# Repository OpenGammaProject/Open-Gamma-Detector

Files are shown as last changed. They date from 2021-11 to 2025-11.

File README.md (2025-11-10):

<a href="https://certification.oshwa.org/at000008.html" title="Open Source Hardware Association Certificate">Open Source Hardware Association Certificate</a>

# Open Gamma Detector

---

**This is the latest hardware revision 4.2 using the Pico 2! For older revisions, please have a look at the [other branches](https://github.com/OpenGammaProject/Open-Gamma-Detector/branches). A comparison between the 4.0 and 3.x hardware can be found [here](https://hackaday.io/project/185211-all-in-one-gamma-ray-spectrometer/log/225597-revision-40-status-report).**

**This project is also on [Hackaday.io](https://hackaday.io/project/185211-all-in-one-gamma-ray-spectrometer), where I post important project updates and other announcements!**

Open hardware for a hackable gamma spectrometer all-in-one device using a popular NaI(Tl) scintillation crystal and a silicon photomultiplier (SiPM). Extremely affordable design for a powerful DIY gamma spectroscopy setup with a total parts cost of around 200 USD if you get all the individual parts and assemble them on your own.

The detector uses a standard serial-over-USB and hardware UART connections so that it can be integrated into as many other projects as possible, for example data logging with a Raspberry Pi, weather stations, Arduino projects, etc. It includes both scintillation counter and multichannel analyzer (MCA) functions depending on how you want to use it.

<p align="center">
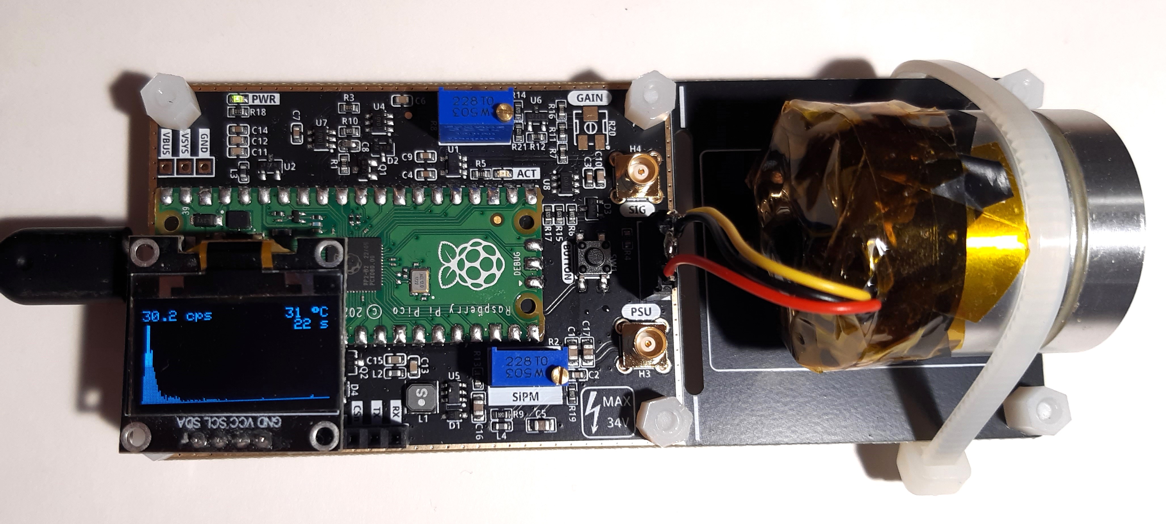
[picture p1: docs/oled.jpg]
Photo of the detector board with mounted SiPM, crystal and OLED
  
  <br>
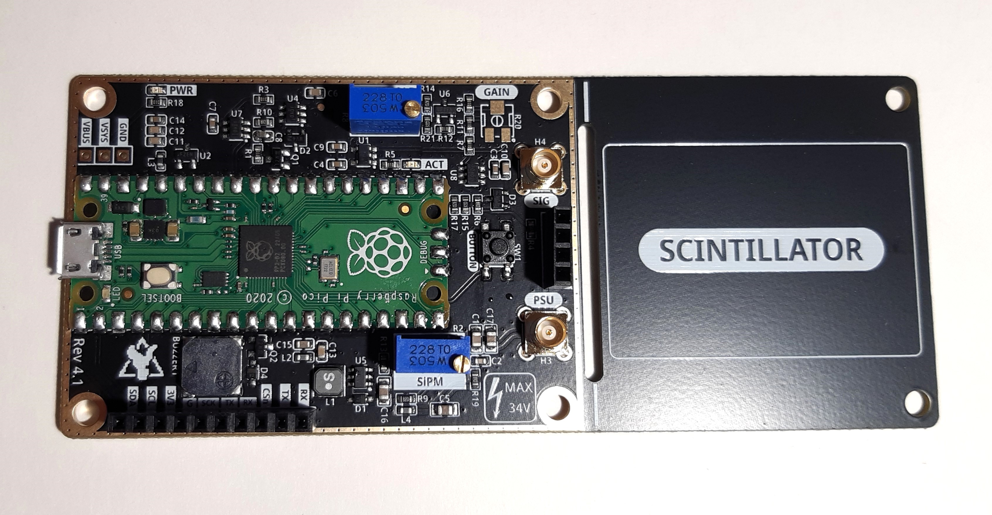
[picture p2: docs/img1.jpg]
Photo of the detector board
  
</p>

If you want a more barebones version of the Open Gamma Detector to only count pulses or similar, you can have a look at the [Mini SiPM Driver](https://github.com/OpenGammaProject/Mini-SiD) board.



## Features

Here are some of the most important specs:

- Compact design: Total size 120 x 50 mm. Approx. 70.5 x 50 mm area for electronics and additional 49.5 x 50 mm to mount a scintillator.
- All-in-one: No external parts (e.g. sound card) required to record gamma spectra.
- Standalone spectra recordings on built-in flash.
- Easily programmable using drag-and-drop firmware files or the standard Arduino IDE.
- Low-voltage device: No HV needed like with photomultiplier tubes.
- Can use SiPMs in the voltage range of 27.5 V to 33.8 V.
- 4096 ADC channels with built-in 3 V voltage reference.
- Energy resolution of up to 7% @ 662 keV possible; highly dependent on your SiPM/scintillator assembly.
- Energy Mode: ~10 µs total dead time while measuring energy (default settings).
- Geiger Mode: ~1 µs total dead time without energy measurements (default settings).
- Low power consumption: ~15 mA @ 5 V with default firmware at normal background.
- Built-in ticker (buzzer) for audible pulse count rate output.
- Additional broken-out power pins and I2C, SPI and UART headers for custom parts (e.g. display, µSD card, etc.).
- Simple OLED support out of the box (SSD1306 and SH110x).
- Built-in True Random Number Generator.

## How To Get One

PCB from PCBWay (https://www.pcbway.com/project/shareproject/Open_Gamma_Detector_84fb290d.html)

- You can check out the project on PCBWay (affiliate) and if you buy through their service, it supports the project a little, and doesn’t cost you anything extra.
- For quick access and purchase of all the parts (PCB and BOM), you can use [Kitspace](https://kitspace.org/opengammaproject/open-gamma-detector) (non-affiliated).
- Otherwise, use a PCB manufacturer and an electronics distributor of your choice and proceed on your own. All the files you'll need can be found in this repo.
- If you don't want to deal with all of that, feel free to contact me. Just send me an e-mail if you want and we'll figure something out.

**You will also need to buy a SiPM (e.g. the MICROFC-60035-SMT-TR) and scintillator (NaI(Tl) recommended) separately at a distributor of your choice.** You might also want to grab one of the countless SiPM breakout boards I made.

## Working Principle

Here is a nice flow chart to describe how the device roughly works:

Working Principle Flow Chart

## Hardware

Hardware design has been done with [EasyEDA](https://easyeda.com/) and all the needed files for you to import the project as well as the schematic can be found in the `hardware` folder. There is also a Gerber file available for you to go directly to the PCB manufacturing step.

Detailed information about the hardware of the detector as well as the potentiometer settings and assembly can be found in the [hardware directory](/hardware/).

## Software

The software aims to be as simple as possible to understand and maintain. To achieve this I decided to use an off-the-shelf microcontroller - the [Raspberry Pi Pico 2](https://www.raspberrypi.com/products/raspberry-pi-pico-2/). This board can be programmed with the Arduino IDE over micro-USB and is powerful (dual core, fast ADC, plenty of memory, ...) enough for the purpose and also exceptionally cheap.

To program the Pico 2 and/or play around with the firmware, head to the [software directory](/software/). There you will also find documentation on the serial interface (!), display support, and much more.

## Troubleshooting and FAQ

Please have a look at [REFERENCE.md](REFERENCE.md) for some general guidance.

If this doesn't help you, feel free to reach out and create an issue or open a discussions thread.

## Example Spectra

Here is a small collection of example spectra I could make quickly without putting much effort into the detector settings (threshold, SiPM voltage, software tweaks). I'm using the [Tiny MicroFC Breakout](https://github.com/OpenGammaProject/Tiny-MicroFC-Carrier-Board) and just a single SiPM (which isn't the optimal setup actually). In addition, neither the electronics nor the scintillator and sample were shielded from EMI or background radiation whatsoever. So as you can see the detector is actually pretty robust in that regard.

Background spectrum (2h) with no samples:

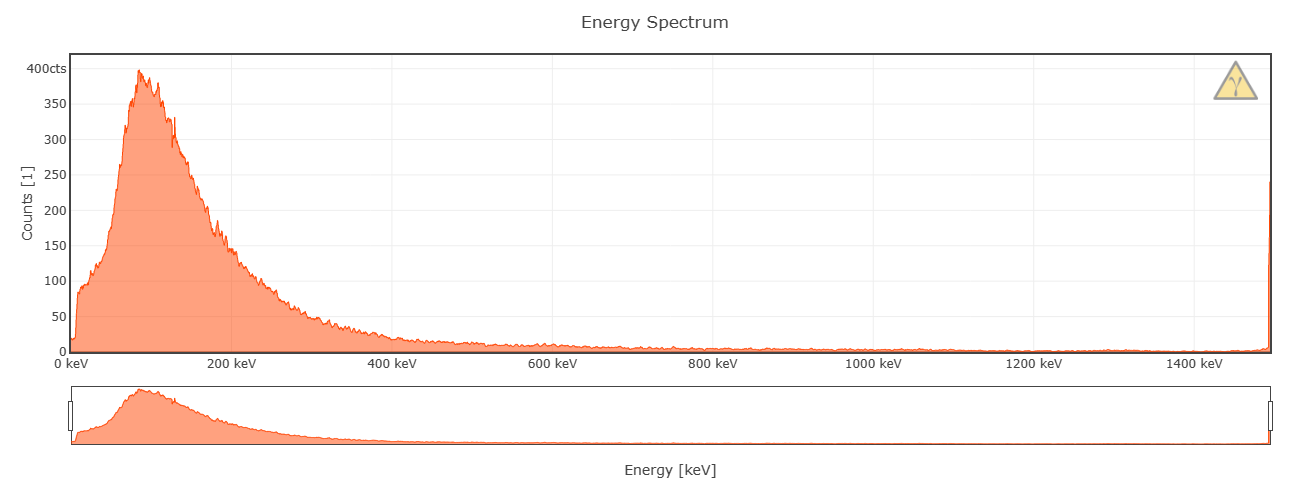
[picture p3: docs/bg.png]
Background spectrum


Spectrum (2h) of two tiny (~5 g) LYSO scintillator showing two distinct gamma peaks (201.83, 306.78 keV) with an additional ~55 keV X-ray peak. The 307 keV peak has an energy resolution of ~14% in this case:

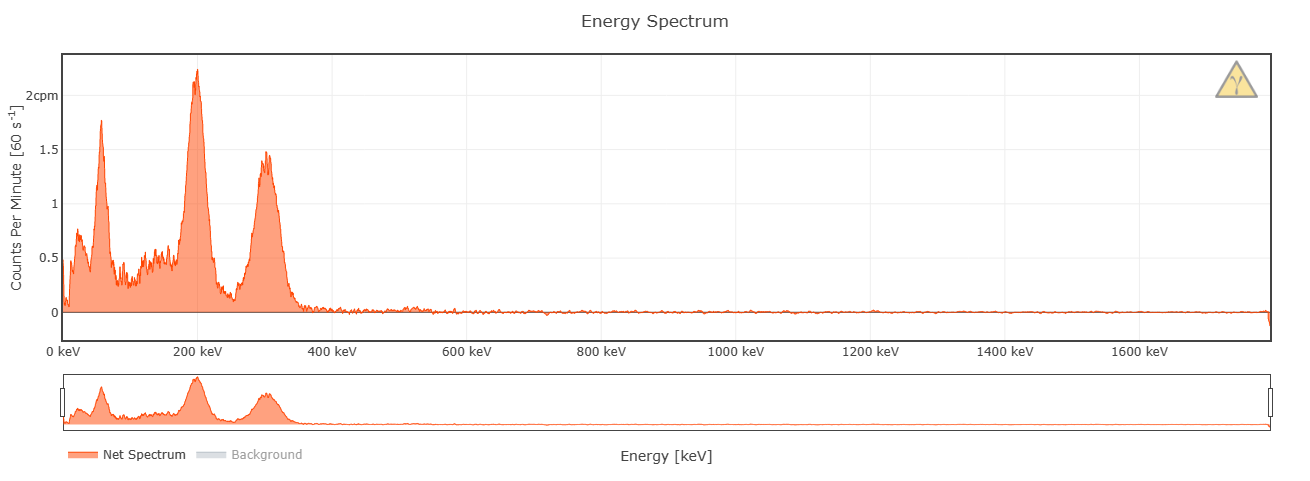
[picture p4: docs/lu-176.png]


Spectrum (5min) of Am-241 commonly used in household ionization smoke detectors (e.g. in the US, no longer in the EU). Gamma peaks at 26.34 and 59.54 keV:

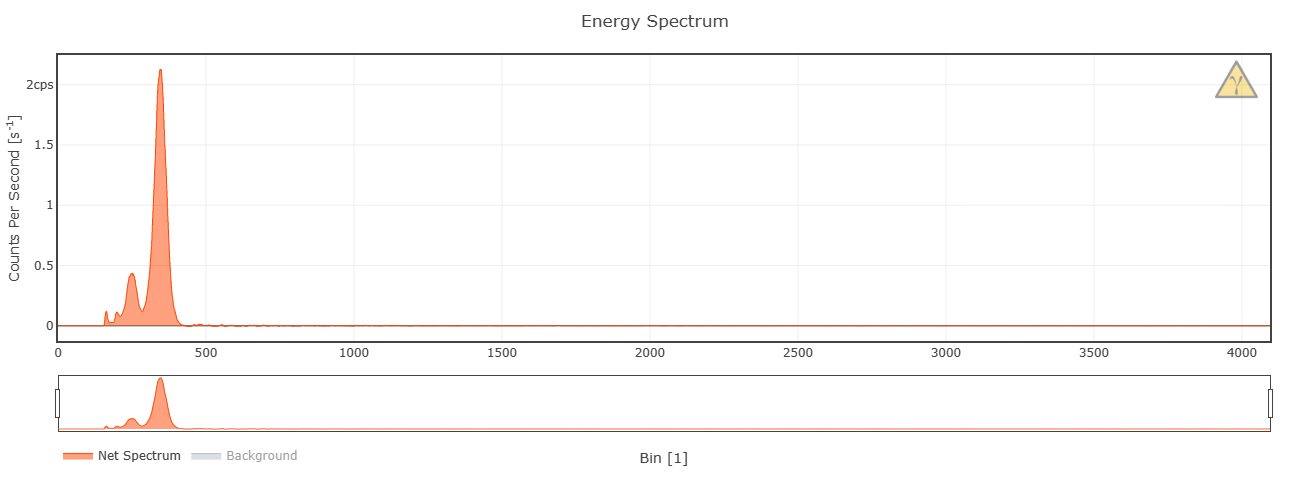
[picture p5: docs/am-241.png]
Am-176 spectrum


Spectrum (2h) of a small tea cup with pure Uraninite (also known as pitchblende) contents in its glaze. You can see all kinds of isotopes of the Uranium series including the Bi-214 peak at ~610 keV. Because they just used the pure Uraninite without any filtering whatsoever, there is also some U-235 in it and all the daughter radionuclides as well:

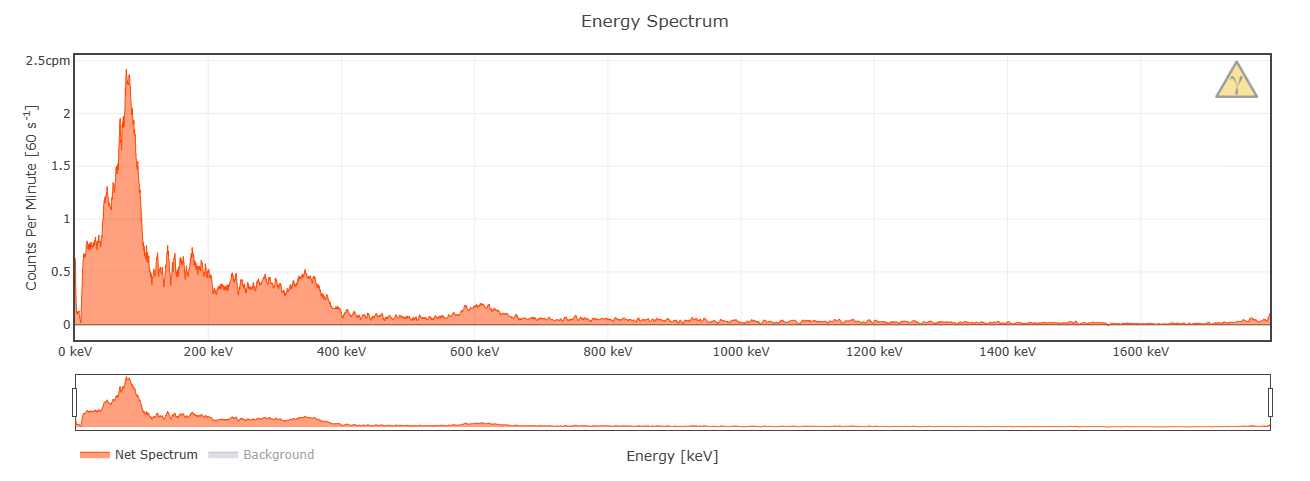
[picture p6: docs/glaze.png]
Uraninite Glaze


Spectrum (30min) of a Na-22 test source, about ~2 µCi made with a Rev.2 board (worse energy resolution than the latest version). You can see the 511 keV annihilation peak and the small 1275 keV gamma peak (much smaller due to limited NaI efficiency and small scintillator size for this energy) as well as the compton edge and continuum:

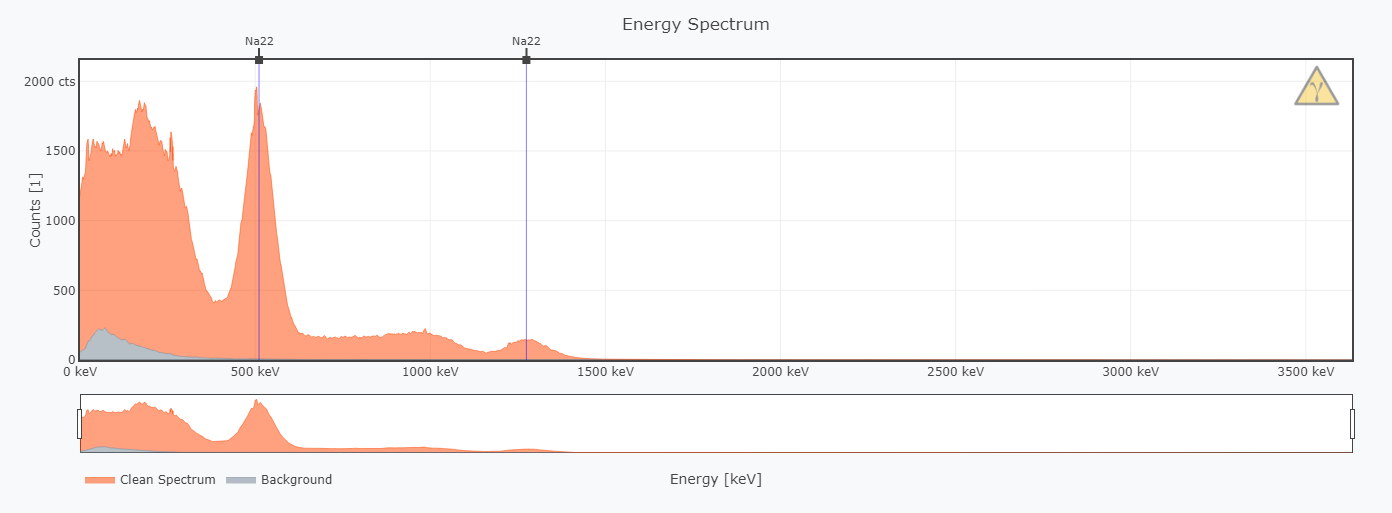
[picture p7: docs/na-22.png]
Na-22


Spectrum (2h) of about 100 grams of mushrooms still containing the isotope Cs-137 from the Chernobyl disaster. You can clearly see the gamma peak at 662 keV and the ~32 keV X-ray peak. Resolution of the 662 keV peak was ~8.6%, using only a single SiPM and an old NaI scintillator:

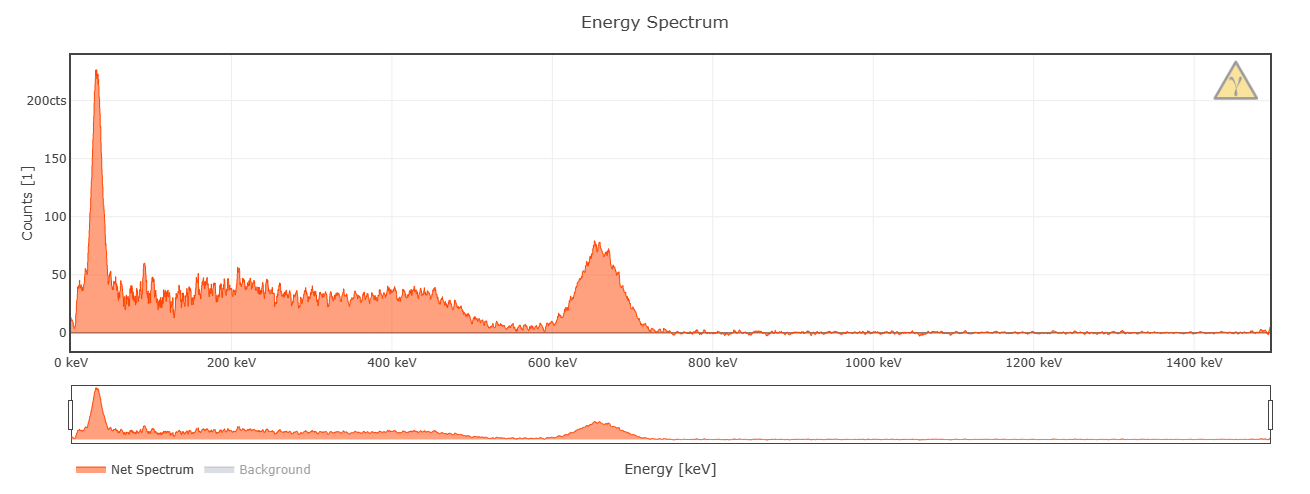
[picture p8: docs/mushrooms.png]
Mushroom "test source"


---

**Here are some of the same spectra using a larger 1x1 inch scintillator rated at 6.9% @ 662 keV and a 2x2 SiPM array:**

Spectrum (1h) of the same mushroom sample from above. This time the resolution at the 662 keV Cs-137 was 7.7%, not bad!

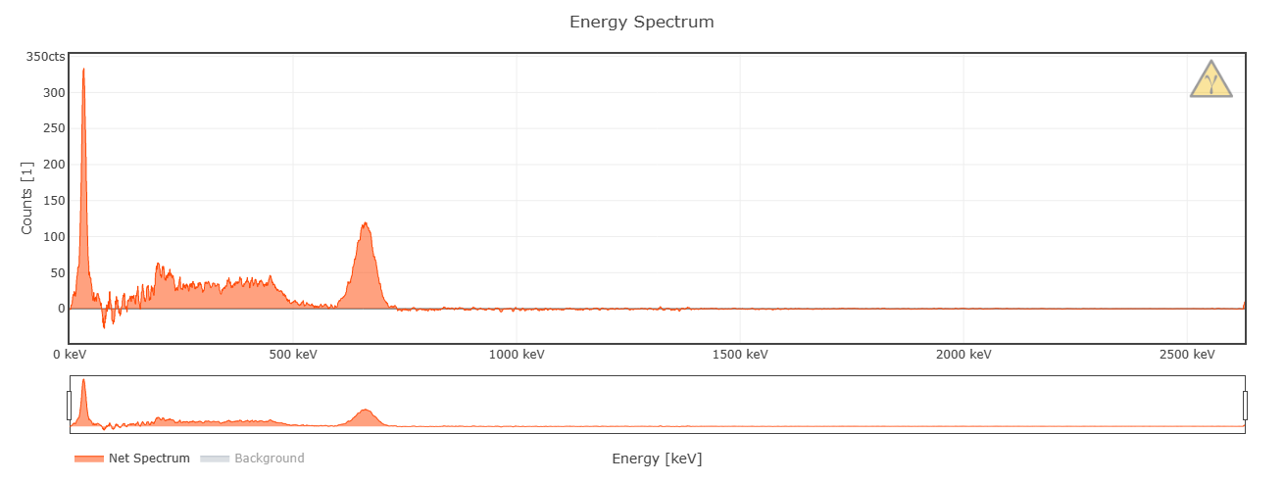
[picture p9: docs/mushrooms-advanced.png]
Mushroom "test source"


Spectrum (1h) of a small batch of Lutetium(III) oxide. It contains Lu-176 just like the LYSO scintillator sample from above. Therefore it also has the same peaks, just a lot more clear now. The 307 keV peak now has an energy resolution of 11.5%.

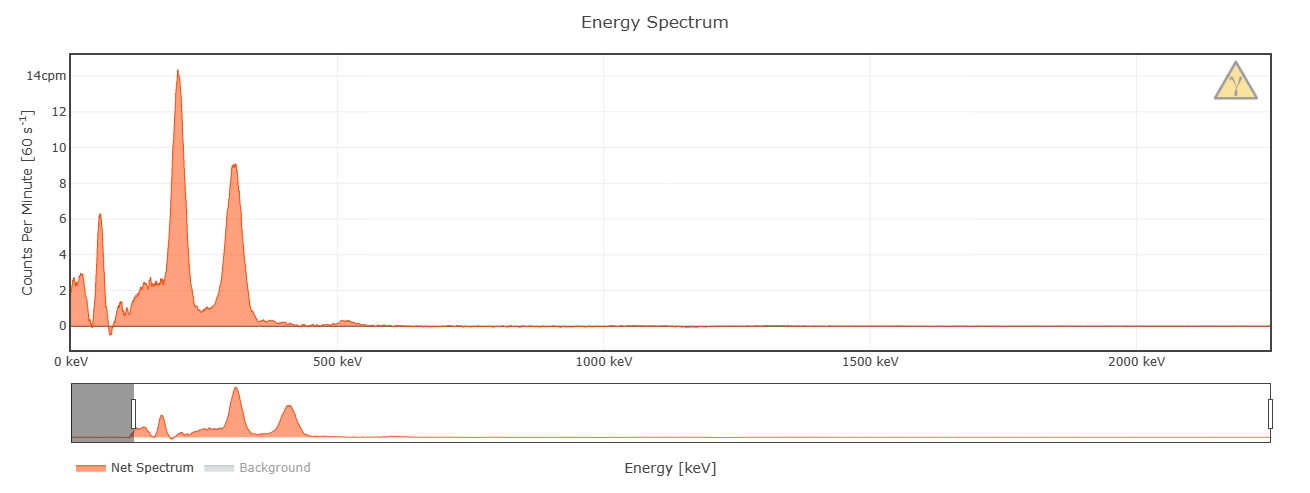
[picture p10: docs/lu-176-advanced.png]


## Known Limitations

1. ~~The Raspberry Pi Pico's ADC has some pretty [severe DNL issues](https://pico-adc.markomo.me/INL-DNL/#dnl) that result in four channels being much more sensitive (wider input range) than the rest. For now the simplest solution was to discard all four of them, by printing a `0` when any of them comes up in the measurement (to not affect the cps readings). You can turn this behavior off by using the `set correction` command. This is by no means perfect or ideal, but it works for now until this gets fixed in a later hardware revision of the RP2040 (wish us luck!).~~ Fixed by the Pico 2!
2. The power supply is **not** temperature corrected itself, meaning changes in the ambient temperature with a constant voltage affect the gain of the SiPM. This will naturally result in a different DC bias, energy range and S/N ratio. This effect is negligible around room temperature, though. The temperature dependence of the gain is -0.8%/°C (21°C) for the MicroFC SiPMs. **The latest [MicroFC SiPM carrier board](https://github.com/OpenGammaProject/MicroFC-SiPM-Carrier-Board) has automatic temperature compensation on-board however! So use that if you want to get the best performance out of it.**

## Some Ideas

### Coincidence Measurements

Using multiple detector boards with some firmware modifications it should be theoretically possible to implement a coincidence measurement feature. By respectively connecting the `VSYS`, `GND` and one of the broken-out pins to each other on both boards you have everything you need to get started. The pins would be used for an interrupt from the child detector to the parent to trigger a pulse if both timings coincide.

At the moment, though, I couldn't get a coincidence mode feature running due to some weird timing issues. There might be a firmware update in the future to implement this feature. If you have any ideas, let me know!

### Cooling the SiPM

During operation all the electronics including the SiPM naturally heat up ever so slightly. Due to the detector board (where most of the power is dissipated) not being directly connected to the SiPM self-heating is negligible, though. Therefore air or water cooling alone won't improve performance considerably, because it won't heat up much above ambient temps, if at all that is. However, you could cool the SiPM PCB with a Peltier module to sub-ambient temperatures. According to the [datasheet AND9770 (Figure 27)](https://www.onsemi.com/pub/Collateral/AND9770-D.PDF) every 10°C reduction in temperature decreases the dark count rate by 50%! But be sure to correct the SiPM voltage (overvoltage) in this case as it also changes with temperature.

Note that the required breakdown voltage of the SiPM increases linearly with 21.5 mV/°C, see the [C-Series SiPM Sensors Datasheet](https://www.onsemi.com/pdf/datasheet/microc-series-d.pdf). This means that you would also need to temperature correct the PSU voltage if you wanted to use it with considerably different temperatures.

### Shielding Background Radiation

Shielding the ambient background can be done ideally using a wide enough layer of lead (bricks) all around the detector with a thin layer of lower-Z material on the inside such as copper to avoid backscattering. The SiPM and the sample can then be put into the structure to get the best measurements possible (low background).

See Wikipedia: [Lead Castle](https://en.wikipedia.org/w/index.php?title=Lead_castle&oldid=991799816)

## Related Projects

This is a list of other awesome projects that are relevant or directly related to this one:

- [OpenDosimeter](https://opendosimeter.org/): A low-cost dosimeter with open-source hardware and software inspired heavily by the Open Gamma Detector.
- [CosmicWatch](http://www.cosmicwatch.lns.mit.edu/): A neat all-in-one device to detect muons. Completely open-source and designed for university students and schools. This project was the original inspiration to start with the Open Gamma Project.
- [OpenGammaKit](https://github.com/vikulin/OpenGammaKit/): Re-design of the Open Gamma Detector hardware using KiCAD, with additionally updated software for mobile use.

Check them out and let me know what you think. Special thanks to all of the contributors and the entire community for making this possible!

---

Thanks for reading.

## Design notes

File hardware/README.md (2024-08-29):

# Hardware

_Here you can find everything you need to build yourself a detector, or more._

This project utilizes a silicon photomultiplier (short SiPM) which is way smaller and more robust than a traditional photomultiplier tube and does not need a high-voltage supply (traditionally ~1000 V).

The following 6 mm SiPMs are recommended for this project:

* **MICROFC-60035-SMT-TR**
* MICROFC-60035-SMT-TR1 (the exact same as above, however will be more expensive to purchase as sold in smaller batches to suppliers)
* AFBR-S4N66C013 (a good replacement if the above are unavailable, but already officially EOL'd, so keep that in mind)

Here are some very helpful in-depth datasheets about the particular MicroFC SiPM recommended here:

* [C-Series SiPM Sensors datasheet](https://www.onsemi.com/pdf/datasheet/microc-series-d.pdf)
* [Linearity of the Silicon Photomultiplier](https://www.onsemi.com/pub/Collateral/AND9776-D.PDF)
* [Introduction to the SiliconPhotomultiplier (SiPM)](https://www.onsemi.com/pub/Collateral/AND9770-D.PDF)
* [Biasing and Readout of ON Semiconductor SiPM Sensors](https://www.onsemi.com/pub/Collateral/AND9782-D.PDF)

The hardware consists of the main detector (hardware in this folder) which includes amplification, pulse detection and energy measurement. If you already have a SiPM/crystal assembly compatible with voltages around 30 V, you may use it with the detector board and connecting wires directly to the correct pads. Otherwise, you can use my [SiPM carrier board](https://github.com/OpenGammaProject/MicroFC-SiPM-Carrier-Board), which holds the SiPM and all the optional decoupling as well as a temperature compensation circuit for the SiPM. There is also a carrier board for the Broadcom SiPM.

The heart of the detector board is the Raspberry Pi Pico 2 which uses its ADC to measure the pulse amplitude (i.e. the energy) immediately after an event occurs starting with an interrupt. I can really recommend you reading the datasheet ~~or maybe also having a look at a deeper analysis of the Pico ADC~~ (only relevant to Pico 1), if you're interested:

* [Raspberry Pi Pico 2](https://datasheets.raspberrypi.com/pico/pico-2-datasheet.pdf)
* ~~[Characterizing the Raspberry Pi Pico ADC](https://pico-adc.markomo.me/)~~ (only relevant to Pico 1)

Here are some front and back side renders of the detector PCB. Size is about 120 x 50 mm. If you don't need the additional space to mechanically mount the SiPM/scintillator assembly to the rest of the detector board, you can just cut it off at the white line and you're left with an even smaller detector.

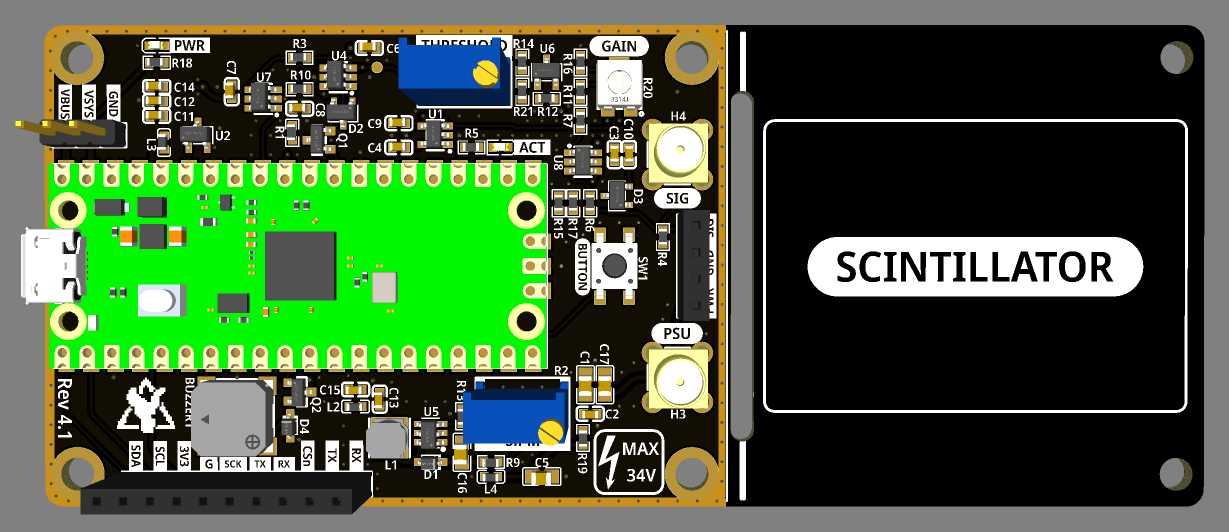
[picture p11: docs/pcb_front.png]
Front Side PCB


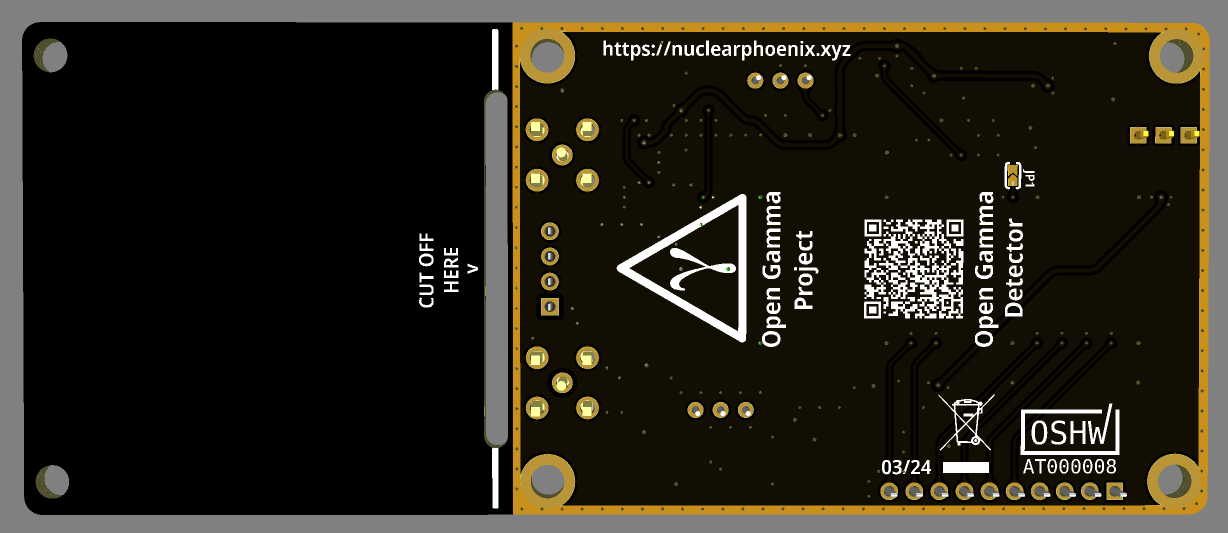
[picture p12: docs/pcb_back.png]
Back Side PCB


On the back side of the PCB there is also a jumper to connect the analog ground to the rest of the ground plane. You can solder that if you want to and you know exactly what you're doing. It's not needed, though, that's why it's open by default.

There are also broken-out pins for the power supply, I2C, SPI and UART connections. These can be used to modify the device, e.g. by adding a display or using a battery charger. You can have a look at the great [Raspberry Pi Pico 2 datasheet](https://datasheets.raspberrypi.com/pico/pico-2-datasheet.pdf) for more info on this.

Some more info on the peripheral headers can be found in the `software` section of this project.

## Pinout

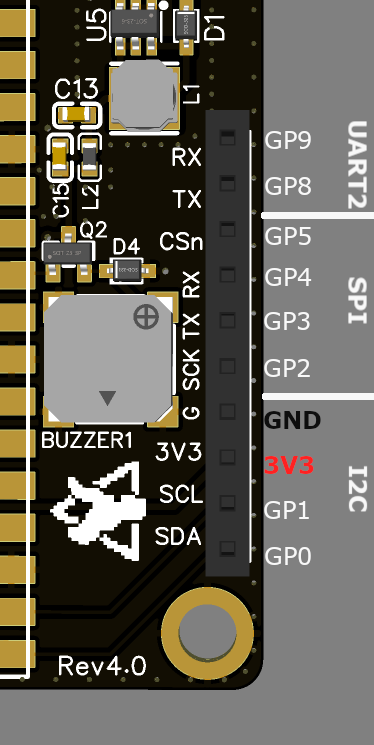
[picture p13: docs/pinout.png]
Header Pinout


You can also put a little jumper from `VBUS` to `VSYS` if you **only** want to use the detector with the USB connection on the Pico. This bridges the diode on the Raspberry Pi Pico 2 and saves you a couple of mW.

As for the **SiPM connections**, there is a female 2.54mm pin header on the board and also two MCX jacks. The pin headers are just a very easy way to get everything up and running and are fine if you're not really touching them and the scintillator is mounted very close to the header (i.e. on the PCB).

If you want to have a more secure and more importantly shielded way of connecting the SiPM, use MCX cables and the corresponding jacks on the board. There are special MCX breakout cables that have the connectors on one end and then terminate to some stranded copper wire on the other side. You can use this to solder the cable directly to the SiPM breakout board and then have the plug on the other side. However, because you need two cables (one for power and one for signal), be sure to keep them as close together as possible (e.g. twist them together) as to not create a huge ground loop area.

## Potentiometers

Here is a helpful image about the potentiometer settings for revision 4.x:

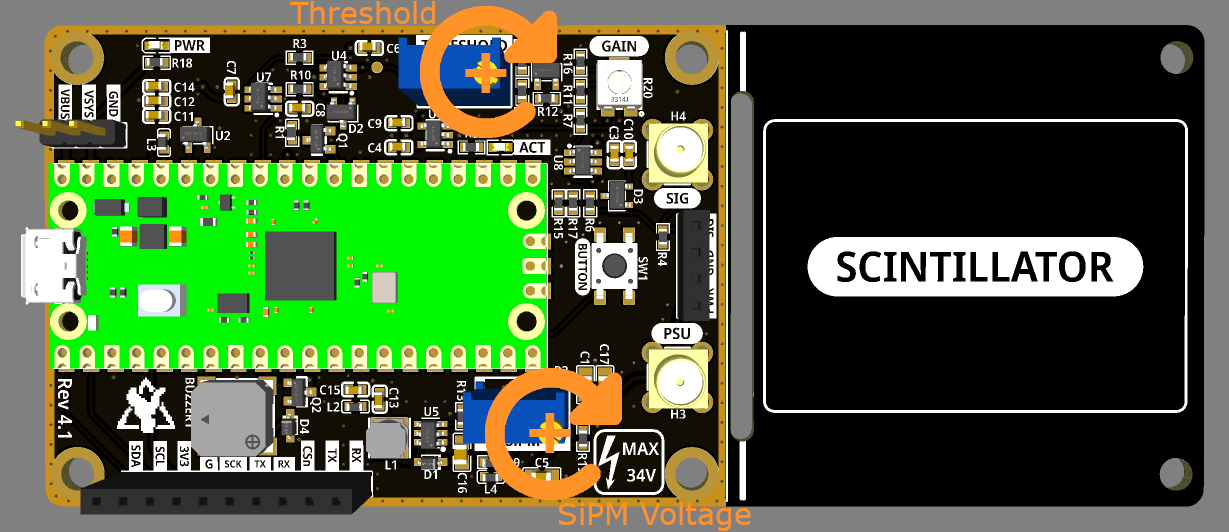
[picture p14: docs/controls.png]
Potentiometer Controls


As you can see it is pretty simple to set the required voltage and threshold. **Just turn any potentiometer clockwise to increase the corresponding parameter, turn anti-clockwise to decrease.**

## Buttons

There are two buttons on the device:

* A small one on the Raspberry Pi Pico 2 itself that is only used to reboot the device into bootloader mode. This is handy if you want to change or update the firmware of the device.
* A larger one next to the Pico that is used to toggle between spectrum and Geiger mode by **short-pressing** (<1 second) and toggling the buzzer by **long-pressing** (>=1 second) it.

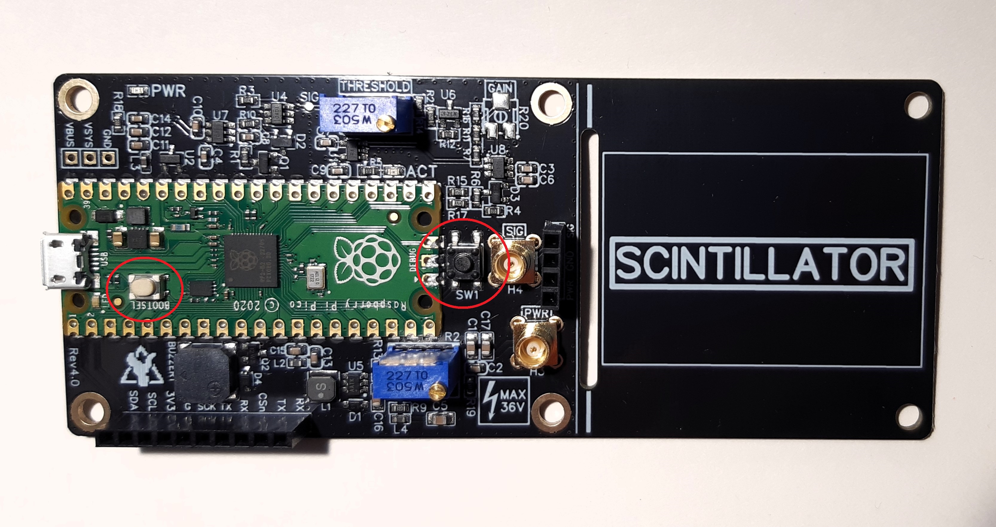
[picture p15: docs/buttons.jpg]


## Scintillator (Assembly)

The finished [standard MicroFC-](https://github.com/OpenGammaProject/MicroFC-SiPM-Carrier-Board), [tiny MicroFC-](https://github.com/OpenGammaProject/Tiny-MicroFC-Carrier-Board) and [AFBR-](https://github.com/OpenGammaProject/AFBR-SiPM-Carrier-Board) SiPM carrier boards are there to allow for easier packaging with the scintillator as well as to be reusable for different detectors as that's by far the single most expensive part and you'll want to use it as long as possible.

If you are using a larger-diameter scintillator, it's probably better for you to use something like the [MicroFC SiPM Array Board](https://github.com/OpenGammaProject/MicroFC-SiPM-Array-Board), which has a 2x2 matrix of SiPMs resulting in 4x the active area. **This will increase the energy resolution for large crystals.**

### Scintillator Cyrstals

I got most of my scintillators (used NaI(Tl), LYSO, ...) on eBay. Just search for some keywords or specific types, you'll probably find something. Just be sure to look out for signs of wear and tear like scratches on the window or yellowing (!) in NaI crystals as these can deteriorate performance significantly.

You can obviously also buy brand-new scintillators, however, these can be much more expensive. It really depends on the manufacturer there. You can get some cheap 1" x 1" NaI(Tl) scintillator from China for <100 USD.

Two sources of new NaI(Tl) scintillators are:

| Brand | Location | Comment |
|---|---|---|
| [OST - Photonics](https://www.ost-photonics.com/products/scintillation-crystal/encapsulated-scintillator/standard-type-naitl-scintillator/) | China | Can purchase directly from website |
| [Epic-Crystal](https://www.epic-crystal.com/) | China | Also sold by [GammaSpectacular](https://www.gammaspectacular.com/) |

**Since this is a fixed-gain device, I can only highly recommend you to get a scintillator that fits on the PCB and is of a comparable volume as the scintillators I tested.** I am using an 18 x 30 mm crystal for most of the spectra that you can see here and it works great. Also, due to the small size of the SiPM in comparison to the scintillator opening, try to use narrower crystals than wider ones if you can. That way, there aren't many light losses to the SiPM. In general, just be sure the volume/size is not orders of magnitue larger or smaller. If that's not possible, consider using the array board. **The array board works great with a 1" x 1" NaI(Tl) with this detector for example. There is also an optional trim pot for the gain on the Rev. 4 boards that you can solder and use to change the preamp gain.**

If the scintillator is too small, the output voltage will be very low and you might get restricted by the ADC resolution. In this case the energy range will also be much higher than you would ever need (can easily get up to 10 MeV).

If the scintillator is too large, the output voltages will be pretty high and thus decrease your energy range dramatically. The device is limited by the 3.0 V reference voltage in this case, so you might see clipping. Your mileage my vary.

**As a general rule of thumb, try to use as much of the space available on the PCB as possible to mount the scintillator and you will (in most cases) be absolutely fine.**

### Index-Matching Material For Coupling

You should apply some optical coupling compound between the SiPM and the crystal window to reduce reflections as good as possible (this way the best photon detection efficiency is achieved). There a multitude of options for optical couplants, and depending on your region some may be easier to aquire than others. As a general rule of thumb, silicone oil/grease can also be used and works fine. If it contains polydimethylsiloxane, you're on the right track. Some options:

<!---This is a good source https://www.logwell.com/tech/servtips/optical_coupling_grease.html - Sebyon --->

| Description | Brand  | Reflective Index | Viscosity (cPs)| Cost (USD) | Comment |
|---|---|---|---|---|---|
|[Index Matching Gel, 3 cc](https://www.thorlabs.com/thorproduct.cfm?partnumber=G608N3)|Thorlabs| 1.43 | 1,060,000 | $47.46 | High viscosity, works well for fibre optic coupling. |
|[Index-Matching Fluid](https://www.newport.com/f/index-matching-fluid) | Newport | 1.52 | 100 | $45.60 | Low viscosity may make setting the SiPM and crystal window difficult. However, the RI is the closer to the window properties. Use if you're experienced with assembly. |
|XIAMETER™ PMX-200 Silicone Fluid | Dow Corning | 1.40 | 60,000 - 100,000 | Depends on source | Low cost and [used in research](https://pubs.acs.org/doi/10.1021/acs.cgd.0c00256) due to performance / price. PMX-200 can come in various viscosities, try to get close to 100,000 cPs. |
|Molykote Industrial 4 Electrical Insulating Compound | Dow Corning | N/A | Grease | ~$20 | Used by Ludlum for their survey meter scintillation detectors. |

<!--- I might add some more options for achieving a hermatic seal with tape here once I start putting one together - Sebyon --->

After you applied some, you press both parts together and wrap everything with light-tight tape, again, I'm just using some black electrical tape here. That's essentially it, now you can solder some wires to the pads on the board to connect them together and secure it in place in the free space on the board.

**It's very important to get the SiPM/scintillator assembly light-tight.** Otherwise you'll either run into problems with lower energies where noise dominates or outright not measure anything at all, because the sensor is saturating (clipping signals).

**==> More assembly instructions can be found on the [Hackaday.io project page](https://hackaday.io/project/185211/instructions)!**

## The `ACT` LED

There is an additional LED on the board called `ACT` for "activity". It's directly connected to the comparator that handles the pulse thresholds and will light up for every impulse that's larger than the set threshold voltage for the duration of said impulse. That means generally you won't see much, because the count rates are pretty low and the pulses are really fast (couple of microseconds).

However, it's helpful when setting the correct threshold voltage, because as soon as you decrease it too low and completely get into the noise floor, the LED will visibly light up.

On top of that, since it's not connected to the microcontroller in any way, it's a nice backup for when the device crashes and/or the count rates get so high that it's completely saturating otherwise. **The detector will display ZERO counts per second when it saturates at very high count rates: the count rate will actually gradually go down to zero the higher and higher your ACTUAL (real) count rate is.** So if the device displays 0.0 cps, but the LED is lit up brightly, you either have a light leak or you should run for your own safety.

## 3D Printed Case

You can get a 3D-printable case for the Open Gamma Detector with different styles of covers.

All the STL files to print the two parts (main body and cover) can be found in [/enclosure](../enclosure), as well as some more info on the necessary screws and the USB extension cable.

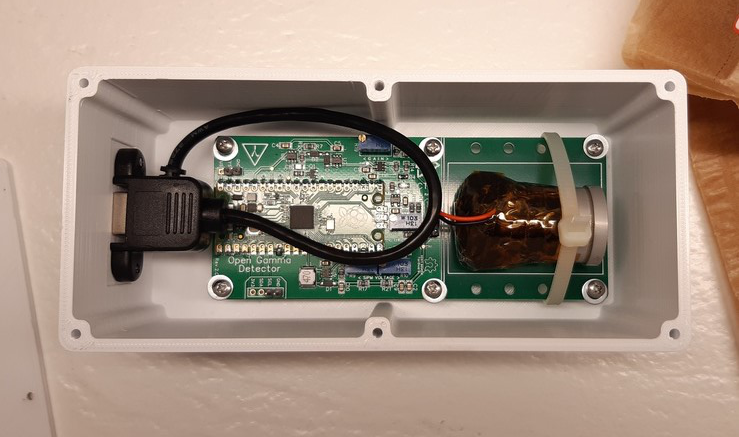
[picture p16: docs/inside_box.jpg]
Inside view of the box


(This is an old image from Revision 2.0, but the footprint is exactly the same, you get the gist.)

## Shielding

Due to the detector measuring small voltages, energy resolution being limited by noise and a small 470 pF capacitor being on board, it can sometimes be pretty sensitive to EMI. For the absolute best performance, you should put your detector into some kind of metal enclosure. It doesn't need to be a thick metal case, a tin can will most likely suffice.

<!--- Once I start assembly I'll look at proving some shielding ideas - Sebyon --->

The four screw holes on the PCB's actual detector part are connected to the circuit GND.

As some level of protection against EMI, the peak and hold capacitor is periodically discharged as to avoid it being charged ever so slightly by interference and the feedback path. This takes place every millisecond by default and cannot be switched on or off via a serial command. This adds less than 1% of additional dead time (~2.5 µs per reset every ms), so should be completely negligible.

## Raspberry Pi Pico 2 W

Since the Pico 2 W has functionally the exact same size and pinout, it can be a trivial replacement for the standard Pico 2. This can be a great place to start experimenting with connecting to the Open Gamma Detector via Bluetooth or WiFi, there are endless possibilities what you can do with that.

If you switch to the Pico 2 W, though, you will need to modify the stock firmware slightly since internal pins like the input voltage pin are changed.

There is also no firmware build for the Pico 2 W and I don't plan to make one in the near future, since I'm busy enough with the stock firmware, hardware and Gamma MCA, to start building yet another Bluetooth- or WiFi-connected app or whatever.

I'll happily accept PRs if you make something like that, though, so let me know! ;)

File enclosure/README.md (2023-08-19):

# Enclosures

In the following folders you can find different enclosures for the Open Gamma Detector.

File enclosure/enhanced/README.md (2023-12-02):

# Parts List

Here are all the parts you need to build this 3D printed enclosures. It's compatible with the Open Gamma Detector Rev. 2, 3 and 4 and also a lot more handy and smaller than the simple case.

The case is designed to fit a scintillator with a maximum size of 5 x 5 x 5 cm. The USB connection can be accessed through a hole in the front.

You can have a look at all the different designs by uploading them to [ViewSTL](https://www.viewstl.com/).

All of the design work has been done by [@sebyon](https://github.com/sebyon), many thanks!

---

<p align="center">
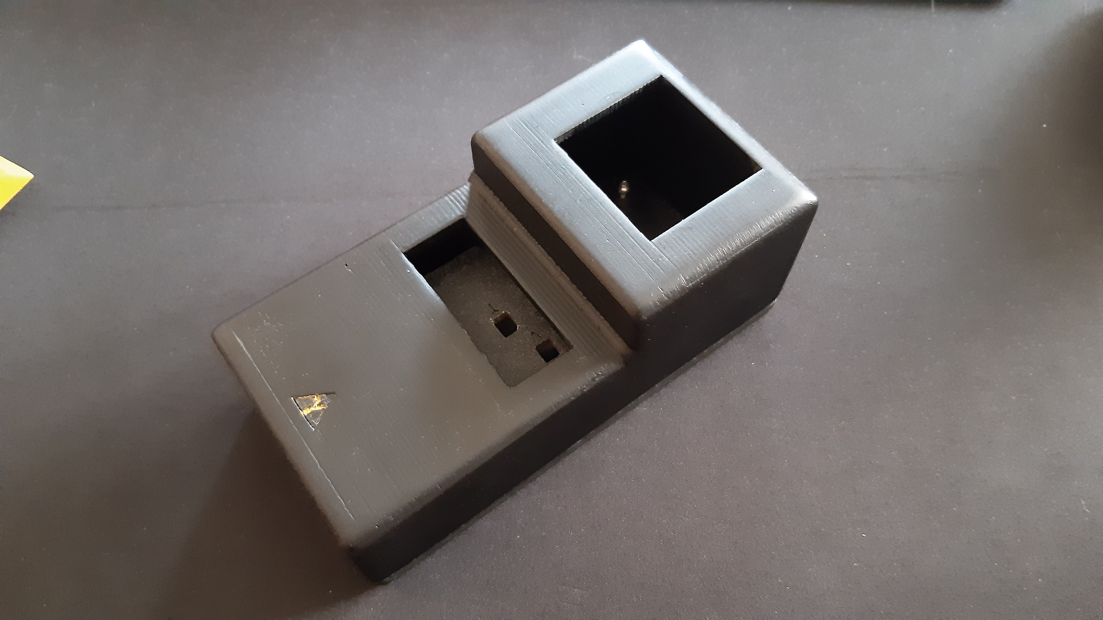
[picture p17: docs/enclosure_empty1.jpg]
	
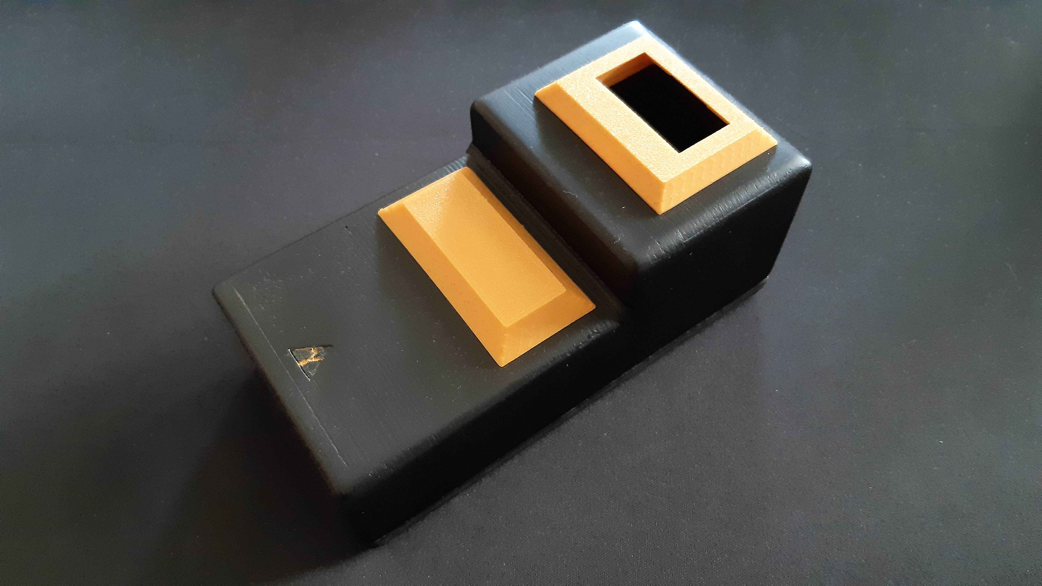
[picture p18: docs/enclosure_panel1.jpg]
	
</p>

<p align="center">
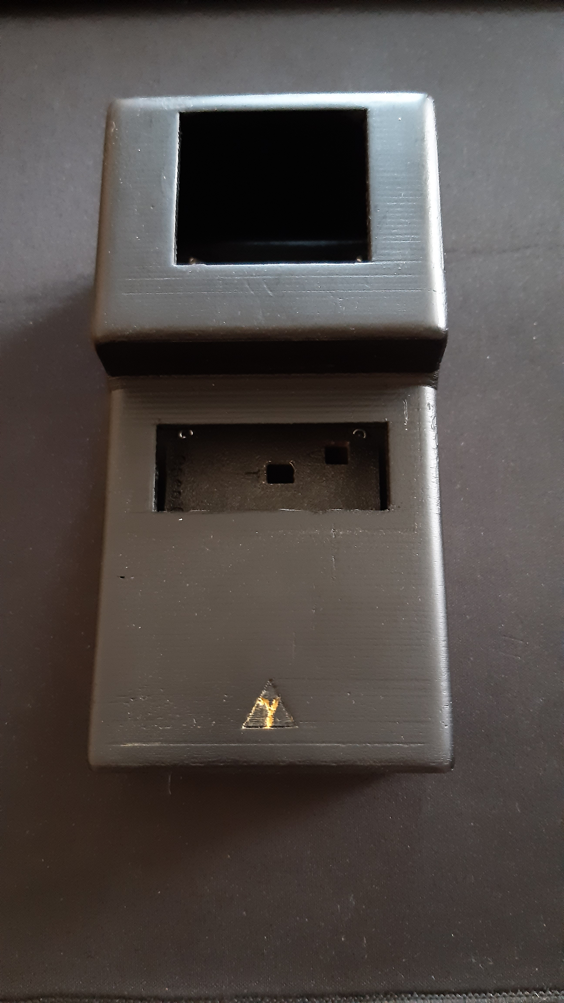
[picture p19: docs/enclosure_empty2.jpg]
	
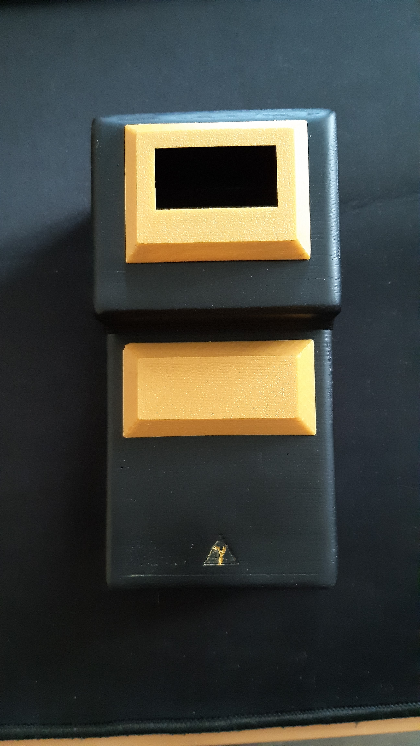
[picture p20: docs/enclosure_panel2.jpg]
	
</p>

## Main Body

These are the `Case_Lower.stl` and `Case_Upper.stl` files.

- 10 x M3\*5.7\*4.6 Threaded Heatset Inserts
- 10 x M3\*10mm screws

## Inserts

The plug-in inserts for the display and the panel/buttons are called `LCD_Bezel.stl` and `Panel_Cover.stl` respectively.

These are just friction fits and aren't screwed. The LCD cover is designed for a 1.3 inch OLED display (SH1106). The panel cover can be replaced by a custom made cover that fits your needs, e.g. for buttons.

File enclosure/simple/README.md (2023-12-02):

**For a reference 3D model, you can have a look at the `3D` folder. It contains some `mtl` and `obj` files if you want to design your own enclosure.**

# Parts List

Here are all the parts you need to build all the different 3D printed enclosures. These are all compatible with the Open Gamma Detector Rev. 2, 3 and 4.

The case is designed to fit a scintillator with a maximum size of 5 x 5 x 5 cm. The USB connection will be extended to the outside via a short USB panel mount cable.

You can have a look at all the different designs by uploading them to [ViewSTL](https://www.viewstl.com/).

All of the design work has been done by WEDBox, [box@wed.ch](mailto:box@wed.ch), many thanks!

## Main Body

### PCB Mount

6 x M3x10 mm Flat Head (not countersunk!)

### USB Panel Mount

Example: [https://www.aliexpress.com/item/4000932328047.html](https://www.aliexpress.com/item/4000932328047.html) or [https://www.aliexpress.com/item/4001250794678.html](https://www.aliexpress.com/item/4001250794678.html)

Cable Length: 30 cm

2 x M3x10 mm Flat Head (not countersunk!)

## Case Cover

### All Models

6 x M3x15 mm Countersunk Head Screw

#### Handle Variant

Example: [https://www.aliexpress.com/item/4000012656240.html](https://www.aliexpress.com/item/4000012656240.html)

Distance between holes: 96 mm

2 x M4x15 mm Flat Head (not countersunk!)

#### Window Variant

Acrylic glass, max. 1.5 mm thick, size 132x48 mm

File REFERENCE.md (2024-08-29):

# Troubleshooting and FAQ

## Troubleshooting

### My device freezes or crashes periodically

Make sure that the threshold setting is not set too low! If that's the case you should see the ACTivity LED blinking heavily or even staying on solid. The buzzer might also give you a great indication of the correct count rate setting. In this case, noise is probably overwhelming the detector and forcing it to reset.

If this is not the case for you, reflash the firmware, reset all the settings and reboot the device. If the problem persists, please feel free to open an issue on GitHub.

### My device is not recognized by my computer

Make sure you are using a micro-USB cable that can be used for data transmission! There are micro-USB cables for powering/charging devices only and they can be easily mistaken for a data cable.

If this isn't the case for you and it doesn't get recognized at all (even while holding the `BOOTSEL` button), there might be a manufacturing defect or you might have made a mistakes when soldering the parts. Feel free to get in touch if that's the case.

### Settings on the device are not saved

If you flashed it via the Arduino IDE be sure to select `Flash Size: "4MB (Sketch: 1MB, FS: 3MB)"`. Without these 64 KB of flash assigned to the file system, the Pico is unable to create and save a settings file.

### ~~I am seeing a sharp peak immediately around ADC channel 511~~

~~That is right, this is due to the DNL issues with the RP2040 ADC as described in the [Known Limitations](README.md#known-limitations) section of the readme.~~

~~This effect would have been much worse without some simple corrections in the firmware. Since there is currently no hardware fix, this is what we have to live with unfortunately. If you know about it, you can just ignore it since all the *real* peaks of the scintillator are much wider than that.~~ Fixed by the Pico 2.

### ~~There is always a peak at ADC channel 0~~

~~That is intentional behavior of the device. For the same reason as above, four ADC channels are ignored for the energy measurement.~~

~~Since this would potentially highly influence the count rate, giving lower values than there actually are, these counts are added back to the spectrum to ADC channel 0.~~

~~This way, all the counts are registered, but since there is actually never a signal near channel 0, you can clearly distinguish between the "right" spectrum and the rest.~~

~~If you want to disable this behavior, you can do so by using the  `set correction` command over the serial interface. This will still omit the ADC channel readings, but won't create another peak at 0. In geiger mode, there will always only be a channel `0` since this is how the current cps is calculated.~~  Fixed by the Pico 2.

### There is always a peak near ADC channel 4095

The ADC reference voltage is set to 3 Volts. Anything larger than that gets clipped, because the ADC cannot read higher voltages, meaning all pulses larger than 3V accumulate at the maximum ADC channel -- in this case 4095. That is completely normal behavior.

---

## FAQ

### How to update the firmware?

Press and hold the "BOOTSEL" button on the Raspberry Pi Pico while plugging it into your USB port. It will then show up in your file explorer and you can once again drag-and-drop the firmware file. This also works if your device is completely frozen or crashed.

### Can I use a plastic scintillator?

No, these cannot be used for gamma spectroscopy except in some edge cases. Generally, they have much worse efficiency than your typical inorganic scintillator, like NaI(Tl) or CsI(Tl), and extremely poor energy resolution.

If you want to *just* count pulses (i.e. **not** measure pulse energy), plastic scintillators can be a better fit, because of their really low cost. If you want to count pulses only, though, it's probably better to use the simpler and much cheaper [Mini SiD](https://github.com/OpenGammaProject/Mini-SiD) board instead of the Open Gamma Detector. With plastic scintillators you can also detect high-energy particles such as beta radiation or muons, which NaI(Tl) generally cannot.

### How do I change the gain?

Since hardware revision 3 the gain is fixed on all boards and cannot be changed without any hardware modifications. This makes it **much** easier to provide a device that has a very high chance of working out of the box without much fiddling around with pot settings or additional components.

A downside of this is that different scintillator sizes, while working most of the time now, provide slightly different energy ranges and therefore bin per energy resolutions. Normally, this shouldn't be a problem, though.

If you want to change the gain for whatever reason, you can do so by soldering the optional trim pot on the board (R20) with a [compatible pot (e.g. 5k)](https://www.lcsc.com/product-detail/Variable-Resistors-Potentiometers_BOURNS-3314J-1-502E_C58391.html). Be sure to also remove the existing 0605 resistors R7 and R11 in that case. You can then change the gain from roughly 1 to 6 on the fly.

### How do I calibrate the device?

You have to get a material with at least two known gamma peaks and calibrate the detector using these two peaks. In the Gamma MCA calibration tab you select the two peak ADC channels and assign their gamma-ray energy.

Ideally you want to use three peaks distributed evenly over your whole energy range to use the best calibration.

### Why don't you use a TIA or CSP or change X or Y?

This device is made to be as simple and cheap as possible, while still yielding as great results as possible. In effect it is a compromise to get the best price-performance ratio.

Of course, you could use transimpedance or charge-sensitive preamplifiers, however this would significantly increase complexity as you'd need additional parts for the correct power supplies and so on. Using more expensive amplifiers would surely also be an option.

If you wanted to go the maximum-performance route, you'd also need to use a different microcontroller with a much better ADC, and maybe even consider using 4-layer boards with additional ground and power planes. Essentially, you'd have to re-design the whole board at this point.

Instead of something like 8-10% energy resolution @ 662 keV (highly dependent on your SiPM/scintillator assembly), you'd then maybe get as much as 6% if you're lucky, which is the limit for most NaI or CsI scintillators anyways. That would come at a much higher cost, though. In my opinion, you get to a point of diminishing returns quickly, especially when designing an entry-level device such as this.

### Notes on different microcontrollers

The Pico 2 is readily available virtually everywhere and it's really cheap. This makes it ideal for use in this kind of "simple" and cheap project. There are a couple of reasons I like to use it. You can read more about it in the [discussions thread about switching to the ESP32](https://github.com/OpenGammaProject/Open-Gamma-Detector/discussions/43).

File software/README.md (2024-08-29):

# Software

**If you just want to program you device with all the default settings, choose one of the `.uf2` files in this directory. This will be all you need if you just want to get going!**

If you want to play around with the firmware, the Arduino sketch can be found inside `ogd_pico`. It also includes some instructions on how to program. See below for more info about that.

**Note about HW compatability:** Each hardware revision of the detector has its own major version of the Arduino sketch indicated by the leading number of the version code. The versions are only tested on their respective hardware, so they might and probably will not work with newer or older detector boards. As an example, FW **4**.0.2 is designed to only run on Rev. **4** boards, while **3**.5.2 is only designed to run on Rev. **3** boards.

## Programming the Pi Pico 2

### Firmware Files

This is the easiest way to get started! You'll not have to download anything else besides the firmware UF2 file. This is the latest default firmware that you can use if you don't plan to modify any of the hardware aspects (such as the voltage reference, ADC resolution, etc) on the board itself. You can of course also use it with the Open Gamma Detector purchased from my Tindie store.

To get started with a fresh device, plug in the Raspberry Pi Pico 2 via the micro-USB connection. A file manager window should now pop up. Drag and drop the `ogd_pico-XXX.uf2` file that you downloaded into this directory. The device will restart automatically once the transmission is completed and is ready to use!

If you want to update or re-flash the firmware, press and hold the `BOOTSEL` button on the Raspberry Pi Pico 2 _while_ plugging it in the USB port of your computer. A file manager windows should once again pop up and you can let go of the button. Drag and drop the UF2 file just like above.

### Arduino IDE

To program the Pico you will need the following board configs in the latest release of the Arduino IDE:

- [Arduino-Pico](https://github.com/earlephilhower/arduino-pico)

The installation and additional documentation can be found in the respective GitHub repo, it's not complicated at all and you only need to do it once. You will also need the following additional libraries:

- [TaskScheduler](https://github.com/arkhipenko/TaskScheduler) 
- [SimpleShell Enhanced](https://github.com/NuclearPhoenixx/SimpleShell) 
- [ArduinoJson](https://github.com/bblanchon/ArduinoJson) 
- [Adafruit_SSD1306](https://github.com/adafruit/Adafruit_SSD1306) 
- [Adafruit_SH110x](https://github.com/adafruit/Adafruit_SH110X) 
- [RunningMedian](https://github.com/RobTillaart/RunningMedian) 

They can be installed by searching their names using the IDE's built-in library manager.

Please have a look at the `USER SETTINGS` in the Arduino sketch. You might need to change the default display parameters, such as I2C address, screen width and height depending on what display you are using.

Flash the Pico by choosing the `Raspberry Pi Pico 2` under `Board: Raspberry Pi Pico/RP2040` and then selecting `Flash Size: 4MB (Sketch: 1MB, FS: 3MB)`, leaving everything else at the default value. You can then press the big `Upload` button.

You can also try to **overclock** the device if you want. You cannot destroy anything as far as I know, so be experimental. The worst thing that can happen is the Pico locking up and you needing to reflash it by holding the `BOOTSEL` button. Mine ran stable at up to 250 MHz with reduced core voltage (66% increase from stock!!!) and that will actually significantly improve the detector dead time as well. Also flashing with `-Ofast` enabled improved performance for me too. There is a more detailed comparison on this [for the Pico 1 on Hackaday](https://hackaday.io/project/185211-all-in-one-gamma-ray-spectrometer/log/213190-pico-performance-improvements), performance changes might be different for the Pico 2 though.

## Serial Interface

You can control your spectrometer using the serial interface. The following commands are available, type `help` to get a list of commands. Commands are case sensitive. Additional parameters needed for each command are surrounded by `< ... >`.

```text
> help
Usage:
	<command> [options]
Commands:
	read spectrum	: Read the spectrum histogram collected since the last reset.
	read settings	: Read the current settings (file).
	read info		: Read misc info about the firmware and state of the device.
	read fs			: Read misc info about the used filesystem.
	read dir		: Show contents of the data directory.
	read file		: <filename> Print the contents of the file <filename> from the data directory.
	remove file		: <filename> Remove the file <filename> from the data directory.
	set baseline	: <toggle> Automatically subtract the DC bias (baseline) from each signal.
	set trng		: <toggle> Either 'on' or 'off' to toggle the true random number generator output.
	set display		: <toggle> Either 'on' or 'off' to enable or force disable OLED support.
	set mode		: <mode> Either 'geiger' or 'energy' to disable or enable energy measurements. Geiger mode only counts pulses, but is a lot faster.
	set out			: <mode> Either 'events', 'spectrum' or 'off'. 'events' prints events as they arrive, 'spectrum' prints the accumulated histogram.
	set averaging	: <number> Number of ADC averages for each energy measurement. Takes ints, minimum is 1.
	set tickrate	: <number> Rate at which the buzzer ticks, ticks once every <number> of pulses. Takes ints, minimum is 1.
	set ticker		: <toggle> Either 'on' or 'off' to enable or disable the onboard ticker.
	record start	: <time [min]> <filename> Start spectrum recording for duration <time> in minutes, (auto)save to <filename>.
	record stop		: Stop the recording.
	record status	: Get the recording status.
	reset spectrum	: Reset the on-board spectrum histogram.
	reset settings	: Reset all the settings/revert them back to default values.
	reboot			: Reboot the device.
```

All of these commands should be pretty straightforward with their respective description.

### Data Output

The output data format that can be controlled with the `set out <mode>` command can be switched between two modes:

- **Events:** This will print out all the ADC channels (bins) for newly acquired pulses in a chronological order. This data needs to be processed further to generate a pulse height histogram. Each pulse bin is delimited with a semicolon `;`.

Example (4096 channels):

```text
389;874;359;626;551;651;431;3123;466;214;662;1053;467;310;713;319;3001;294;340;493;437;1836;388;
570;354;318;330;688;1343;455;1627;359;252;652;449;602;
329;796;644;414;621;449;663;2311;0;538;224;394;421;444;362;885;406;437;796;994;579;319;456;404;442;922;441;973;
315;642;549;4095;588;774;361;329;1375;499;346;615;794;361;406;4095;457;1028;468;311;321;285;435;514;585;633;670;
```

- **Spectrum:** This is a histogram of all the ADC channels (bins) and the respective number of counts per channel. Each channel is delimited with a semicolon `;` and each spectrum is printed on its own line.

Example (4096 channels):

```text
12;0;0;0;0;0;0;0;0;0;0;0;0;0;0;0;0;0;0;0;0;0;0;0;0;0;0;0;0;0;0;0;0;0;0;0;0;0;0;0;0;0;0;0;0;0;0;0;0;0;0;0;0;0;0;0;0;0;0;0;0;0;0;0;0;0;0;0;0;0;0;0;0;0;0;0;0;0;0;0;0;0;0;0;0;0;0;0;0;0;0;0;0;0;0;0;0;0;0;0;0;0;0;0;0;0;0;0;0;0;0;0;0;0;0;0;0;0;0;0;0;0;0;0;0;0;0;0;0;0;0;0;0;0;0;0;0;0;0;0;0;0;0;0;0;0;0;0;0;0;0;0;1;1;1;0;0;0;0;0;0;0;0;0;0;0;0;0;0;0;0;0;0;0;0;0;0;0;0;0;0;0;0;0;0;0;0;0;0;0;1;1;0;0;0;0;0;0;0;0;0;0;0;0;3;0;3;0;4;1;1;0;2;1;1;0;0;1;1;1;1;2;1;0;2;0;0;1;2;1;0;0;0;2;1;1;1;0;1;1;0;1;1;0;0;1;0;1;0;1;0;3;3;1;0;2;0;0;1;2;1;0;0;0;1;2;1;1;0;0;1;0;0;3;0;1;2;0;0;0;0;0;2;0;0;3;2;1;0;0;2;2;0;1;2;1;1;3;3;0;0;1;2;0;0;2;1;2;2;1;2;5;2;0;3;2;1;3;3;3;0;3;2;3;1;3;0;5;4;6;3;0;2;3;1;1;1;4;0;4;3;2;2;3;1;4;3;5;3;5;4;4;4;1;8;3;1;4;2;4;1;4;4;2;2;6;3;2;1;2;1;5;3;2;2;3;3;4;3;2;4;3;3;4;5;1;3;3;5;4;1;5;3;1;4;5;3;2;4;1;6;2;3;2;2;4;4;1;2;1;2;7;3;2;4;0;3;1;2;2;5;2;1;2;3;4;2;6;2;1;2;2;2;3;1;5;5;5;1;3;2;3;5;3;2;4;1;3;2;2;2;0;2;3;0;3;2;3;4;2;4;4;0;2;0;3;3;3;3;2;0;1;1;2;4;4;3;1;2;0;2;2;3;4;1;4;1;1;1;3;2;1;5;4;0;1;0;2;0;3;1;2;5;0;0;0;4;5;3;1;2;0;2;6;3;2;2;2;4;0;0;1;2;3;5;4;2;3;0;2;2;2;3;1;0;0;0;1;2;1;0;1;2;3;1;3;2;2;0;4;0;4;7;0;1;0;3;1;1;1;1;2;1;0;1;2;1;2;1;1;2;0;3;3;0;2;3;0;1;2;2;0;2;0;0;3;2;1;2;0;0;0;0;2;4;1;0;2;1;1;1;1;3;3;1;2;3;4;0;3;4;0;1;1;1;1;0;0;1;2;1;3;0;1;3;0;2;0;0;0;0;0;0;1;2;2;1;2;0;1;0;1;1;3;3;1;1;1;0;2;2;1;1;1;0;0;1;0;0;2;2;1;1;1;1;2;0;2;0;2;1;2;0;1;1;0;0;0;0;0;0;1;1;0;1;0;2;2;2;0;0;2;2;2;1;0;3;2;1;0;1;1;2;1;2;1;1;1;1;0;2;0;1;2;0;0;1;0;0;0;1;0;3;0;0;1;0;1;1;2;1;0;0;0;2;0;0;1;1;1;0;2;0;0;1;0;0;3;0;1;0;1;0;2;0;0;3;1;1;1;0;2;1;0;1;0;0;0;1;0;1;2;0;0;1;0;0;0;1;0;0;0;0;0;0;0;0;0;0;1;1;1;0;3;1;0;2;0;2;0;0;1;0;2;1;0;0;0;0;0;1;2;0;0;0;0;2;0;2;1;1;1;1;0;0;0;1;2;0;0;0;0;1;0;2;0;0;0;0;0;0;0;0;0;1;0;0;0;1;2;3;0;0;0;0;0;0;0;0;1;0;1;0;0;0;0;0;0;0;0;1;0;0;0;1;0;1;1;0;1;0;0;0;0;0;1;0;0;0;0;0;0;0;1;2;0;0;0;1;1;0;0;1;1;0;0;0;0;0;0;1;1;0;0;1;0;1;0;0;0;0;0;1;0;0;1;0;0;0;0;0;0;0;0;0;0;0;0;1;0;0;0;0;0;0;0;0;2;1;0;0;0;0;0;0;1;0;0;0;0;0;0;0;0;0;0;0;1;0;0;0;0;1;1;0;0;0;0;0;0;0;0;0;0;0;0;0;0;0;0;0;0;1;0;1;1;1;0;1;0;0;0;0;0;0;0;1;0;0;1;0;0;0;0;0;0;0;0;0;0;0;0;1;0;0;0;1;0;1;0;0;0;0;0;0;0;0;0;0;0;0;0;0;0;0;0;1;0;0;0;0;0;0;1;0;1;0;1;1;0;0;0;0;0;0;0;0;1;2;1;0;1;0;0;0;0;0;0;0;1;0;0;0;1;0;0;0;0;1;0;1;0;0;0;0;0;0;0;0;0;0;3;0;0;0;1;0;0;1;0;0;1;0;0;0;0;0;1;1;0;0;1;0;0;0;0;0;0;0;0;0;0;0;0;0;0;0;0;0;0;1;1;0;0;0;0;0;0;0;0;0;1;0;0;0;0;0;0;0;0;0;0;1;0;0;0;0;0;0;0;0;0;0;0;0;0;0;0;0;0;0;0;0;0;0;1;0;0;0;0;0;0;0;0;0;0;0;2;0;0;0;0;0;0;0;1;0;0;1;0;0;0;0;0;0;0;0;0;0;0;1;0;0;0;0;0;0;0;0;0;0;0;0;0;0;0;0;0;0;0;0;0;0;0;0;0;0;0;0;1;0;0;0;0;0;0;0;0;0;0;1;0;0;0;0;0;0;0;0;0;0;0;1;0;0;0;0;0;0;1;0;0;0;0;0;1;0;1;0;0;0;0;0;0;0;0;0;0;0;0;0;0;0;0;0;1;0;0;0;0;1;0;0;0;0;0;0;0;0;0;0;0;0;1;1;0;0;1;0;1;0;0;0;0;0;0;0;0;0;0;0;0;0;1;0;0;0;0;0;0;0;0;0;0;0;0;0;0;0;0;0;0;0;0;0;0;0;0;1;0;0;0;0;0;0;1;0;0;0;0;0;0;0;0;0;0;1;0;0;0;0;0;0;0;1;0;0;0;0;0;0;0;0;0;0;0;0;1;0;0;0;0;0;0;0;0;0;0;0;0;0;0;0;0;0;0;0;0;0;0;0;0;0;0;0;0;0;0;0;1;0;0;1;0;0;0;0;1;0;0;0;0;0;0;0;0;0;0;0;1;0;0;0;0;0;1;0;0;0;0;0;0;0;0;0;0;0;0;0;0;0;0;0;1;0;0;0;0;0;0;0;0;1;0;0;0;0;0;0;0;0;0;0;0;0;0;0;0;0;0;0;0;0;0;0;2;1;0;0;0;1;0;0;0;0;0;0;0;0;0;0;0;1;0;0;0;1;0;0;0;0;0;0;0;0;0;0;0;0;0;0;0;0;0;0;0;0;0;0;0;0;0;0;0;1;0;0;0;0;0;0;0;0;0;0;0;0;0;0;0;0;0;0;0;0;1;0;0;0;1;0;0;0;1;0;0;0;0;0;0;0;0;0;0;0;0;1;0;0;0;0;0;0;0;0;0;0;0;0;0;0;0;0;0;0;0;0;1;0;0;0;0;0;0;0;0;0;0;0;0;0;0;0;0;1;0;0;0;0;0;0;0;0;0;0;0;0;0;0;0;0;0;0;0;0;0;0;0;0;0;0;0;0;0;0;0;0;0;0;0;0;0;0;0;0;0;0;0;0;0;0;0;0;1;0;0;0;0;0;0;0;0;0;1;0;0;0;0;0;0;0;0;0;0;0;0;0;0;0;0;0;0;0;0;0;0;0;0;0;0;0;0;0;0;0;0;0;0;0;0;0;0;0;0;0;0;0;0;0;0;0;0;1;1;0;1;0;0;1;0;0;0;0;0;0;0;0;0;0;0;0;0;0;0;0;0;0;0;0;1;0;0;0;0;0;0;0;0;0;0;0;0;0;0;0;0;0;0;0;0;0;0;0;0;0;0;0;0;0;0;0;0;0;0;0;1;0;0;0;0;1;0;0;0;0;0;0;0;0;0;0;0;0;0;0;0;1;0;0;0;0;0;0;0;0;0;0;0;0;0;0;0;0;0;0;0;0;0;0;0;0;0;0;0;2;0;0;0;0;0;0;0;0;0;0;0;0;0;0;0;0;0;0;0;0;0;0;0;0;0;0;0;0;0;0;0;0;0;0;0;0;0;1;0;0;0;0;0;0;1;0;0;0;0;0;0;0;0;0;0;0;0;0;1;0;0;0;0;0;0;0;1;0;0;1;0;0;0;0;0;0;0;0;0;0;0;0;0;0;0;0;0;0;0;0;0;0;0;0;0;0;1;0;0;0;0;0;0;0;0;0;0;0;0;0;0;0;0;0;0;0;0;0;0;0;0;0;0;0;0;0;0;0;0;0;0;0;0;0;0;0;0;0;1;0;0;0;0;0;0;0;0;0;0;0;0;0;0;0;0;0;0;0;0;0;0;0;0;0;0;0;0;0;0;0;0;0;0;0;0;0;0;0;0;0;0;0;0;0;0;0;0;0;0;0;0;0;0;0;0;0;0;0;0;0;0;0;0;0;0;0;0;0;0;0;0;0;0;0;0;0;0;0;0;0;0;0;0;0;0;0;0;0;0;1;0;0;0;0;0;0;0;0;0;0;0;0;0;0;0;0;0;0;0;0;1;0;0;0;0;0;0;0;0;0;0;0;0;0;0;0;0;0;0;0;0;0;0;0;0;0;0;0;0;0;0;0;0;0;0;0;0;0;1;0;0;0;0;0;0;0;0;0;0;0;0;0;0;0;0;0;1;0;0;0;1;0;0;0;0;0;0;0;0;0;0;0;0;0;0;0;0;0;0;0;0;0;1;0;0;0;0;0;0;0;0;0;0;0;0;0;0;0;0;0;0;1;0;0;0;0;0;0;0;0;0;1;0;0;0;0;0;0;0;0;0;0;0;0;0;0;0;0;0;0;0;0;0;1;0;1;0;0;0;0;0;0;0;0;0;0;0;0;0;0;0;0;0;0;0;0;0;0;0;0;0;0;0;0;0;0;0;0;0;0;0;0;0;0;0;0;0;0;0;0;0;0;0;0;0;0;0;0;0;0;0;0;0;0;0;0;1;0;0;0;0;0;0;0;0;0;0;0;0;0;0;0;0;0;0;0;0;0;0;0;0;0;0;0;0;0;0;0;0;0;0;0;0;0;0;0;0;1;0;0;0;0;0;0;0;0;0;0;0;0;0;0;0;0;0;0;0;0;0;0;0;0;0;0;0;0;0;0;0;0;0;0;0;0;0;0;1;0;0;0;0;0;0;0;0;0;0;0;0;0;0;0;0;0;0;0;0;0;0;0;0;0;0;0;0;0;0;0;0;0;0;0;0;0;0;0;0;0;0;0;0;0;0;0;0;1;0;0;0;0;0;0;0;0;0;0;0;0;0;0;0;0;1;0;0;0;0;0;0;0;0;0;0;0;0;0;0;0;0;0;0;0;0;0;0;0;0;1;0;0;0;0;0;0;1;0;0;0;0;0;0;0;0;0;0;0;0;0;0;0;0;0;0;0;0;0;0;0;0;0;0;0;0;0;0;0;0;0;1;0;0;0;0;0;0;0;0;0;0;0;0;0;0;0;0;0;0;0;0;0;0;0;0;0;0;0;0;0;0;0;0;0;0;0;0;0;0;0;0;0;0;0;0;0;0;0;0;0;0;0;0;0;0;0;0;0;0;0;0;0;0;0;0;0;0;0;0;0;0;0;0;0;0;0;0;0;0;0;0;0;1;0;0;0;0;0;0;0;0;0;0;0;0;0;0;0;0;0;0;0;0;0;0;0;0;0;0;0;0;0;0;0;0;0;0;0;0;0;0;0;0;0;0;0;0;0;0;0;0;0;0;0;0;0;0;0;0;0;0;0;0;0;0;0;0;0;0;0;0;0;0;0;0;0;0;0;0;0;0;0;0;1;0;0;0;0;0;0;0;0;0;0;0;1;0;0;0;0;0;0;0;0;0;0;0;0;0;0;0;0;0;0;0;0;0;0;0;0;0;0;0;0;0;0;0;0;0;0;0;1;0;0;0;0;0;0;0;0;0;0;0;0;0;0;0;0;0;0;0;0;0;0;0;0;0;0;0;0;0;0;0;0;0;0;0;0;0;0;0;0;0;0;0;0;0;0;0;0;0;0;0;0;0;0;0;0;0;0;0;0;0;0;0;0;0;0;0;0;0;0;0;0;0;0;0;0;0;0;0;0;0;0;0;0;0;0;0;0;0;0;0;0;0;0;0;0;0;0;0;0;0;0;0;0;0;0;0;0;0;0;0;0;0;0;0;0;0;0;0;0;0;0;0;0;0;0;0;0;0;0;0;0;0;0;0;0;0;0;0;0;0;0;0;0;0;0;0;0;0;0;0;0;0;0;0;0;0;1;0;0;0;0;0;0;0;0;0;0;0;0;0;0;1;0;0;0;0;0;0;0;0;0;0;0;0;0;0;0;0;0;0;0;0;0;0;0;0;0;0;0;0;0;0;0;0;0;0;0;0;0;1;0;0;0;0;0;0;0;0;0;0;0;0;0;0;0;0;0;0;0;0;0;0;0;0;0;0;0;0;0;1;0;0;0;0;0;0;0;0;0;0;0;0;0;0;0;0;0;0;0;0;0;0;0;0;0;1;0;0;0;0;0;0;0;0;0;0;1;0;0;0;0;0;0;0;0;0;0;0;0;0;0;0;0;0;0;0;0;0;0;0;0;0;0;0;0;0;0;0;0;0;0;0;0;0;0;0;0;0;0;0;0;0;0;0;0;0;0;0;0;0;0;0;0;0;0;0;0;0;0;0;0;0;0;0;0;0;0;0;0;0;0;0;0;0;0;0;0;0;0;0;0;0;0;0;0;0;0;0;0;0;0;0;0;0;0;0;0;0;0;0;0;0;0;0;0;0;0;2;0;0;0;0;0;0;0;0;0;0;0;0;0;0;0;0;0;0;0;0;0;0;0;0;0;0;0;0;0;0;0;0;0;0;0;0;0;0;0;0;0;0;0;0;0;0;0;0;0;0;0;0;0;0;0;0;0;0;0;0;0;0;0;0;0;0;0;0;0;0;0;0;0;0;0;0;0;0;0;0;0;0;0;0;0;0;0;0;0;0;0;0;0;0;0;0;0;0;0;0;0;0;0;0;0;0;0;0;0;1;0;0;0;0;0;0;0;0;0;0;0;0;0;0;0;0;0;0;0;0;0;0;0;0;0;0;0;0;0;0;0;0;0;0;0;0;0;0;0;0;0;0;0;0;0;0;0;0;0;0;0;0;0;0;0;0;0;0;0;0;0;0;0;0;0;0;0;0;0;0;0;0;0;0;0;0;0;0;0;0;0;0;0;0;0;0;0;0;0;0;0;0;0;0;0;0;0;0;0;0;0;0;0;0;0;0;0;0;0;0;0;0;0;0;0;0;0;0;0;0;0;0;0;0;0;0;0;0;0;0;0;0;0;0;0;0;0;0;0;0;0;0;0;0;0;0;0;0;0;0;0;0;0;0;0;0;0;0;0;0;0;0;0;0;0;0;0;0;0;0;0;0;0;0;0;0;0;0;0;0;0;0;0;0;0;0;0;0;0;0;0;0;0;0;0;0;0;0;0;0;0;0;0;0;0;0;0;0;0;0;0;0;0;0;0;0;0;0;0;0;0;0;0;0;0;0;0;0;0;0;0;0;0;0;0;0;0;0;0;0;0;0;0;0;0;0;0;0;0;0;0;0;0;0;0;0;0;0;0;0;0;0;0;0;0;0;0;0;0;0;0;0;0;0;0;0;0;0;0;0;0;0;0;0;0;0;0;0;0;0;0;0;0;0;0;0;0;0;0;0;0;0;0;0;0;0;0;0;0;0;0;0;0;0;0;0;0;0;0;0;0;0;0;0;0;0;0;0;0;0;0;0;0;0;0;0;0;0;0;0;0;0;0;0;0;0;0;0;0;0;0;0;0;0;0;0;0;0;0;0;0;0;0;0;0;0;0;0;0;0;0;0;0;0;0;0;0;0;0;0;0;0;0;0;0;0;0;0;0;0;0;0;0;0;0;0;0;0;0;0;0;0;0;0;0;0;0;0;0;0;0;0;0;0;0;0;0;0;0;0;0;0;0;0;0;0;0;0;0;0;0;0;0;0;0;0;0;0;0;0;0;0;0;0;0;0;0;0;0;0;0;0;0;0;0;0;0;0;0;0;0;0;0;0;0;0;0;0;0;0;0;0;0;0;0;0;0;0;0;0;0;0;0;0;0;0;0;0;0;0;0;0;0;0;0;0;0;0;0;0;0;0;0;0;0;0;0;0;0;0;0;0;0;0;0;0;0;0;0;0;0;0;0;0;0;0;0;0;0;0;0;0;0;0;0;0;0;0;0;0;0;0;0;0;0;0;0;0;0;0;0;0;0;0;0;0;0;0;0;0;0;0;0;0;0;0;0;0;0;0;0;0;0;0;0;0;0;0;0;0;0;0;0;0;0;0;0;0;0;0;0;0;0;0;0;0;0;0;0;0;0;0;0;0;0;0;0;0;0;0;0;0;0;0;0;0;0;0;0;0;0;0;0;0;0;0;0;0;0;0;0;0;0;0;0;0;0;0;0;0;0;0;0;0;0;0;0;0;0;0;0;0;0;0;0;0;0;0;0;0;0;0;0;0;0;0;0;0;0;0;0;0;0;0;0;0;0;0;0;0;0;0;0;0;0;0;0;0;0;0;0;0;0;0;0;0;0;0;0;0;0;0;0;0;0;0;0;0;0;0;0;0;0;0;0;0;0;0;0;0;0;0;0;0;0;0;0;0;0;0;0;0;0;0;0;0;0;0;0;0;0;0;0;0;0;0;0;0;0;0;0;0;0;0;0;0;0;0;1;0;0;0;0;0;0;0;0;0;0;0;0;0;0;0;0;0;0;0;0;0;0;0;0;0;0;0;0;0;0;0;0;0;0;0;0;0;0;0;0;0;0;0;0;0;0;0;0;0;0;0;0;0;0;0;0;0;0;0;0;0;0;0;0;0;0;0;0;0;0;0;0;0;0;0;0;0;0;0;0;0;0;0;0;0;0;0;0;0;0;0;0;0;0;0;0;0;0;0;0;0;0;4;
13;0;0;0;0;0;0;0;0;0;0;0;0;0;0;0;0;0;0;0;0;0;0;0;0;0;0;0;0;0;0;0;0;0;0;0;0;0;0;0;0;0;0;0;0;0;0;0;0;0;0;0;0;0;0;0;0;0;0;0;0;0;0;0;0;0;0;0;0;0;0;0;0;0;0;0;0;0;0;0;0;0;0;0;0;0;0;0;0;0;0;0;0;0;0;0;0;0;0;0;0;0;0;0;0;0;0;0;0;0;0;0;0;0;0;0;0;0;0;0;0;0;0;0;0;0;0;0;0;0;0;0;0;0;0;0;0;0;0;0;0;0;0;0;0;0;0;0;0;0;0;0;1;1;1;0;0;0;0;0;0;0;0;0;0;0;0;0;0;0;0;0;0;0;0;0;0;0;0;0;0;0;0;0;0;0;0;0;0;0;1;1;0;0;0;0;0;0;0;0;0;0;0;0;3;0;3;0;4;1;1;0;2;1;1;0;0;1;1;1;1;2;1;0;2;0;0;1;2;1;0;0;0;2;1;1;1;0;1;1;0;1;1;0;0;1;0;1;0;1;0;3;3;1;0;2;0;0;1;2;1;0;0;0;1;2;1;1;0;0;1;0;0;3;0;1;2;0;0;0;0;0;3;0;0;3;2;1;0;0;2;2;0;1;2;1;1;4;3;0;0;1;2;0;0;2;1;2;3;1;2;5;2;0;3;2;1;3;3;3;0;3;2;3;1;3;0;5;4;6;3;0;2;3;1;1;1;4;0;4;3;2;2;3;1;4;3;5;3;5;4;4;4;1;8;3;1;4;2;4;1;4;4;2;2;7;3;2;1;2;1;5;3;2;2;3;3;4;3;2;4;3;3;4;5;1;3;3;5;4;1;5;3;1;4;5;3;2;4;1;6;2;3;2;3;4;4;1;2;1;2;8;3;2;4;0;3;1;2;2;5;2;1;2;3;4;2;6;2;1;2;2;2;3;1;5;5;5;1;3;3;3;5;3;2;4;1;3;2;2;2;0;2;3;0;3;2;3;4;2;4;4;0;2;0;3;3;3;3;2;1;1;1;2;4;4;3;1;2;0;2;2;3;4;1;4;1;1;1;3;2;1;5;4;0;1;0;2;0;3;1;2;5;0;0;0;4;5;3;3;2;0;2;6;3;2;2;2;4;0;0;1;2;3;5;4;2;3;0;2;2;2;3;1;0;0;0;1;2;1;0;1;2;3;1;3;2;2;0;4;0;4;8;0;1;0;3;1;1;1;1;2;1;0;1;2;2;2;1;1;2;0;3;3;0;2;3;0;2;2;2;0;2;0;0;3;2;1;2;0;0;0;0;2;4;1;0;2;1;1;1;1;3;3;1;2;3;4;0;3;4;0;1;1;1;1;0;0;1;2;1;3;0;1;3;0;2;0;0;0;0;0;0;1;2;2;1;2;0;1;0;1;1;3;3;1;1;1;0;2;2;1;1;1;0;0;1;0;0;2;2;1;1;1;1;2;0;2;0;2;1;2;0;1;1;0;0;0;0;0;0;1;1;0;1;0;2;2;2;0;0;2;2;2;1;0;3;2;1;0;1;1;2;1;2;1;1;1;1;0;2;0;1;2;0;0;1;0;0;0;1;0;3;0;0;1;0;1;1;2;1;0;0;0;2;0;0;1;1;1;0;2;0;0;1;0;0;3;0;1;0;1;0;2;0;0;3;1;1;1;0;2;1;0;1;0;0;0;1;0;1;2;0;0;1;0;0;0;1;0;0;0;0;0;0;0;0;0;0;1;1;1;0;3;1;0;2;0;2;0;0;1;0;2;1;0;0;0;0;0;1;2;0;0;0;0;3;0;2;1;1;1;1;0;0;0;1;2;0;0;0;0;1;0;2;0;0;0;0;0;0;0;0;0;1;0;0;0;1;2;3;0;0;0;0;0;0;0;0;1;0;1;0;0;0;0;0;0;0;0;1;0;0;0;1;0;1;1;0;1;0;0;0;0;0;1;0;0;0;0;0;0;0;1;2;0;0;0;1;1;0;0;1;1;0;0;0;0;0;0;1;1;0;0;1;0;1;0;0;0;0;0;1;0;0;1;0;0;0;0;0;0;0;0;0;0;0;0;1;0;0;0;0;0;0;0;0;2;1;0;0;0;0;0;0;1;0;0;0;0;0;0;0;0;0;0;0;1;0;0;0;0;1;1;0;0;0;0;0;0;0;0;0;0;1;0;0;0;0;0;0;0;1;0;1;1;1;0;1;0;0;0;0;0;0;0;1;0;0;1;0;0;0;0;0;0;0;0;0;0;0;0;1;0;0;0;1;0;1;0;0;0;0;0;0;0;0;0;0;0;0;0;0;0;0;0;1;0;0;0;0;0;0;1;0;1;0;1;1;0;0;0;0;0;0;0;0;1;2;1;0;1;0;0;0;0;0;0;0;1;0;0;0;1;0;0;0;0;1;0;1;0;0;0;0;0;0;0;0;0;0;3;0;0;0;1;0;0;1;0;0;1;0;0;0;0;0;1;1;0;0;1;0;0;0;0;0;0;0;0;0;0;0;0;0;0;0;0;0;0;1;1;0;0;0;0;0;0;0;0;0;1;0;0;0;0;0;0;0;0;0;0;1;0;0;0;0;0;0;0;0;0;0;0;0;0;0;0;0;0;0;0;0;0;0;1;0;0;0;0;0;1;0;0;0;0;0;2;0;0;0;0;0;0;0;1;0;0;1;0;0;0;0;0;0;0;0;0;0;0;1;0;0;0;0;0;0;0;0;0;0;0;0;0;0;0;0;0;0;0;0;0;0;0;0;0;0;0;0;1;0;0;0;0;0;0;0;0;0;0;1;0;0;0;0;0;0;0;0;0;0;0;1;0;0;0;0;0;0;1;0;0;0;0;0;1;0;1;0;0;0;0;0;0;0;0;0;0;0;0;0;0;0;0;0;1;0;0;0;0;1;0;0;0;0;0;0;0;0;0;0;0;0;1;1;0;0;1;0;1;0;0;0;0;0;0;0;0;0;0;0;0;0;1;0;0;0;0;0;0;0;0;0;0;0;0;0;0;0;0;0;0;0;0;0;0;0;0;1;0;0;0;0;0;0;1;0;0;0;0;0;0;0;0;0;0;1;0;0;0;0;0;0;0;1;0;0;0;0;0;0;0;0;0;0;0;0;1;0;0;0;0;0;0;0;0;0;0;0;0;0;0;0;0;0;0;0;0;0;0;0;0;0;0;0;0;0;0;0;1;0;0;1;0;0;0;0;1;0;0;0;0;0;0;0;0;0;0;0;1;0;0;0;0;0;1;1;0;0;0;0;0;0;0;0;0;0;0;0;0;0;0;0;1;0;0;0;0;0;0;0;0;1;0;0;0;0;0;0;0;0;0;0;0;0;0;0;0;0;0;0;0;0;0;0;2;1;0;0;0;1;0;0;0;0;0;0;0;0;0;0;0;1;0;0;0;1;0;0;0;0;0;0;0;0;0;0;0;0;0;0;0;0;0;0;0;0;0;0;0;0;0;0;0;1;0;0;0;0;0;0;0;0;0;0;0;0;0;0;0;0;0;0;0;0;1;0;0;0;1;0;0;0;1;0;0;0;0;0;0;0;0;0;0;0;0;1;0;0;0;0;0;0;0;0;0;0;0;0;0;0;0;0;0;0;0;0;1;0;0;0;0;0;0;0;0;0;0;0;0;0;0;0;0;1;0;0;0;0;0;0;0;0;0;0;0;0;0;0;0;0;0;0;0;0;0;0;0;0;0;0;0;0;0;0;0;0;0;0;0;0;0;0;0;0;0;0;0;0;0;0;0;0;1;0;0;0;0;0;0;0;0;0;1;0;0;0;0;0;0;0;0;0;0;0;0;0;0;0;0;0;0;0;0;0;0;0;0;0;0;0;0;0;0;0;0;0;0;0;0;0;0;0;0;0;0;0;0;0;0;0;0;1;1;0;1;0;0;1;0;0;0;0;0;0;0;0;0;0;0;0;0;0;0;0;0;0;0;0;1;0;0;0;0;0;0;0;0;0;0;0;0;0;0;0;0;0;0;0;0;0;0;0;0;0;0;0;0;0;0;0;0;0;0;0;1;0;0;0;0;1;0;0;0;0;0;0;0;0;0;0;0;0;0;0;0;1;0;0;0;0;0;0;0;0;0;0;0;0;0;0;0;0;0;0;0;0;0;0;0;0;0;0;0;2;0;0;0;0;0;0;0;0;0;0;0;0;0;0;0;0;0;0;0;0;0;0;0;0;0;0;0;0;0;0;0;0;0;0;0;0;0;1;0;0;0;0;0;0;1;0;0;0;0;0;0;0;0;0;0;0;0;0;1;0;0;0;0;0;0;0;1;0;0;1;0;0;0;0;0;0;0;0;0;0;0;0;0;0;0;0;0;0;0;0;0;0;0;0;0;0;1;0;0;0;0;0;0;0;0;0;0;0;0;0;0;0;0;0;0;0;0;0;0;0;0;0;0;0;0;0;0;0;0;0;0;0;0;0;0;0;0;0;1;0;0;0;0;0;0;0;0;0;0;0;0;0;0;0;0;0;0;0;0;0;0;0;0;0;0;0;0;0;0;0;0;0;0;0;0;0;0;0;0;0;0;0;0;0;0;0;0;0;0;0;0;0;0;0;0;0;0;0;0;0;0;0;0;0;0;0;0;0;0;0;0;0;0;0;0;0;0;0;0;0;0;0;0;0;0;0;0;0;0;1;0;0;0;0;0;0;0;0;0;0;0;0;0;0;0;0;0;0;0;0;1;0;0;0;0;0;0;0;0;0;0;0;0;0;0;0;0;0;0;0;0;0;0;0;0;0;0;0;0;0;0;0;0;0;0;0;0;0;1;0;0;0;0;0;0;0;0;0;0;0;0;0;0;0;0;0;1;0;0;0;1;0;0;0;0;0;0;0;0;0;0;0;0;0;0;0;0;0;0;0;0;0;1;0;0;0;0;0;0;0;0;0;0;0;0;0;0;0;0;0;0;1;0;0;0;0;0;0;0;0;0;1;0;0;0;0;0;0;0;0;0;0;0;0;0;0;0;0;0;0;0;0;0;1;0;1;0;0;0;0;0;0;0;0;0;0;0;0;0;0;0;0;0;0;0;0;0;0;0;0;0;0;0;0;0;0;0;0;0;0;0;0;0;0;0;0;0;0;0;0;0;0;0;0;0;0;0;0;0;0;0;0;0;0;0;0;1;0;0;0;0;0;0;0;0;0;0;0;0;0;0;0;0;0;0;0;0;0;0;0;0;0;0;0;0;0;0;1;0;0;0;0;0;0;0;0;0;1;0;0;0;0;0;0;0;0;0;0;0;0;0;0;0;0;0;0;0;0;0;0;0;0;0;0;0;0;0;0;0;0;0;0;0;0;0;0;1;0;0;0;0;0;0;0;0;0;0;0;0;0;0;0;0;0;0;0;0;0;0;0;0;0;0;0;0;0;0;0;0;0;0;0;0;0;0;0;0;0;0;0;0;0;0;0;0;1;0;0;0;0;0;0;0;0;0;0;0;0;0;0;0;0;1;0;0;0;0;0;0;0;0;0;0;0;0;0;0;0;0;0;0;0;0;0;0;0;0;1;0;0;0;0;0;0;1;0;0;0;0;0;0;0;0;0;0;0;0;0;0;0;0;0;0;0;0;0;0;0;0;0;0;0;0;0;0;1;0;0;1;0;0;0;0;0;0;0;0;0;0;0;0;0;0;0;0;0;0;0;0;0;0;0;0;0;0;0;0;0;0;0;0;0;0;0;0;0;0;0;0;0;0;0;0;0;0;0;0;0;0;0;0;0;0;0;0;0;0;0;0;0;0;0;0;0;0;0;0;0;0;0;0;0;0;0;0;0;0;0;0;0;1;0;0;0;0;0;0;0;0;0;0;0;0;0;0;0;0;0;0;0;0;0;0;0;0;0;0;0;0;0;0;0;0;0;0;0;0;0;0;0;0;0;0;0;0;0;0;0;0;0;0;0;0;0;0;0;0;0;0;0;0;0;0;0;0;0;0;0;0;0;0;0;0;0;0;0;0;0;0;0;0;1;0;0;0;0;0;0;0;0;0;0;0;1;0;0;0;0;0;0;0;0;0;0;0;0;0;0;0;0;0;0;0;0;0;0;0;0;0;0;0;0;0;0;0;0;0;0;0;1;0;0;0;0;0;0;0;0;0;0;0;0;0;0;0;0;0;0;0;0;0;0;0;0;0;0;0;0;0;0;0;0;0;0;0;0;0;0;0;0;0;0;0;0;0;0;0;0;0;0;0;0;0;0;0;0;0;0;0;0;0;0;0;0;0;0;0;0;0;0;0;0;0;0;0;0;0;0;0;0;0;0;0;0;0;0;0;0;0;0;0;0;0;0;0;0;0;0;0;0;0;0;0;0;0;0;0;0;0;0;0;0;0;0;0;0;0;0;0;0;0;0;0;0;0;0;0;0;0;0;0;0;0;0;0;0;0;0;0;0;0;0;0;0;0;0;0;0;0;0;0;0;0;0;0;0;0;1;0;0;0;0;0;0;0;0;0;0;0;0;0;0;1;0;0;0;0;0;0;0;0;0;0;0;0;0;0;0;0;0;0;0;0;0;0;0;0;0;0;0;0;0;0;0;0;0;0;0;0;0;1;0;0;0;0;0;0;0;0;0;0;0;0;0;0;0;0;0;0;0;0;0;0;0;0;0;0;0;0;0;1;0;0;0;0;0;0;0;0;0;0;0;0;0;0;0;0;0;0;0;0;0;0;0;0;0;1;0;0;0;0;0;0;0;0;0;0;1;0;0;0;0;0;0;0;0;0;0;0;0;0;0;0;0;0;0;0;0;0;0;0;0;0;0;0;0;0;0;0;0;0;0;0;0;0;0;0;0;0;0;0;0;0;0;0;0;0;0;0;0;0;0;0;0;0;0;0;0;0;0;0;0;0;0;0;0;0;0;0;0;0;0;0;0;0;0;0;0;0;0;0;0;0;0;0;0;0;0;0;0;0;0;0;0;0;0;0;0;0;0;0;0;0;0;0;0;0;0;2;0;0;0;0;0;0;0;0;0;0;0;0;0;0;0;0;0;0;0;0;0;0;0;0;0;0;0;0;0;0;0;0;0;0;0;0;0;0;0;0;0;0;0;0;0;0;0;0;0;0;0;0;0;0;0;0;0;0;0;0;0;0;0;0;0;0;0;0;0;0;0;0;0;0;0;0;0;0;0;0;0;0;0;0;0;0;0;0;0;0;0;0;0;0;0;0;0;0;0;0;0;0;0;0;0;0;0;0;0;1;0;0;0;0;0;0;0;0;0;0;0;0;0;0;0;0;0;0;0;0;0;0;0;0;0;0;0;0;0;0;0;0;0;0;0;0;0;0;0;0;0;0;0;0;0;0;0;0;0;0;0;0;0;0;0;0;0;0;0;0;0;0;0;0;0;0;0;0;0;0;0;0;0;0;0;0;0;0;0;0;0;0;0;0;0;0;0;0;0;0;0;0;0;0;0;0;0;0;0;0;0;0;0;0;0;0;0;0;0;0;0;0;0;0;0;0;0;0;0;0;0;0;0;0;0;0;0;0;0;0;0;0;0;0;0;0;0;0;0;0;0;0;0;0;0;0;0;0;0;0;0;0;0;0;0;0;0;0;0;0;0;0;0;0;0;0;0;0;0;0;0;0;0;0;0;0;0;0;0;0;0;0;0;0;0;0;0;0;0;0;0;0;0;0;0;0;0;0;0;0;0;0;0;0;0;0;0;0;0;0;0;0;0;0;0;0;0;0;0;0;0;0;0;0;0;0;0;0;0;0;0;0;0;0;0;0;0;0;0;0;0;0;0;0;0;0;0;0;0;0;0;0;0;0;0;0;0;0;0;0;0;0;0;0;0;0;0;0;0;0;0;0;0;0;0;0;0;0;0;0;0;0;0;0;0;0;0;0;0;0;0;0;0;0;0;0;0;0;0;0;0;0;0;0;0;0;0;0;0;0;0;0;0;0;0;0;0;0;0;0;0;0;0;0;0;0;0;0;0;0;0;0;0;0;0;0;0;0;0;0;0;0;0;0;0;0;0;0;0;0;0;0;0;0;0;0;0;0;0;0;0;0;0;0;0;0;0;0;0;0;0;0;0;0;0;0;0;0;0;0;0;0;0;0;0;0;0;0;0;0;0;0;0;0;0;0;0;0;0;0;0;0;0;0;0;0;0;0;0;0;0;0;0;0;0;0;0;0;0;0;0;0;0;0;0;0;0;0;0;0;0;0;0;0;0;0;0;0;0;0;0;0;0;0;0;0;0;0;0;0;0;0;0;0;0;0;0;0;0;0;0;0;0;0;0;0;0;0;0;0;0;0;0;0;0;0;0;0;0;0;0;0;0;0;0;0;0;0;0;0;0;0;0;0;0;0;0;0;0;0;0;0;0;0;0;0;0;0;0;0;0;0;0;0;0;0;0;0;0;0;0;0;0;0;0;0;0;0;0;0;0;0;0;0;0;0;0;0;0;0;0;0;0;0;0;0;0;0;0;0;0;0;0;0;0;0;0;0;0;0;0;0;0;0;0;0;0;0;0;0;0;0;0;0;0;0;0;0;0;0;0;0;0;0;0;0;0;0;0;0;0;0;0;0;0;0;0;0;0;0;0;0;0;0;0;0;0;0;0;0;0;0;0;0;0;0;0;0;0;0;0;0;0;0;0;0;0;0;0;0;0;0;0;0;0;0;0;0;0;0;0;0;0;0;0;0;0;0;0;0;0;0;0;0;0;0;0;0;0;0;0;0;0;0;0;0;0;0;0;0;0;0;0;0;0;0;0;0;0;0;0;0;0;0;0;0;0;0;0;0;0;0;0;0;0;0;0;0;0;0;0;0;0;0;0;0;0;0;0;0;0;0;0;0;0;0;0;0;0;0;0;0;0;0;0;0;0;0;0;0;0;0;0;0;0;0;0;0;0;0;0;0;0;0;0;0;0;0;0;0;0;0;0;0;0;0;0;0;1;0;0;0;0;0;0;0;0;0;0;0;0;0;0;0;0;0;0;0;0;0;0;0;0;0;0;0;0;0;0;0;0;0;0;0;0;0;0;0;0;0;0;0;0;0;0;0;0;0;0;0;0;0;0;0;0;0;0;0;0;0;0;0;0;0;0;0;0;0;0;0;0;0;0;0;0;0;0;0;0;0;0;0;0;0;0;0;0;0;0;0;0;0;0;0;0;0;0;0;0;0;0;4;
13;0;0;0;0;0;0;0;0;0;0;0;0;0;0;0;0;0;0;0;0;0;0;0;0;0;0;0;0;0;0;0;0;0;0;0;0;0;0;0;0;0;0;0;0;0;0;0;0;0;0;0;0;0;0;0;0;0;0;0;0;0;0;0;0;0;0;0;0;0;0;0;0;0;0;0;0;0;0;0;0;0;0;0;0;0;0;0;0;0;0;0;0;0;0;0;0;0;0;0;0;0;0;0;0;0;0;0;0;0;0;0;0;0;0;0;0;0;0;0;0;0;0;0;0;0;0;0;0;0;0;0;0;0;0;0;0;0;0;0;0;0;0;0;0;0;0;0;0;0;0;0;1;1;1;0;0;0;0;1;0;0;0;0;0;0;0;0;0;0;0;0;0;0;0;0;0;0;0;0;0;0;0;0;0;0;0;0;0;0;1;1;0;0;0;0;0;0;0;0;0;0;0;0;3;1;3;0;4;1;1;0;2;1;1;0;0;1;1;1;1;2;1;0;2;0;0;1;2;1;0;0;0;2;1;1;1;1;1;1;0;1;2;0;0;1;0;1;0;1;0;3;3;1;0;2;0;0;2;2;1;0;0;0;1;2;1;1;0;0;1;0;0;3;0;1;2;0;0;0;0;0;3;0;0;3;2;1;0;0;2;2;1;1;2;1;1;4;3;1;1;1;3;0;1;2;1;2;3;1;2;5;2;0;3;2;1;4;3;3;0;3;2;3;1;3;0;5;4;6;4;0;2;3;1;1;1;4;0;4;3;2;2;3;1;4;3;5;3;5;5;4;4;1;8;3;1;4;2;4;2;5;4;2;2;7;3;2;1;2;2;5;3;2;2;3;3;4;3;2;4;3;3;4;5;1;3;3;5;4;1;5;3;1;4;5;3;2;4;1;6;3;3;2;3;4;4;1;2;1;2;8;3;2;4;0;4;1;2;2;5;2;1;2;3;4;2;7;2;2;2;2;2;3;1;5;5;5;1;3;3;4;5;3;2;4;1;3;2;2;2;0;2;3;0;3;2;4;4;2;4;4;0;2;0;3;3;3;3;3;1;1;1;2;4;4;3;1;3;0;2;2;3;4;1;4;1;1;1;3;2;1;5;4;0;1;0;2;0;3;1;2;5;0;0;0;4;5;3;3;2;0;2;6;3;2;2;2;4;0;0;1;2;3;5;4;2;3;0;2;2;3;3;1;0;0;0;1;2;1;0;1;2;3;1;3;2;3;0;4;0;4;8;0;1;0;3;1;1;1;1;2;1;0;1;2;2;2;1;1;2;0;3;3;0;3;3;0;2;2;2;0;2;0;0;3;2;2;2;0;0;0;0;2;4;1;0;2;1;2;1;1;3;3;1;2;3;4;0;3;4;0;1;1;1;1;0;0;1;2;1;3;0;1;3;0;2;0;0;0;0;0;0;1;2;2;1;2;0;1;0;1;1;3;3;1;1;1;0;3;2;1;1;1;0;0;1;0;0;2;2;2;1;1;1;2;0;2;0;2;1;2;0;1;1;0;0;0;0;0;0;1;1;0;1;0;2;2;2;0;0;2;3;2;1;0;3;2;1;0;1;1;2;1;2;1;1;1;1;0;2;0;1;2;1;0;1;0;0;0;1;0;3;0;0;1;0;1;1;2;1;0;0;0;2;0;0;1;1;1;0;2;0;0;1;0;0;3;0;1;0;1;0;2;0;0;3;1;1;1;0;2;1;0;1;0;0;0;1;0;1;2;0;0;1;0;0;0;1;0;0;0;0;0;0;0;0;0;0;1;1;1;0;3;1;0;2;0;2;0;0;1;0;2;1;0;0;0;0;0;1;2;0;0;0;0;3;0;2;1;1;1;1;0;0;0;1;2;0;0;0;0;1;0;2;0;0;0;0;0;0;0;0;0;1;0;0;0;1;2;3;0;0;0;0;0;0;0;0;1;0;1;0;0;0;0;0;0;0;0;1;0;0;0;1;0;1;1;0;1;0;0;0;0;0;1;0;0;0;0;0;0;0;1;2;0;0;0;1;1;0;0;1;1;0;0;0;0;0;0;1;1;0;0;1;0;1;0;0;0;0;0;1;0;0;1;0;0;0;0;0;0;0;0;0;0;0;0;1;0;0;0;0;0;0;0;0;2;1;0;0;0;0;0;0;1;0;0;0;0;0;0;0;0;0;0;0;1;0;0;0;0;1;1;0;0;0;0;0;0;0;0;0;0;1;0;0;0;0;0;0;0;1;0;1;1;1;0;1;0;0;0;0;0;1;0;1;0;0;1;0;0;0;0;0;0;0;0;0;0;0;0;1;0;0;0;1;0;1;0;0;0;0;0;0;0;0;0;0;0;0;0;0;0;0;0;1;0;0;0;0;0;0;1;0;1;0;1;1;0;0;0;0;0;0;0;0;1;2;1;0;1;0;0;0;0;0;0;0;1;0;0;0;1;0;0;0;0;1;0;1;0;0;0;0;0;0;0;0;0;0;3;0;0;0;1;0;0;1;0;0;1;0;0;0;0;0;1;1;0;0;1;0;0;0;0;0;0;0;0;0;0;0;0;0;0;0;0;0;0;1;1;0;0;0;0;0;0;0;0;0;1;0;0;0;0;0;0;0;0;0;0;1;0;0;0;0;0;0;0;0;0;0;0;0;0;0;0;0;0;0;0;0;0;0;1;0;0;0;0;0;1;0;0;0;0;0;2;0;0;0;0;0;0;0;1;0;0;1;0;0;0;0;0;0;0;0;0;0;0;1;0;0;0;0;0;0;0;0;0;0;0;0;0;0;0;0;0;0;0;0;0;0;0;0;0;0;0;0;1;0;0;0;0;0;0;0;0;0;0;1;0;0;0;0;0;0;0;0;0;0;0;1;0;0;0;0;0;0;1;0;0;0;0;0;1;0;1;0;0;0;0;0;0;0;0;0;0;0;0;0;0;0;0;0;1;0;0;0;0;1;0;0;0;0;0;0;0;0;0;0;0;0;1;1;0;0;1;0;1;0;0;0;0;0;0;0;0;0;0;0;0;0;1;0;0;0;0;0;0;0;0;0;0;0;0;0;0;0;0;0;0;0;0;0;0;0;0;1;0;0;0;0;0;0;1;0;0;0;0;0;0;0;0;0;0;1;0;0;0;0;0;0;0;1;0;0;0;0;0;0;0;0;0;0;0;0;1;0;0;0;0;0;0;0;0;0;0;0;0;0;0;0;0;0;0;0;0;0;0;0;0;0;0;0;0;0;0;0;1;0;0;1;0;0;0;0;1;0;0;0;0;0;0;0;0;0;0;0;1;0;0;0;0;0;1;1;0;0;0;0;0;0;0;0;0;0;0;0;0;0;0;0;1;0;0;0;0;0;0;0;0;1;0;0;0;0;0;0;0;0;0;0;0;0;0;0;0;0;0;0;0;0;0;0;2;1;0;0;0;1;0;0;0;0;0;0;0;0;0;0;0;1;0;0;0;1;0;0;0;0;0;0;0;0;0;0;0;0;0;0;0;0;0;0;0;0;0;0;0;0;0;0;0;1;0;0;0;0;0;0;0;0;0;0;0;0;0;0;0;0;0;0;0;0;1;0;0;0;1;0;0;0;1;0;0;0;0;0;0;0;0;0;0;0;0;1;0;0;0;0;0;0;0;0;0;0;0;0;0;0;0;0;0;0;0;0;1;0;0;0;0;0;0;0;0;0;0;0;0;0;0;0;0;1;0;0;0;0;0;0;0;0;0;0;0;0;0;0;0;0;0;0;0;0;0;0;0;0;0;0;0;0;0;0;0;0;0;0;0;0;0;0;0;0;0;0;0;0;0;0;0;0;1;0;0;0;0;0;0;0;0;0;1;0;0;0;0;0;0;0;0;0;0;0;0;0;0;0;0;0;0;0;0;0;0;0;0;0;0;0;0;0;0;0;0;0;0;0;0;0;0;0;0;0;0;0;0;0;0;0;0;1;1;0;1;0;0;1;0;0;0;0;0;0;0;0;0;0;0;0;0;0;0;0;0;0;0;0;1;0;0;0;0;0;0;0;0;0;0;0;0;0;0;0;0;0;0;0;0;0;0;0;0;0;0;0;0;0;0;0;0;0;0;0;1;0;0;0;0;1;0;0;0;0;0;0;0;0;0;0;0;0;0;0;0;1;0;0;0;0;0;0;0;0;0;0;0;0;0;0;0;0;0;0;0;0;0;0;0;0;0;0;0;2;0;0;0;0;0;0;0;0;0;0;0;0;0;0;0;0;0;0;0;0;0;0;0;0;0;0;0;0;0;0;0;0;0;0;0;0;0;1;0;0;0;0;0;0;1;0;0;0;0;0;0;0;0;0;0;0;0;0;1;0;0;0;0;0;0;0;1;0;0;1;0;0;0;0;0;0;0;0;0;0;0;0;0;0;0;0;0;0;0;0;0;0;0;0;0;0;1;0;0;0;0;0;0;0;0;0;0;0;0;0;0;0;0;0;0;0;0;0;0;0;0;0;0;0;0;0;0;0;0;0;0;0;0;0;0;0;0;0;1;0;0;0;0;0;0;0;0;0;0;0;0;0;0;0;0;0;0;0;0;0;0;0;0;0;0;0;0;0;0;0;0;0;0;0;0;0;0;0;0;0;0;0;0;0;0;0;0;0;0;0;0;0;0;0;0;0;0;0;0;0;0;0;0;0;0;0;0;0;0;0;0;0;0;0;0;0;0;0;0;0;0;0;0;0;0;0;0;0;0;1;0;0;0;0;0;0;0;0;0;0;0;0;0;0;0;0;0;0;0;0;1;0;0;0;0;0;0;0;0;0;0;0;0;0;0;0;0;0;0;0;0;0;0;0;0;0;0;0;0;0;0;0;0;0;0;0;0;0;1;0;0;0;0;0;0;0;0;0;0;0;0;0;0;0;0;0;1;0;0;0;1;0;0;0;0;0;0;0;0;0;0;0;0;0;0;0;0;0;0;0;0;0;1;0;0;0;0;0;0;0;0;0;0;0;0;0;0;0;0;0;0;1;0;0;0;0;0;0;0;0;0;1;0;0;0;0;0;0;0;0;0;0;0;0;0;0;0;0;0;0;0;0;0;1;0;1;0;0;0;0;0;0;0;0;0;0;0;0;0;0;0;0;0;0;0;0;0;0;0;0;0;0;0;0;0;0;0;0;0;0;0;0;0;0;0;0;0;0;0;0;0;0;0;0;0;0;0;0;0;0;0;0;0;0;0;0;1;0;0;0;0;0;0;0;0;0;0;0;0;0;0;0;0;0;0;0;0;0;0;0;0;0;0;0;0;0;0;1;0;0;0;0;0;0;0;0;0;1;0;0;0;0;0;0;0;0;0;0;0;0;0;0;0;0;0;0;0;0;0;0;0;0;0;0;0;0;0;0;0;0;0;0;0;0;0;0;1;0;0;0;0;0;0;0;0;0;0;0;0;0;0;0;0;0;0;0;0;0;0;0;0;0;0;0;0;0;0;0;0;0;0;0;0;0;0;0;0;0;0;0;0;0;0;0;0;1;0;0;0;0;0;0;0;0;0;0;0;0;0;0;0;0;1;0;0;0;0;0;0;0;0;0;0;0;0;0;0;0;0;0;0;0;0;0;0;0;0;1;0;0;0;0;0;0;1;0;0;0;0;0;0;0;0;0;0;0;0;0;0;0;0;0;0;0;0;0;0;0;0;0;0;0;0;0;0;1;0;0;1;0;0;0;0;0;0;0;0;0;0;0;0;0;0;0;0;0;0;0;0;0;0;0;0;0;0;0;0;0;0;0;0;0;0;0;0;0;0;0;0;0;0;0;0;0;0;0;0;0;0;0;0;0;0;0;0;0;0;0;0;0;0;0;0;0;0;0;0;0;0;0;0;0;0;0;0;0;0;0;0;0;1;0;0;0;0;0;0;0;0;0;0;0;0;0;0;0;0;0;0;0;0;0;0;0;0;0;0;0;0;0;0;0;0;0;0;0;0;0;0;0;0;0;0;0;0;0;0;0;0;0;0;0;0;0;0;0;0;0;0;0;0;0;0;0;0;0;0;0;0;0;0;0;0;0;0;0;0;0;0;0;0;1;0;0;0;0;0;0;0;0;0;0;0;1;0;0;0;0;0;0;0;0;0;0;0;0;0;0;0;0;0;0;0;0;0;0;0;0;0;0;0;0;0;0;0;0;0;0;0;1;0;0;0;0;0;0;0;0;0;0;0;0;0;0;0;0;0;0;0;0;0;0;0;0;0;0;0;0;0;0;0;0;0;0;0;0;0;0;0;0;0;0;0;0;0;0;0;0;0;0;0;0;0;0;0;0;0;0;0;0;0;0;0;0;0;0;0;0;0;0;0;0;0;0;0;0;0;0;0;0;0;0;0;0;0;0;0;0;0;0;0;0;0;0;0;0;0;0;0;0;0;0;0;0;0;0;0;0;0;0;0;0;0;0;0;0;0;0;0;0;0;0;0;0;0;0;0;0;0;0;0;0;0;0;0;0;0;0;0;0;0;0;0;0;0;0;0;0;0;0;0;0;0;0;0;0;0;1;0;0;0;0;0;0;0;0;0;0;0;0;0;0;1;0;0;0;0;0;0;0;0;0;0;0;0;0;0;0;0;0;0;0;0;0;0;0;0;0;0;0;0;0;0;0;0;0;0;0;0;0;1;0;0;0;0;0;0;0;0;0;0;0;0;0;0;0;0;0;0;0;0;0;0;0;0;0;0;0;0;0;1;0;0;0;0;0;0;0;0;0;0;0;0;0;0;0;0;0;0;0;0;0;0;0;0;0;1;0;0;0;0;0;0;0;0;0;0;1;0;0;0;0;0;0;0;0;0;0;0;0;0;0;0;0;0;0;0;0;0;0;0;0;0;0;0;0;0;0;0;0;0;0;0;0;0;0;0;0;0;0;0;0;0;0;0;0;0;0;0;0;0;0;0;0;0;0;0;0;0;0;0;0;0;0;0;0;0;0;0;0;0;0;0;0;0;0;0;0;0;0;0;0;0;0;0;0;0;0;0;0;0;0;0;0;0;0;0;0;0;0;0;0;0;0;0;0;0;0;2;0;0;0;0;0;0;0;0;0;0;0;0;0;0;0;0;0;0;0;0;0;0;0;0;0;0;0;0;0;0;0;0;0;0;0;0;0;0;0;0;0;0;0;0;0;0;0;0;0;0;0;0;0;0;0;0;0;0;0;0;0;0;0;0;0;0;0;0;0;0;0;0;0;0;0;0;0;0;0;0;0;0;0;0;0;0;0;0;0;0;0;0;0;0;0;0;0;0;0;0;0;0;0;0;0;0;0;0;0;1;0;0;0;0;0;0;0;0;0;0;0;0;0;0;0;0;0;0;0;0;0;0;0;0;0;0;0;0;0;0;0;0;0;0;0;0;0;0;0;0;0;0;0;0;0;0;0;0;0;0;0;0;0;0;0;0;0;0;0;0;0;0;0;0;0;0;0;0;0;0;0;0;0;0;0;0;0;0;0;0;0;0;0;0;0;0;0;0;0;0;0;0;0;0;0;0;0;0;0;0;0;0;0;0;0;0;0;0;0;0;0;0;0;0;0;0;0;0;0;0;0;0;0;0;0;0;0;0;0;0;0;0;0;0;0;0;0;0;0;0;0;0;0;0;0;0;0;0;0;0;0;0;0;0;0;0;0;0;0;0;0;0;0;0;0;0;0;0;0;0;0;0;0;0;0;0;0;0;0;0;0;0;0;0;0;0;0;0;0;0;0;0;0;0;0;0;0;0;0;0;0;0;0;0;0;0;0;0;0;0;0;0;0;0;0;0;0;0;0;0;0;0;0;0;0;0;0;0;0;0;0;0;0;0;0;0;0;0;0;0;0;0;0;0;0;0;0;0;0;0;0;0;0;0;0;0;0;0;0;0;0;0;0;0;0;0;0;0;0;0;0;0;0;0;0;0;0;0;0;0;0;0;0;0;0;0;0;0;0;0;0;0;0;0;0;0;0;0;0;0;0;0;0;0;0;0;0;0;0;0;0;0;0;0;0;0;0;0;0;0;0;0;0;0;0;0;0;0;0;0;0;0;0;0;0;0;0;0;0;0;0;0;0;0;0;0;0;0;0;0;0;0;0;0;0;0;0;0;0;0;0;0;0;0;0;0;0;0;0;0;0;0;0;0;0;0;0;0;0;0;0;0;0;0;0;0;0;0;0;0;0;0;0;0;0;0;0;0;0;0;0;0;0;0;0;0;0;0;0;0;0;0;0;0;0;0;0;0;0;0;0;0;0;0;0;0;0;0;0;0;0;0;0;0;0;0;0;0;0;0;0;0;0;0;0;0;0;0;0;0;0;0;0;0;0;0;0;0;0;0;0;0;0;0;0;0;0;0;0;0;0;0;0;0;0;0;0;0;0;0;0;0;0;0;0;0;0;0;0;0;0;0;0;0;0;0;0;0;0;0;0;0;0;0;0;0;0;0;0;0;0;0;0;0;0;0;0;0;0;0;0;0;0;0;0;0;0;0;0;0;0;0;0;0;0;0;0;0;0;0;0;0;0;0;0;0;0;0;0;0;0;0;0;0;0;0;0;0;0;0;0;0;0;0;0;0;0;0;0;0;0;0;0;0;0;0;0;0;0;0;0;0;0;0;0;0;0;0;0;0;0;0;0;0;0;0;0;0;0;0;0;0;0;0;0;0;0;0;0;0;0;0;0;0;0;0;0;0;0;0;0;0;0;0;0;0;0;0;0;0;0;0;0;0;0;0;0;0;0;0;0;0;0;0;0;0;0;0;0;0;0;0;0;0;0;0;0;0;0;0;0;0;0;0;0;0;0;0;0;0;0;0;0;0;0;0;0;0;0;0;0;0;0;0;0;0;0;0;0;0;0;0;0;0;0;0;0;0;0;0;0;0;0;0;0;0;0;0;0;0;0;0;0;0;0;0;0;0;0;0;0;0;0;0;0;0;0;0;0;0;0;0;0;0;0;0;0;0;0;0;0;0;0;0;0;0;0;0;0;0;0;0;0;0;0;0;0;0;1;0;0;0;0;0;0;0;0;0;0;0;0;0;0;0;0;0;0;0;0;0;0;0;0;0;0;0;0;0;0;0;0;0;0;0;0;0;0;0;0;0;0;0;0;0;0;0;0;0;0;0;0;0;0;0;0;0;0;0;0;0;0;0;0;0;0;0;0;0;0;0;0;0;0;0;0;0;0;0;0;0;0;0;0;0;0;0;0;0;0;0;0;0;0;0;0;0;0;0;0;0;0;4;
13;0;0;0;0;0;0;0;0;0;0;0;0;0;0;0;0;0;0;0;0;0;0;0;0;0;0;0;0;0;0;0;0;0;0;0;0;0;0;0;0;0;0;0;0;0;0;0;0;0;0;0;0;0;0;0;0;0;0;0;0;0;0;0;0;0;0;0;0;0;0;0;0;0;0;0;0;0;0;0;0;0;0;0;0;0;0;0;0;0;0;0;0;0;0;0;0;0;0;0;0;0;0;0;0;0;0;0;0;0;0;0;0;0;0;0;0;0;0;0;0;0;0;0;0;0;0;0;0;0;0;0;0;0;0;0;0;0;0;0;0;0;0;0;0;0;0;0;0;0;0;0;1;1;1;0;0;0;0;1;0;0;0;0;0;0;0;0;0;0;0;0;0;0;0;0;0;0;0;0;0;0;0;0;0;0;0;0;0;0;1;1;0;0;1;0;0;0;0;0;0;0;0;0;3;1;3;0;4;1;1;0;2;1;1;0;0;1;1;1;1;2;1;0;2;0;0;1;2;1;0;0;0;2;1;1;1;1;1;1;0;1;2;2;0;1;0;1;0;2;0;3;3;1;0;2;0;0;2;2;1;0;0;0;1;2;1;1;0;0;1;0;0;3;0;1;2;1;0;0;0;0;3;0;0;3;2;1;0;0;2;2;1;1;2;1;1;4;3;1;1;1;3;0;1;2;1;2;3;1;2;5;2;0;3;2;1;4;3;3;1;4;2;3;1;3;0;5;4;6;4;0;2;3;1;1;1;4;0;4;3;2;2;3;1;4;4;5;3;5;5;4;4;1;8;3;1;4;2;4;2;5;4;2;2;7;3;2;1;2;2;5;3;2;2;3;3;4;3;2;4;4;3;4;5;1;3;3;5;4;1;5;3;1;4;5;3;2;4;1;6;3;3;2;3;4;4;1;2;1;3;8;3;2;4;0;4;1;2;2;5;2;1;2;4;4;2;7;2;2;2;2;2;3;1;5;5;5;1;3;3;4;5;3;2;4;1;3;2;2;2;0;2;3;0;3;2;4;4;2;4;5;0;2;0;3;3;3;3;4;1;2;1;2;4;4;3;1;3;0;2;2;3;4;1;4;1;1;1;3;2;1;5;4;0;1;0;2;0;3;1;2;6;0;1;0;4;5;3;3;2;0;2;6;3;2;2;2;4;0;0;1;2;3;5;4;2;3;0;2;2;3;3;1;0;0;0;1;2;1;0;1;2;3;2;3;2;3;1;4;0;4;8;0;1;0;3;1;1;1;1;2;1;0;1;3;2;2;1;1;2;0;3;3;0;3;3;0;2;2;2;0;2;0;0;3;2;2;3;0;0;0;0;2;4;1;0;2;1;2;1;1;3;3;1;2;3;4;0;3;4;0;1;1;1;1;0;0;1;2;1;3;0;1;3;0;2;0;0;0;0;0;0;1;2;2;1;2;0;1;0;2;1;3;3;1;2;1;0;3;2;1;1;1;0;0;1;0;0;2;2;2;1;1;1;2;0;2;0;2;1;2;0;1;1;0;0;0;0;0;0;1;1;0;1;0;2;2;2;0;0;2;3;3;1;0;3;2;1;0;1;1;2;1;3;1;1;1;1;0;2;0;1;2;1;0;1;0;0;0;1;0;3;0;0;1;0;1;1;2;1;0;0;0;2;0;0;1;1;1;0;2;0;0;1;0;0;3;0;1;0;1;0;2;0;0;3;1;1;1;0;2;1;0;1;0;0;0;1;0;1;2;0;0;1;0;0;0;1;0;0;0;0;0;0;0;0;0;0;1;1;1;0;3;1;0;2;0;2;0;0;1;0;2;1;0;0;0;0;0;1;2;0;0;0;0;3;0;2;1;1;1;1;0;0;0;1;2;0;0;0;0;1;0;2;0;0;0;0;0;0;0;0;0;1;0;0;0;1;2;3;0;0;0;0;0;0;0;0;1;0;1;0;0;0;0;0;0;0;0;1;0;0;0;1;0;1;1;0;1;0;0;0;0;0;1;0;0;0;0;0;0;0;1;2;0;0;0;1;1;0;0;1;1;0;0;0;0;0;0;1;1;0;0;1;0;1;0;0;0;0;0;1;0;0;1;0;0;1;0;0;0;0;0;0;0;0;0;1;0;0;0;0;0;0;0;0;2;1;0;0;0;0;0;0;1;0;0;0;0;0;0;0;0;0;0;0;1;0;0;0;0;1;1;0;0;0;0;0;0;0;0;0;0;1;0;0;0;0;0;0;0;1;0;1;1;1;0;1;0;0;0;0;0;1;0;1;0;0;1;0;0;0;0;0;0;0;0;0;0;0;0;1;0;0;0;1;0;1;0;0;0;0;0;0;0;0;0;0;0;0;0;0;0;0;0;1;0;0;0;0;0;0;1;0;1;0;1;1;0;0;0;0;0;0;0;0;1;2;1;0;1;0;0;0;0;0;0;0;1;0;0;0;1;0;0;0;0;1;0;1;0;0;0;0;0;0;0;0;0;0;3;0;0;0;1;0;0;1;0;0;1;0;0;0;0;0;1;1;0;0;1;0;0;0;0;0;0;0;0;0;0;0;0;0;0;0;0;0;0;1;1;0;0;0;0;0;0;0;0;0;1;0;0;0;0;0;0;0;0;0;0;1;0;0;0;0;0;0;0;0;0;0;0;0;0;0;0;0;0;0;0;0;0;0;1;0;0;0;0;0;1;0;0;0;0;0;2;0;0;0;0;0;0;0;1;0;0;1;0;0;0;0;0;0;0;0;0;0;0;1;0;0;0;0;0;0;0;0;0;0;0;0;0;0;0;0;0;0;0;0;0;0;0;0;0;0;0;0;1;0;0;0;0;0;0;0;0;0;0;1;0;0;0;0;0;0;0;0;0;0;0;1;0;0;0;0;0;0;1;0;0;0;0;0;1;0;1;0;0;0;0;0;0;0;0;0;0;0;0;0;0;0;0;0;1;0;0;0;0;1;0;0;0;0;0;0;0;0;0;0;0;0;1;1;0;0;1;0;1;0;0;0;0;0;0;0;0;0;0;0;0;0;1;0;0;0;0;0;0;0;0;0;0;0;0;0;0;0;0;0;0;0;0;0;0;0;0;1;0;0;0;0;0;0;1;0;0;0;0;0;0;0;0;0;0;1;0;0;0;0;0;0;0;1;0;0;0;0;0;0;0;0;0;0;0;0;1;0;0;0;0;0;0;0;0;0;0;0;0;0;0;0;0;0;0;0;0;0;0;0;0;0;0;0;0;0;0;0;1;0;0;1;0;0;0;0;1;0;0;0;0;0;0;0;0;0;0;0;1;0;0;0;0;0;1;1;0;0;0;0;0;0;0;0;0;0;0;0;0;0;0;0;1;0;0;0;0;0;0;0;0;1;0;0;0;0;0;0;0;0;0;0;0;0;0;0;0;0;0;0;0;0;0;0;2;1;0;0;0;1;0;0;0;0;0;0;0;0;0;0;0;1;0;0;0;1;0;0;0;0;0;0;0;0;0;0;0;0;0;0;0;0;0;0;0;0;0;0;0;0;0;0;0;1;0;0;0;0;0;0;0;0;0;0;0;0;0;0;0;0;0;0;0;0;1;0;0;0;1;0;0;0;1;0;0;0;0;0;0;0;0;0;0;0;0;1;0;0;0;0;0;0;0;0;0;0;0;0;0;0;0;0;0;0;0;0;1;0;0;0;0;0;0;0;0;0;0;0;0;0;0;0;0;1;0;0;0;0;0;0;0;0;0;0;0;0;0;0;0;0;0;0;0;0;0;0;0;0;0;0;0;0;0;0;0;0;0;0;0;0;0;0;0;0;0;0;0;0;0;0;0;0;1;0;0;0;0;0;0;0;0;0;1;0;0;0;0;0;0;0;0;0;0;0;0;0;0;0;0;0;0;0;0;0;0;0;0;0;0;0;0;0;0;0;0;0;0;0;0;0;0;0;0;0;0;0;0;0;0;0;0;1;1;0;1;0;0;1;0;0;0;0;0;0;0;0;0;0;0;0;0;0;0;0;0;0;0;0;1;0;0;0;0;0;0;0;0;0;0;0;0;0;0;0;0;0;0;0;0;0;0;0;0;0;0;0;0;0;0;0;0;0;0;0;1;0;0;0;0;1;0;0;0;0;0;0;0;0;0;0;0;0;0;0;0;1;0;0;0;0;0;0;0;0;0;0;0;0;0;0;0;0;0;0;0;0;0;0;0;0;0;0;0;2;0;0;0;0;0;0;0;0;0;0;0;0;0;0;0;0;0;0;0;0;0;0;0;0;0;0;0;0;0;0;0;0;0;0;0;0;0;1;0;0;0;0;0;0;1;0;0;0;0;0;0;0;0;0;0;0;0;0;1;0;0;0;0;0;0;0;1;0;0;1;0;0;0;0;0;0;0;0;0;0;0;0;0;0;0;0;0;0;0;0;0;0;0;0;0;0;1;0;0;0;0;0;0;0;0;0;0;0;0;0;0;0;0;0;0;0;0;0;0;0;0;0;0;0;0;0;0;0;0;0;0;0;0;0;0;0;0;0;1;0;0;0;0;0;0;0;0;0;0;0;0;0;0;0;0;0;0;0;0;0;0;0;0;0;0;0;0;0;0;0;0;0;0;0;0;0;0;0;0;0;0;0;0;0;0;0;0;0;0;0;0;0;0;0;0;0;0;0;0;0;0;0;0;0;0;0;0;0;0;0;0;0;0;0;0;0;0;0;0;0;0;0;0;0;0;0;0;0;0;1;0;0;0;0;0;0;0;0;0;0;0;0;0;0;0;0;0;0;0;0;1;0;0;0;0;0;0;0;0;0;0;0;0;0;0;0;0;0;0;0;0;0;0;0;0;0;0;0;0;0;0;0;0;0;0;0;0;0;1;0;0;0;0;0;0;0;0;0;0;0;0;0;0;0;0;0;1;0;0;0;1;0;0;0;0;0;0;0;0;0;0;0;0;0;0;0;0;0;0;0;0;0;1;0;0;0;0;0;0;0;0;0;0;0;0;0;0;0;0;0;0;1;0;0;0;0;0;0;0;0;0;1;0;0;0;0;0;0;0;0;0;0;0;0;0;0;0;0;0;0;0;0;0;1;0;1;0;0;0;0;0;0;0;0;0;0;0;0;0;0;0;0;0;0;0;0;0;0;0;0;0;0;0;0;0;0;0;0;0;0;0;0;0;0;0;0;0;0;0;0;0;0;0;0;0;0;0;0;0;0;0;0;0;0;0;0;1;0;0;0;0;0;0;0;0;0;0;0;0;0;0;0;0;0;0;0;0;0;0;0;0;0;0;0;0;0;0;1;0;0;0;0;0;0;0;0;0;1;0;0;0;0;0;0;0;0;0;0;0;0;0;0;0;0;0;0;0;0;0;0;0;0;0;0;0;0;0;0;0;0;0;0;0;0;0;0;1;0;0;0;0;0;0;0;0;0;0;0;0;0;0;0;0;0;0;0;0;0;0;0;0;0;0;0;0;0;0;0;0;0;0;0;0;0;0;0;0;0;0;0;0;0;0;0;0;1;0;0;0;0;0;0;0;0;0;0;0;0;0;0;0;0;1;0;0;0;0;0;0;0;0;0;0;0;0;0;0;0;0;0;0;0;0;0;0;0;0;1;0;0;0;0;0;0;1;0;0;0;0;0;0;0;0;0;0;0;0;0;0;0;0;0;0;0;0;0;0;0;0;0;0;0;0;0;0;1;0;0;1;0;0;0;0;0;0;0;0;0;0;0;0;0;0;0;0;0;0;0;0;0;0;0;0;0;0;0;0;0;0;0;0;0;0;0;0;0;0;0;0;0;0;0;0;0;0;0;0;0;0;0;0;0;0;0;0;0;0;0;0;0;0;0;0;0;0;0;0;0;0;0;0;0;0;0;0;0;0;0;0;0;1;0;0;0;0;0;0;0;0;0;0;0;0;0;0;0;0;0;0;0;0;0;0;0;0;0;0;0;0;0;0;0;0;0;0;0;0;0;0;0;0;0;0;0;0;0;0;0;0;0;0;0;0;0;0;0;0;0;0;0;0;0;0;0;0;0;0;0;0;0;0;0;0;0;0;0;0;0;0;0;0;1;0;0;0;0;0;0;0;0;0;0;0;1;0;0;0;0;0;0;0;0;0;0;0;0;0;0;0;0;0;0;0;0;0;0;0;0;0;0;0;0;0;0;0;0;0;0;0;1;0;0;0;0;0;0;0;0;0;0;0;0;0;0;0;0;0;0;0;0;0;0;0;0;0;0;0;0;0;0;0;0;0;0;0;0;0;0;0;0;0;0;0;0;0;0;0;0;0;0;0;0;0;0;0;0;0;0;0;0;0;0;0;0;0;0;0;0;0;0;0;0;0;0;0;0;0;0;0;0;0;0;0;0;0;0;0;0;0;0;0;0;0;0;0;0;0;0;0;0;0;0;0;0;0;0;0;0;0;0;0;0;0;0;0;0;0;0;0;0;0;0;0;0;0;0;0;0;0;0;0;0;0;0;0;0;0;0;0;0;0;0;0;0;0;0;0;0;0;0;0;0;0;0;0;0;0;1;0;0;0;0;0;0;0;0;0;0;0;0;0;0;1;0;0;0;0;0;0;0;0;0;0;0;0;0;0;0;0;0;0;0;0;0;0;0;0;0;0;0;0;0;0;0;0;0;0;0;0;0;1;0;0;0;0;0;0;0;0;0;0;0;0;0;0;0;0;0;0;0;0;0;0;0;0;0;0;0;0;0;1;0;0;0;0;0;0;0;0;0;0;0;0;0;0;0;0;0;0;0;0;0;0;0;0;0;1;0;0;0;0;0;0;0;0;0;0;1;0;0;0;0;0;0;0;0;0;0;0;0;0;0;0;0;0;0;0;0;0;0;0;0;0;0;0;0;0;0;0;0;0;0;0;0;0;0;0;0;0;0;0;0;0;0;0;0;0;0;0;0;0;0;0;0;0;0;0;0;0;0;0;0;0;0;0;0;0;0;0;0;0;0;0;0;0;0;0;0;0;0;0;0;0;0;0;0;0;0;0;0;0;0;0;0;0;0;0;0;0;0;0;0;0;0;0;0;0;0;2;0;0;0;0;0;0;0;0;0;0;0;0;0;0;0;0;0;0;0;0;0;0;0;0;0;0;0;0;0;0;0;0;0;0;0;0;0;0;0;0;0;0;0;0;0;0;0;0;0;0;0;0;0;0;0;0;0;0;0;0;0;0;0;0;0;0;0;0;0;0;0;0;0;0;0;0;0;0;0;0;0;0;0;0;0;0;0;0;0;0;0;0;0;0;0;0;0;0;0;0;0;0;0;0;0;0;0;0;0;1;0;0;0;0;0;0;0;0;0;0;0;0;0;0;0;0;0;0;0;0;0;0;0;0;0;0;0;0;0;0;0;0;0;0;0;0;0;0;0;0;0;0;0;0;0;0;0;0;0;0;0;0;0;0;0;0;0;0;0;0;0;0;0;0;0;0;0;0;0;0;0;0;0;0;0;0;0;0;0;0;0;0;0;0;0;0;0;0;0;0;0;0;0;0;0;0;0;0;0;0;0;0;0;0;0;0;0;0;0;0;0;0;0;0;0;0;0;0;0;0;0;0;0;0;0;0;0;0;0;0;0;0;0;0;0;0;0;0;0;0;0;0;0;0;0;0;0;0;0;0;0;0;0;0;0;0;0;0;0;0;0;0;0;0;0;0;0;0;0;0;0;0;0;0;0;0;0;0;0;0;0;0;0;0;0;0;0;0;0;0;0;0;0;0;0;0;0;0;0;0;0;0;0;0;0;0;0;0;0;0;0;0;0;0;0;0;0;0;0;0;0;0;0;0;0;0;0;0;0;0;0;0;0;0;0;0;0;0;0;0;0;0;0;0;0;0;0;0;0;0;0;0;0;0;0;0;0;0;0;0;0;0;0;0;0;0;0;0;0;0;0;0;0;0;0;0;0;0;0;0;0;0;0;0;0;0;0;0;0;0;0;0;0;0;0;0;0;0;0;0;0;0;0;0;0;0;0;0;0;0;0;0;0;0;0;0;0;0;0;0;0;0;0;0;0;0;0;0;0;0;0;0;0;0;0;0;0;0;0;0;0;0;0;0;0;0;0;0;0;0;0;0;0;0;0;0;0;0;0;0;0;0;0;0;0;0;0;0;0;0;0;0;0;0;0;0;0;0;0;0;0;0;0;0;0;0;0;0;0;0;0;0;0;0;0;0;0;0;0;0;0;0;0;0;0;0;0;0;0;0;0;0;0;0;0;0;0;0;0;0;0;0;0;0;0;0;0;0;0;0;0;0;0;0;0;0;0;0;0;0;0;0;0;0;0;0;0;0;0;0;0;0;0;0;0;0;0;0;0;0;0;0;0;0;0;0;0;0;0;0;0;0;0;0;0;0;0;0;0;0;0;0;0;0;0;0;0;0;0;0;0;0;0;0;0;0;0;0;0;0;0;0;0;0;0;0;0;0;0;0;0;0;0;0;0;0;0;0;0;0;0;0;0;0;0;0;0;0;0;0;0;0;0;0;0;0;0;0;0;0;0;0;0;0;0;0;0;0;0;0;0;0;0;0;0;0;0;0;0;0;0;0;0;0;0;0;0;0;0;0;0;0;0;0;0;0;0;0;0;0;0;0;0;0;0;0;0;0;0;0;0;0;0;0;0;0;0;0;0;0;0;0;0;0;0;0;0;0;0;0;0;0;0;0;0;0;0;0;0;0;0;0;0;0;0;0;0;0;0;0;0;0;0;0;0;0;0;0;0;0;0;0;0;0;0;0;0;0;0;0;0;0;0;0;0;0;0;0;0;0;0;0;0;0;0;0;0;0;0;0;0;0;0;0;0;0;0;0;0;0;0;0;0;0;0;0;0;0;0;0;0;0;0;0;0;0;0;0;0;0;0;0;0;0;0;0;0;0;0;0;0;0;0;0;0;0;0;0;0;0;0;0;0;0;0;0;0;0;0;0;0;0;0;0;0;0;0;0;0;0;0;0;0;0;0;0;0;0;0;0;0;0;0;0;0;0;0;0;1;0;0;0;0;0;0;0;0;0;0;0;0;0;0;0;0;0;0;0;0;0;0;0;0;0;0;0;0;0;0;0;0;0;0;0;0;0;0;0;0;0;0;0;0;0;0;0;0;0;0;0;0;0;0;0;0;0;0;0;0;0;0;0;0;0;0;0;0;0;0;0;0;0;0;0;0;0;0;0;0;0;0;0;0;0;0;0;0;0;0;0;0;0;0;0;0;0;0;0;0;0;0;5;
```

## Standalone Data Recording

We can use the built-in flash on the Pico to save spectra that were recorded without any external connection like serial for example. This makes the whole process of collecting spectra a lot more reliable.

The Open Gamma Detector has a built-in feature that allows you to start a spectrum recording for a specified duration [minutes], which is in the end saved in flash under the specified filename. During the time of this recording the only thing the device needs is power. There is also regular auto-saving every 15 minutes so if the device would for whatever reason lose power or crash, you could recover most of the data.

While recording you have an option to query the status of the recording or stop it entirely via the serial interface. Additionally, a small icon will appear on the OLED display to indicate an ongoing recording.

After the recording has ended, you can use a number of serial commands to query the file system, such as printing directory and file contents and removing files from the filesystem.

The files are automatically saved in a compatible JSON format ([NPES-JSON](https://github.com/OpenGammaProject/NPES-JSON)), which you only need to copy paste from the serial interface once the recording is finished. The file can then be loaded in any compatible program, like [Gamma MCA](https://github.com/OpenGammaProject/Gamma-MCA) for viewing.

If flashed with the correct settings (see above), the flash filesystem on the Pico can hold around 150 - 300 spectra.

## I2C and OLED Support

The detector board features an I2C header where you can connect any standard SSD1306 or SH1106 OLED display that will be supported with minimal changes to the Arduino IDE sketch. If no display is connected the device will work as usual only via a Serial interface. You can also force the device _not_ to use the display even if one is connected via the I2C header, if you choose to do so for whatever weird reason.

**Please note:** The default state for the display is set to `off` due to some issues with the display library. For that reason, you have to manually enable it once you want to use it.

The default firmware uses a 128 x 64 px SSD1306 OLED. If you want to change the display resolution or switch to SH1106-based screens, you will have to recompile and upload the Arduino sketch to your device.

At the moment the software only draws the energy spectrum and the current cps value to the screen in energy mode. These stats are reset once a specific number of counts have been collected - this number can be changed in the Arduino sketch. This is sufficient in most (simple) cases and more features will be implemented over time.

In Geiger mode the min/max cps as well as the average cps will be displayed on the screen.

OLED display
_(Photo of an older Rev 3 board, but you get the gist)_

Of course the I2C header can also be used for any other I2C devices, not only displays! But you will have to write the software on your own.

## SPI

Broken-out hardware SPI pins are present on the revision 4.x boards with the correct pins already configured in the Arduino sketch. These pins can be used to add an SD Card, a non-volatile FRAM storage chip or whatever else really.

## UART

Broken-out hardware UART pins are also present on the revision 4.x boards. These can be used to communicate with the device over something like an FTDI USB-to-Serial converter if you don't want to use the USB Serial interface. With this you can also use the Open Gamma Detector with Gamma MCA on a mobile device such as an Android phone.

The device will automatically print to all the interfaces that are connected to it, so you don't need to enable or disable anything at all for this to work.

## True Random Number Generator

Radioactive decay is a great source of entropy for a random number generator of course. This device can output true random numbers meaning they are truly, per definition, random, instead of the pseudorandom numbers a PRNG (i.e., an algorithm) can produce. At least if my implementation is correct of course. So you have to somewhat trust me that I didn't make some kind of stupid mistake. I did some crude tests and the numbers look very random to me. They certainly also all have the same chance of being generated over a reasonable test period, which is good. However, I still recommend you to regard this as more of a nice gimmick instead of something to generate PGP keys with to leak confidential NSA data to a journalist or to encrypt your multi-billion dollar bitcoin fortune.

If you enable the TRNG via the serial command, it will periodically (once they are ready) output random numbers between 0 - 255. This could be further used to, for example, periodically re-seed a pseudorandom number generator to increase the overall amount of available numbers to use. Note that the TRNG uses the same Serial connection as the gamma spectroscopy output, so you have to disable one of them so that you don't mix the outputs. The numbers of both functions are formatted the same for ease of use, i.e. with a semicolon ";" as some kind of "end of data" delimiter.

## Data Analysis & Live Plotting

To get the data from the detector, a serial connection (either the serial-over-USB port or hardware UART) is used by default. The quickest and easiest way to do this is by using my own web application called [Gamma MCA](https://spectrum.nuclearphoenix.xyz/) where you can connect straight to the serial port and plot the data live as well as import and export finished spectrum files and communicate over a serial console. You don't even need to install it, it can work out of any Chrome-based browser! Please head to the [repository](https://github.com/OpenGammaProject/Gamma-MCA) to find more specific info about this project.

**TL;DR:** [Youtube Teaser](https://www.youtube.com/watch?v=dkMhoUwDla0)

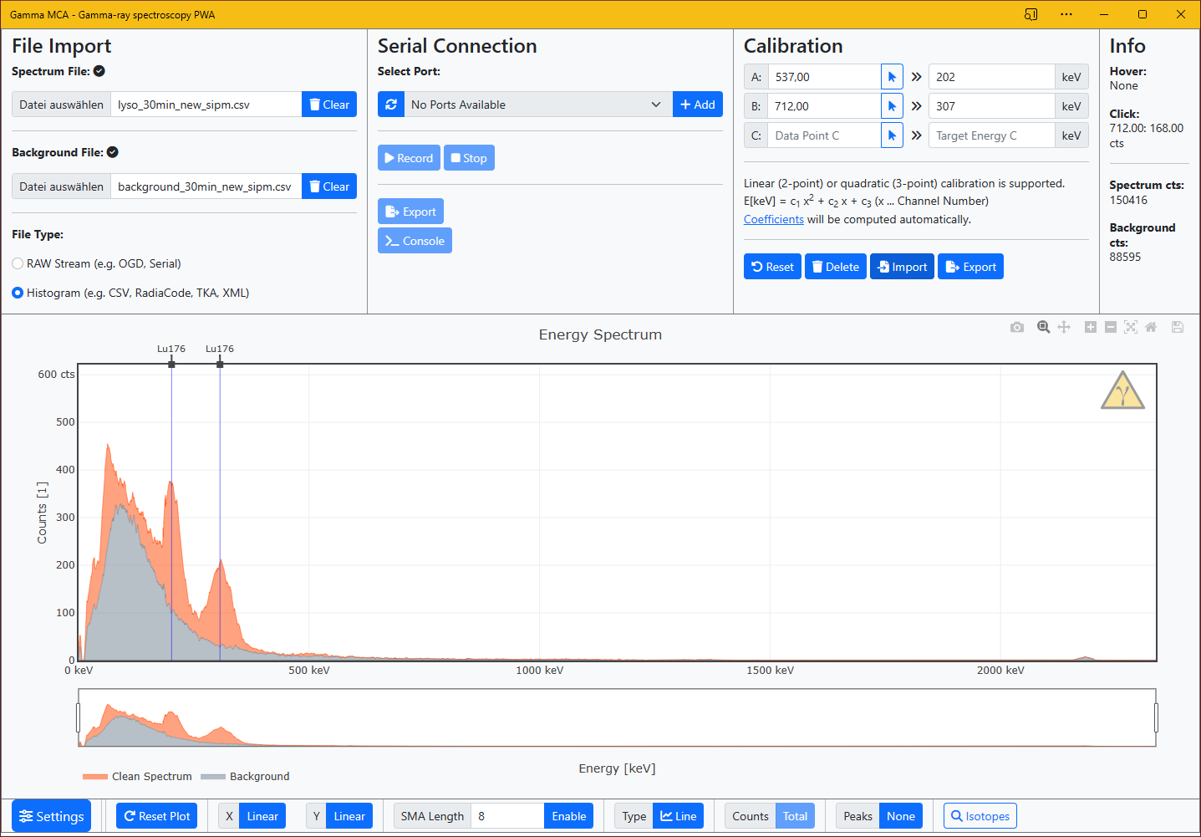
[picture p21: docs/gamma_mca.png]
Gamma MCA Screenshot


You can of course use any other serial monitor or gamma-spectroscopy software that's compatible with serial connections. To my knowledge there isn't much, though, that's why I made one myself.

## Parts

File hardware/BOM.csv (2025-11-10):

ID | Name | Designator | Footprint | Quantity | Manufacturer Part | Manufacturer | Supplier | Supplier Part | Price
1 | 2700Hz | BUZZER1 | BUZ-SMD_4P-L7.5-W7.5-P7.59-TL | 1 | MLT-7525 | 华能 | LCSC | C95299 | 0.226
2 | PMEG4010BEA | D1,D4 | SOD-323_L1.8-W1.3-LS2.5-RD | 2 | PMEG4010BEA,115 | Nexperia(安世) | LCSC | C36975 | 1.315
3 | PM2.54-1*10 | H1 | HDR-TH_10P-P2.54-V-F | 1 | PM2.54-1*10 | ZHOURI(洲日) | LCSC | C5116489 | 0.106
4 | 2.54-1*4P母 | H2 | HDR-TH_4P-P2.54-V-F | 1 | 2.54-1*4P母 | BOOMELE(博穆精密) | LCSC | C2718488 | 0.047
5 | HJ-MCX009 | H3,H4 | ANT-TH_L6.0-W6.0_MCX-KE | 2 | HJ-MCX009 | 皇捷 | LCSC | C2904906 | 0.724
6 | 47uH | L1 | IND-SMD_L4.0-W4.0_NR4018T | 1 | NRS4018T470MDGJ | TAIYO YUDEN(太诱) | LCSC | C222886 | 0.126
7 | 2N7002,215 | Q1,Q2 | SOT-23_L2.9-W1.3-P1.90-LS2.4-BR | 2 | 2N7002,215 | Nexperia(安世) | LCSC | C65189 | 0.161
8 | 1kΩ | R1,R4,R5,R7,R11,R12,R16 | R0603 | 7 | ARG03BTC1001 | Viking(光颉) | LCSC | C309080 | 0.019
9 | 100Ω | R6,R10,R19 | R0603 | 3 | 0603WAF1000T5E | UNI-ROYAL(厚声) | LCSC | C22775 | 0.001
10 | 210kΩ | R9,R14,R15,R17,R21 | R0603 | 5 | TC0325D2103T5H | UNI-ROYAL(厚声) | LCSC | C517422 | 0.023
11 | TSC015A03526A | SW1 | SW-SMD_4P-L4.5-W4.5-P3.00-LS6.8 | 1 | TSC015A03526A | BZCN(博众电气) | LCSC | C2888900 | 0.011
12 | TLV3201AIDBVR | U1 | SOT-23-5_L3.0-W1.7-P0.95-LS2.8-BR | 1 | TLV3201AIDBVR | TI(德州仪器) | LCSC | C105188 | 0.402
13 | LM4040AIM3-3.0+T | U2,U6 | SOT-23-3_L2.9-W1.6-P1.90-LS2.8-BR | 2 | LM4040AIM3-3.0+T | ADI(亚德诺)/MAXIM(美信) | LCSC | C143326 | 1.381
14 | RASPBERRY PI PICO 2 | U3 | PI-PICO-SMD | 1 | SC1631 | Raspberry Pi | Mouser | 358-SC1631
15 | 4.7uF | C1,C5,C16,C17 | C0805 | 4 | CL21A475KBQNNNE | SAMSUNG(三星) | LCSC | C98192 | 0.02
16 | BAT54S,215 | D2,D3 | SOT-23-3_L3.0-W1.7-P0.95-LS2.9-BR | 2 | BAT54S,215 | Nexperia(安世) | LCSC | C47546 | 0.016
17 | LTST-C190KGKT | LED1,LED2 | LED0603-RD | 2 | LTST-C190KGKT | LITEON(光宝) | LCSC | C125094 | 0.015
18 | 10kΩ | R3,R13,R18 | R0603 | 3 | ARG03FTC1002 | Viking(光颉) | LCSC | C217687 | 0.007
19 | 22uF | C6,C10,C11,C12,C13,C15 | C0603 | 6 | CL10A226MP8NUNE | SAMSUNG(三星) | LCSC | C86295 | 0.015
20 | 100nF | C2,C3,C4,C7,C9,C14 | C0603 | 6 | CL10B104KC8NNNC | SAMSUNG(三星) | LCSC | C15725 | 0.006
21 | 50kΩ | R2,R8 | RES-ADJ-TH_3296W | 2 | 3296W-1-503LF | BOURNS | LCSC | C83686 | 0.712
22 | OPA357AIDBVR | U4,U7,U8 | SOT-23-6_L2.9-W1.6-P0.95-LS2.8-BR | 3 | OPA357AIDBVR | TI(德州仪器) | LCSC | C139385 | 1.568
23 | MAX5026EUT+T | U5 | SOT-23-6_L2.9-W1.6-P0.95-LS2.8-BL | 1 | MAX5026EUT+T | ADI(亚德诺)/MAXIM(美信) | LCSC | C87603 | 1.696
24 | 470pF | C8 | C0603 | 1 | ECHU1C471JX5 | PANASONIC(松下) | LCSC | C178419 | 0.262
25 | 1kΩ | L2,L3,L4 | L0603 | 3 | BLM18KG102SN1D | muRata(村田) | LCSC | C160982 | 0.017

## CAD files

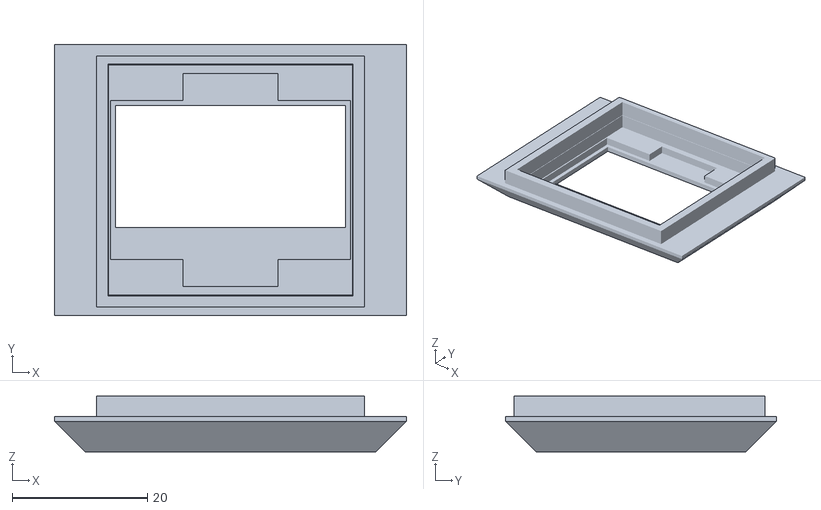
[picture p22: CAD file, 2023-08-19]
enclosure/enhanced/LCD_Bezel .stl
52.0 x 40.0 x 8.20

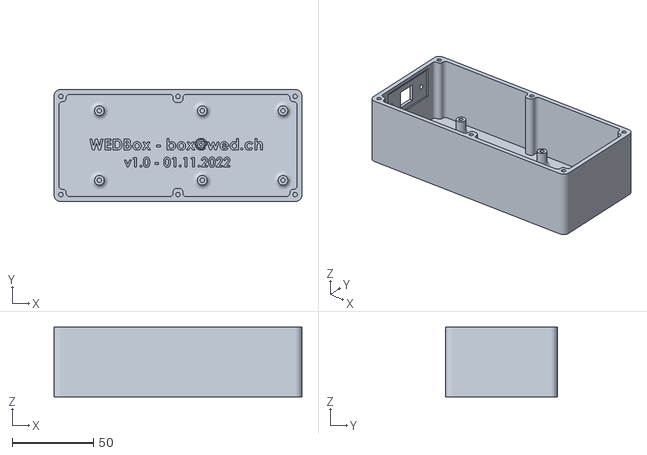
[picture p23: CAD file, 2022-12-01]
enclosure/simple/Case_Body_ReducedHeight_USB-B.STL
153.0 x 69.0 x 43.0

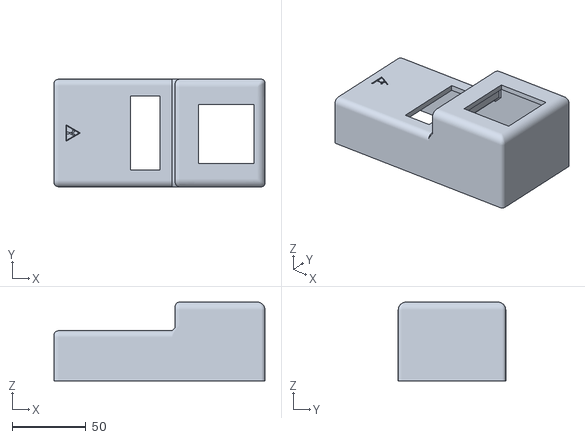
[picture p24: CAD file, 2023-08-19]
enclosure/enhanced/Case_Upper.stl
142.8 x 72.8 x 53.4

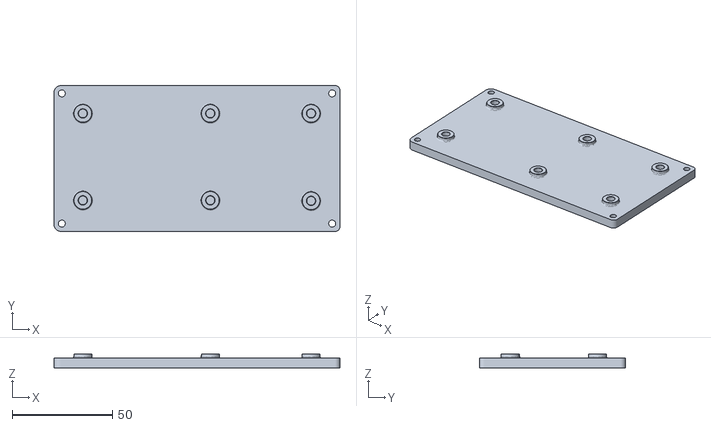
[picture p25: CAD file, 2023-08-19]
enclosure/enhanced/Case_Lower.stl
142.8 x 72.8 x 7.00

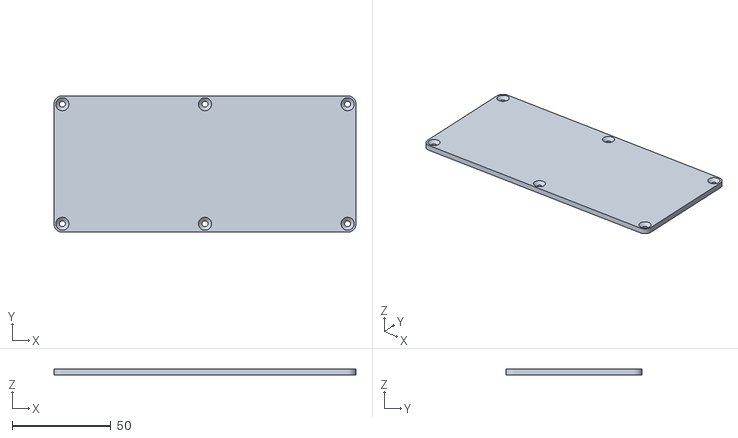
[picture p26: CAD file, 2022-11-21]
enclosure/simple/Case_Cover.STL
153.0 x 69.0 x 3.00

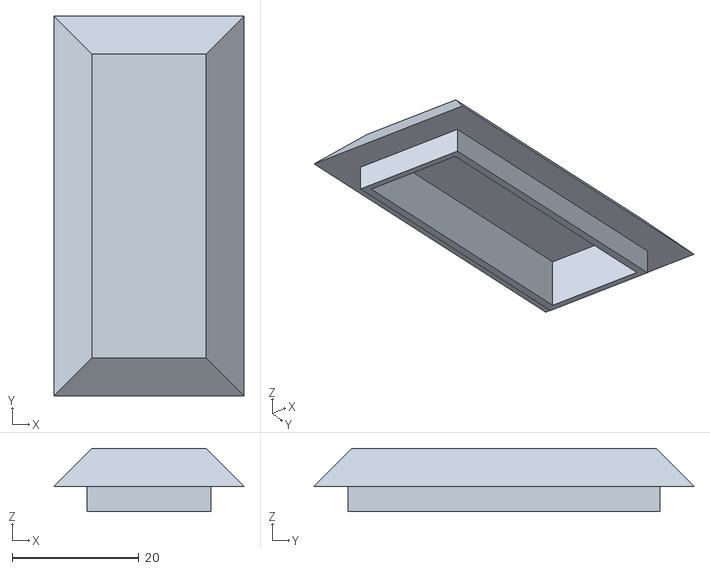
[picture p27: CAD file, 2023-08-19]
enclosure/enhanced/Panel_Cover.stl
30.0 x 60.0 x 10.0

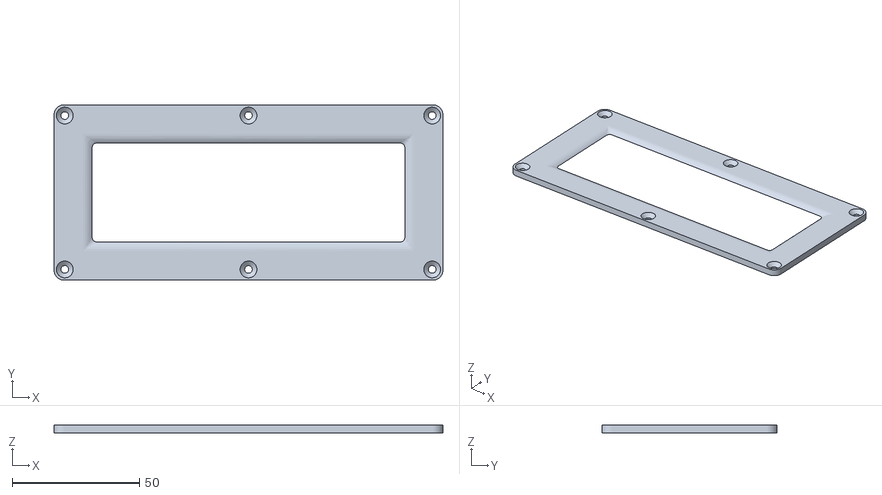
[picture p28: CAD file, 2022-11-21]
enclosure/simple/Case_Cover_Window.STL
153.0 x 69.0 x 3.00

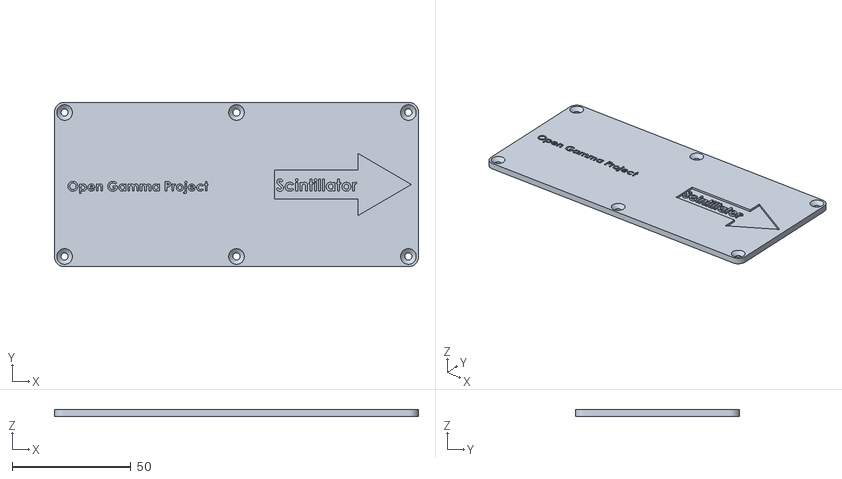
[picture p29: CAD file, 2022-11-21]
enclosure/simple/Case_Cover_OpenGamma.STL
153.0 x 69.0 x 3.00

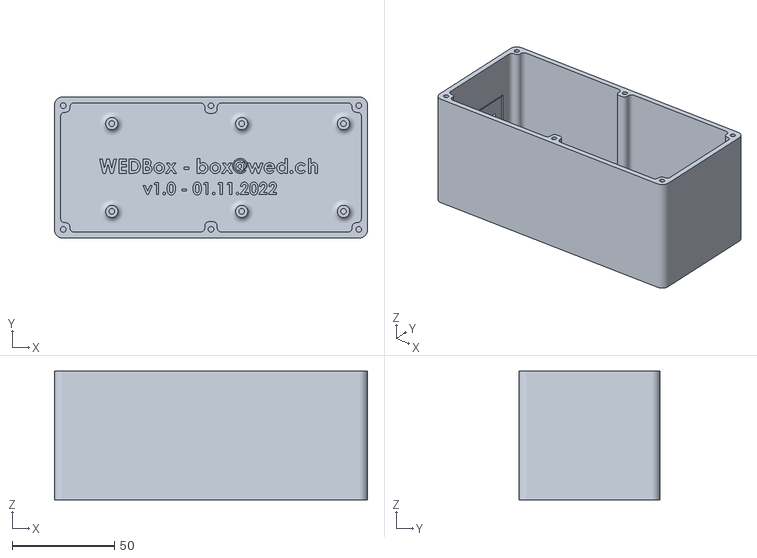
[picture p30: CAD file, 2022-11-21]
enclosure/simple/Case_Body_micro-USB.STL
153.0 x 69.0 x 63.0

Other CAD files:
enclosure/simple/Case_Body_ReducedHeight_micro-USB.STL
enclosure/simple/Case_Cover_Handle.STL
enclosure/simple/Case_Body_USB-B.STL

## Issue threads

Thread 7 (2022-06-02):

About amplification ratio

petrichor-m, 2022-06-02:
Hi!That is a great project!Thanks for sharing!
I noticed that the amplification ratio of SIPM signal in the circuit diagram is 300. Is that so? I also use the same SIPM (the bias voltage is 30V), but I will get a lot of dark counts at such a high amplification ratio. Is there a problem with my SIPM.
In addition, I want to know what R7 R16 does. Is it to add a bias voltage to the SIPM signal?
Thank you!

Phoenix1747, 2022-06-02:
> I noticed that the amplification ratio of SIPM signal in the circuit diagram is 300. Is that so?

No, the three 1k resistors are actually in parallel, so it's actually only 330 Ohms or a gain of ~34. I already know about the fixed gain issues, though. It's getting fixed in the next board revision!

> In addition, I want to know what R7 R16 does. Is it to add a bias voltage to the SIPM signal?

R16 is the recommended resistor value for this SiPM's readout. It's there to create a voltage drop with the current that the SiPM produces. R7 just raises the voltage at the op amp input (resistor divider) so that the tiny SiPM pulses get over the output swing of the amp.

petrichor-m, 2022-06-03:
Oh,I made a terrible misttake.For some reason I thought the resistors were in series.I shouldn't have.Thank you for you reply!

Closed 2022-06-08.

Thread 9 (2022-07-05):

Consider removal of radiation trefoil from silkscreen design

litmus-ritten, 2022-07-05:
Hi, cool project!

Radiation trefoils typically designate that something is **a)** radioactive or **b)** contains radioactive materials. The presence of a radiation trefoil on this detector may give the mistaken impression to people unfamiliar with the device that the detector falls into one of these two categories.

Phoenix1747, 2022-07-05:
You're completely correct, I have already removed it in the second revision of the board. It's coming very very soon 👍🏻

Don't know why I added it in the first place to be honest, such an unnecessary thing.

Phoenix1747, 2022-07-05:
See 70e3f56ebe0e749c65bd4cd521a97f2a77687a70.

Closed 2022-07-05.

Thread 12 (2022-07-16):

Substitute for MICROFC-60035-SMT-TR1

AndreiUlmeyda, 2022-07-16:
Hey there, awesome project!

I managed to buy most of the parts for this project but eventually I realised that the SiMP MICROFC-60035-SMT-TR1 seems to be out of stock everywhere I knew to look (mouser, digikey,etc.).

Do you happen to know a distributor who isnt't out of stock?

Alternatively, are there equivalent SiMPs which are more widely available and which could be integrated into the project with moderate effort?

Thanks in advance,

Adrian

Phoenix1747, 2022-07-16:
Hi there! Thanks for your interest :)

Unfortunately you're right, it seems like the SiPM is out of stock everywhere since the start of the Ukraine war according to [Octopart](https://octopart.com/microfc-60035-smt-tr1-onsemi-96322254?r=sp#InventoryHistory). Essentially you can use any other SiPM with roughly the similar specifications, the most important being the recommended (over)voltage -- that's why I made the SiPM gain and voltage variable with the new board.

You can look for any other MICROFC SiPM, maybe you still find one as they are all similar in specs, only different in sizes. At the moment, however, I'm mainly looking into the Broadcom AFBR-S4N66C013 which looks very similar to the MICROFC. The inventory looks great for now (thousands currently in stock with quick restocking intervals), but the only disadvantage of it is the BGA packaging.

https://octopart.com/afbr-s4n66c013-broadcom-100964440?r=sp
https://www2.mouser.com/ProductDetail/Broadcom-Avago/AFBR-S4N66C013?qs=T3oQrply3y%252B9kiyudO%2F1CA%3D%3D

I'm always looking for further alternatives, so if somebody has viable suggestions, feel free to reach out. Thanks!

AndreiUlmeyda, 2022-07-16:
Thanks for the info, I've just ordered one.

I'll keep you posted whether I manage to make it work or not :D

Cheers!

Phoenix1747, 2022-10-03:
Just to keep you updated here -- there is a new carrier board for the AFBR-S4N66C013 SiPM:

https://github.com/Open-Gamma-Project/AFBR-SiPM-Carrier-Board

At the moment, at least on Mouser there aren't any real alternatives in stock at all. Not even the evaluation boards for the MicroFC I think. The AFBR from Broadcom still has plenty of stock, though, so it's a good replacement if you can solder it 👍🏻

AndreiUlmeyda, 2022-10-09:
Wow, that is very nice! Thank you very much. It drastically improves my chance of success. I will probably try a makeshift hotplate for the BGA stuff. I will order the board right away. Have a very nice day, sir.

Phoenix1747, 2022-11-28:
Somewhat off-topic, but a new batch of MICROFC-60035-SMT SiPMs just arrived at Mouser.

https://eu.mouser.com/ProductDetail/onsemi/MICROFC-60035-SMT-TR1?qs=byeeYqUIh0MxSRIaBcfS6g%3D%3D

Will remove this post again as soon as it sold out, so that the thread stays on topic.

Phoenix1747, 2022-12-01:
I think I'll close this issue for now. To sum everything up:

There are two different SiPM series you can use at the moment:

- https://eu.mouser.com/ProductDetail/Broadcom-Avago/AFBR-S4N66C013?qs=T3oQrply3y%252B9kiyudO%2F1CA%3D%3D
- https://eu.mouser.com/ProductDetail/onsemi/MICROFC-60035-SMT-TR1?qs=byeeYqUIh0MxSRIaBcfS6g%3D%3D

These sensor series feature multiple different sizes, like 6mm, 4mm, 3mm, ... which you can all use.
Here are breakout boards for the two 6mm versions:

- https://github.com/Open-Gamma-Project/AFBR-SiPM-Carrier-Board
- https://github.com/Open-Gamma-Project/MicroFC-SiPM-Carrier-Board

If you find any other SiPM that supports the 30 V range, go for it! That's really the only, most important requirement.

However, the market for this is really small, obviously. So there aren't many different types of SiPMs at your average electronics distributor like Mouser or Digikey, especially the large 6mm versions. If you find another sensor that should be used, please contact me!

Closed 2022-12-01.

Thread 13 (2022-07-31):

4x1 header vs 3x2 header for SiPM

HazenBabcock, 2022-07-31:
Thank you for the fascinating project.

I have a question about the SiPM mount. The PCB of this project provides a connection for a 4x1 header to mount the SiPM. The apparent companion project [SiPM-Carrier-Board](https://github.com/Open-Gamma-Project/SiPM-Carrier-Board) has a 3x2 header. Is there something I don't understand about how these are supposed to work together? Or these projects are not actually related?

If they are not related would you recommend including the additional VCC filtering that the SiPM-Carrier-Board provides? Or is the filtering that is already part of the PCB of this project sufficient?

Phoenix1747, 2022-08-01:
Just uploaded the new carrier board PCB files (see e91c1b5157467a477cd668f4f80a455605af84f8 in [SiPM-Carrier-Board](https://github.com/Open-Gamma-Project/SiPM-Carrier-Board)). Like I said, the header is optional, but it's got the same pinout now too so you can plug it in if you use a male and a female header.

Closed 2022-08-01.

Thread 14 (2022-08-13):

Diode direction silk screen missing

AndreiUlmeyda, 2022-08-13:
Hey there, me again.

I've got all the parts together now and am in the process of soldering the board. I've noticed that on the older board (which still had the rad icon printed on it ;) there was direction information for diodes visible on the silk screen. It appears to me this is missing on the new board, as I imagine they are still directional components.

For now, I will try to infer the direction from the schematics.

Cheers, mate

AndreiUlmeyda, 2022-08-13:
Update:
Ive just downloaded the gerber files and opened them in KiCad. It seems the silk screen there contains a line for each of the diodes indicationg the direction. So either I've just ordered using older gerber files or they print wasn't the best. The board itself says its Rev2.0

Phoenix1747, 2022-08-13:
I've just checked the Gerber files again and you should definitely be able to see the cathode line. Maybe on your silk screen print it got lost to the adjacent pad, because it's really close to it? I don't know to be honest, there _should_ be a line. Where did you order your PCBs?

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

AndreiUlmeyda, 2022-08-13:
I ordered at JLPCP, heres a blurry picture of the situation, apart from that the board actually looks awesome
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
.

AndreiUlmeyda, 2022-08-13:
Another issue I've had is the orientation of U7 and U8. The markings of the 6pin versions, at least the one I've got, do not have a dot at all. They look like this, with the single dots being rougly where the pins are
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 [Here ](https://www.ti.com/lit/ds/symlink/opa357.pdf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) the datasheet, but I could not figure out if O, A, D and I refer to the pins in some way. I've soldered 2 of them under the assumption that the only asymmetrical feature, the bar over the I, corresponds to the location of the dot. Maybe I am being hasty, though.

Phoenix1747, 2022-08-13:
> I ordered at JLPCP, heres a blurry picture of the situation, apart from that the board actually looks awesome.

Okay, that is actually weird. In the JLCPCB Gerber preview it looks fine, but with Aisler it looks like that:

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

How much you can see of the small lines might depend then on the manufacturer. There is clearly a problem with the margin around the pads, I'll have a look at updating the diode silk screen to fix it. By the way, nice purple color you got there!

> Another issue I've had is the orientation of U7 and U8. The markings of the 6pin versions, at least the one I've got, do not have a dot at all. They look like this, with the single dots being rougly where the pins are

> [Here ](https://www.ti.com/lit/ds/symlink/opa357.pdf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) the datasheet, but I could not figure out if O, A, D and I refer to the pins in some way. I've soldered 2 of them under the assumption that the only asymmetrical feature, the bar over the I, corresponds to the location of the dot. Maybe I am being hasty, though. Do you have an idea about how to determine the orientation?

Actually the OADI is just the SMD device marking refering to the OPA357AIDBVR, OPA357AIDBVT or OPA357AIDBVTG4 which has nothing to do with the pinout. The wide bar to the left of the SMD code is the actual orientation marking. So it has to be oriented like that (grainy screenshot):

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

In general with most of these packages pin 1 is always to the left of the SMD code when you orient it so that you can read it. I have no idea what the other (horizontal) five bars mean though.

Phoenix1747, 2022-08-13:
Here is a sneak peak of the fully manufactured board (coming soon) that will probably help you. Here you can clearly see how all the components are laid out:
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

AndreiUlmeyda, 2022-08-13:
Aight, that means I took my 50/50 chance with the orientation and bombed it like a champ ^^
Thanks for being so helpful! I will try de- and resoldering them.

> nice purple color you got there

ikr :D

Give me a hint should you mind my pestering you with issues like that ;)

Have a very nice day

Phoenix1747, 2022-08-13:
> Give me a hint should you mind my pestering you with issues like that ;)

Oh no worries, that's what issues are here for ;)

Phoenix1747, 2022-08-19:
@AndreiUlmeyda Quick question: did you order multiple boards from JLCPCB? Do they all have the same silk screen issue? I know that silk screen by JLCPCB can be a bit wonky sometimes, so it would be good to know if it's a consistent issue 👍🏻

I just checked with my board made by makerfabs that I have lying around here and you can clearly make out the cathode line. It's close to the pad, though.

By the way, unrelated but make sure to change the 49.9Ω R3 to a 1k -- it decreases noise at lower energies!

AndreiUlmeyda, 2022-08-20:
@Phoenix1747 Hey there, it is very consistent over 5 boards, presumably all from the same batch. 3 diodes each, no cathode line even if one knows where to look. A little update on the project: I've noticed that I am missing the SIMP carrier board x]. And I've inspected the alternative SIMPs I've bought. I really hope my soldering tip is small enough to be able to solder the BGA stuff. Luckily, there do not  seem to be that many different different and/or close together leads, fat fingering a few balls together at the rough position of each lead could work.

An important question, though. Is the carrier board likely to be applicable to the alternative SIMP or are there modifications one would need to apply. If so, would you be able to provide guidance there?

Cheers

Phoenix1747, 2022-08-20:
> And I've inspected the alternative SIMPs I've bought. I really hope my soldering tip is small enough to be able to solder the BGA stuff. Luckily, there do not seem to be that many different different and/or close together leads, fat fingering a few balls together at the rough position of each lead could work.

Fortunately, there are only two signal levels on there with many other floating balls so you _should_ be able to get it running.

> An important question, though. Is the carrier board likely to be applicable to the alternative SIMP or are there modifications one would need to apply. If so, would you be able to provide guidance there?

I created the carrier board way before I even got to know this new SiPM and they have a completely different footprint so there is no way you can adapt it in its current state. I wanted to create and test a new board for a long time now, so I hope I get to it eventually. There is so much other stuff happening right now though, so feel free to help. Hope I understood your question right :D

Phoenix1747, 2023-04-11:
Should be fixed by Rev 3.0. Let me know if you still have this problem with the new diodes!

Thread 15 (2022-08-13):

R4 Missing in BOM file

AndreiUlmeyda, 2022-08-13:
Hey there, I am slowly progressing and am currently searching for R4.
It does not seem to be contained in the current BOM file.
Any tips on what I'm missing?

Since the other resistors number in the hundreds due to the minimum order quantity, there should be one I already have which can be used.

Cheers!

Phoenix1747, 2022-08-13:
Yes, that's a deliberate choice, it's an optional part. For low energies (<50 keV) I sometimes have a problem with the output voltage swing of the preamp and to mitigate that you can solder in R4 which will then raise the input voltage and therefore the output so that the signal is above the inherent swing of the op amp. This way you can read lower energies (voltages) for a fixed gain up to the SiPM noise.

But due to the preamp as well as SiPM gain being variable now and this voltage divider also introducing some noise into the signal I opted to leave this part out. If you want to play around with it and see what you can do, you can still solder the resistor that's why I left the pads for it.

AndreiUlmeyda, 2022-08-13:
Oh, yeah, thanks for the clarification. I read about the optional parts on the underside of the board but neglected this one.

Phoenix1747, 2022-08-13:
> I read about the optional parts on the underside of the board but neglected this one.

I just added it to the README ;) 106ad5de766cc2003750c1cc0018b859cd8c2e6b

Closed 2022-08-13.

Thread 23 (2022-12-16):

How to calibrate?

Erhannis, 2022-12-16:
In the readme, there's a diagram of potentiometers.  This suggests the device can (should?) be tuned or calibrated, but it doesn't explain how.  I don't know what kind of results to expect: I was vaguely expecting a spectrum in seconds or minutes, but the readme talks about collection times of two hours - so, I don't know what "right" looks like, to calibrate the device.  And, I think I understand what "gain" and "threshold" probably are - sorta, turning up the volume, and the lower limit that counts as an event, respectively, I think?  But I don't know what changing the voltage would do (and am nervous about adjusting it), nor do I know why there are two potentiometers R9 and R10 there.  Perhaps these things could be clarified in the readme?  (Or it could be split into separate pages, if the amount of info is getting too large for a single readme?)  Thanks!

Erhannis, 2022-12-16:
Originally I wasn't sure if the photomultiplier was even working or if I soldered it wrong - thankfully, opening the film canister yielded tens of thousands of events, so, pretty sure it's working, haha.

Erhannis, 2022-12-16:
I found that the hackaday instructions had some of this: https://hackaday.io/project/185211/instructions
I'm still not sure about some things, though.  For instance, could you give some expected background CPS for a couple types of scintillator?  How do we know what a "good" preamp gain is?  (And does "avoid the lowest and especially highest possible gains if you can, as these might be too unstable for the OpAmp to handle" mean something might be damaged, or just give poor signal?)  And in adjusting the voltage, "blinking" doesn't count the faint flickering of the LED, just the bright flashes, yeah?

Phoenix1747, 2022-12-16:
Hi,

In short, if you're using the ON semi MicroFC SiPM, just set the SiPM voltage to 29.5V or somewhere around this, however, not above 29.7. The two potentiometers are wired in series and will both, equally adjust the SiPM voltage. In the next revision I will likely remove one potentiometer, because with one you can still do enough fine adjustments. Once you set it, you don't need to change it ever really.

The preamp gain depends on a number of factors. Basically, turn it somewhere to the middle at first. So like 15 turns from either end. (You'll hear slight "clicks" when it's at one end). Try with this gain and from the spectrum you get, adjust it further to what you want (it will scale the whole spectrum larger or smaller, like zooming in and out).

The threshold, basically sets what minimum pulse voltages the board will trigger at. Below this, every signal will just be ignored. This must be set after the gain has been changed. Normal background will be at around 10 - 40 cps, I mostly get around 20-25 cps. Playing around with this value, you will see how the lowest energy you are detecting (i.e. the ADC channel) will shift. If you set it too high, nothing will be registered, if you set it too low, noise will overflow the system.

> (And does "avoid the lowest and especially highest possible gains if you can, as these might be too unstable for the OpAmp to handle" mean something might be damaged, or just give poor signal?)

No, nothing will break. You _might_ not get the best resolution. And especially at the lower end of the gain, due to the 20 Ohms limiting resistors, it will draw more current than usual and might clamp higher energy peaks. This is not really a problem if you're above a gain of 5-10 or so.

> And in adjusting the voltage, "blinking" doesn't count the faint flickering of the LED, just the bright flashes, yeah?

Exactly, faint flickering LED is just what you want. Bright, static LED is a saturated detector and you need to set the threshold higher.

Phoenix1747, 2022-12-16:
Once you set everything up, try and record a background spectrum. What you're aiming for should look something like this:

https://en.wikipedia.org/wiki/Landau_distribution#/media/File:Landau_Distribution_PDF.svg

Phoenix1747, 2022-12-16:
I'll update the hackaday instructions to reflect some of the things I said here.

Erhannis, 2022-12-16:
Great, thanks!  I didn't get any clicking on the gain potentiometer, and eventually gave up turning.  (I tried a similar potentiometer I had around, and did get clicking, so I don't know what's up.)  I turned 15 turns in the other direction, though, and I think I ended up in a usable area?  Thanks!

Phoenix1747, 2022-12-16:
Great, hope I could help you a little. Due to the nature of this project and the fact that you can choose to practically use any SiPM and scintillator in combination, it's really hard to pinpoint exact gain and threshold values. You have to slowly change individual parameters and see how the detector acts to get a feeling for everything.

Anyways, I'm already looking into some ways to make it easier in future hardware revisions and also, like I said, will update the hackaday instructions. Depending on how much time I have, I might as well write a comprehensive explanation on how all the different parameters change the output spectrum.

Feel free to close the issue if you're good now. You can always reopen it.

Erhannis, 2022-12-17:
Question!  "each turn adding a gain of about 3.3" - 3.3 what?  dB?  I think that's usually how gain is measured, yeah?  So if I wanted to zoom in by a factor of 5, I'd need to rotate the knob clockwise...7 times?

Erhannis, 2022-12-17:
Also - it seems like I'll turn the threshold until I get around 20 cpm, but then a minute later I look back and it's up around 200 cpm.  Does it usually drift like that?

Erhannis, 2022-12-17:
I took a background reading for an hour, then set the SIPM on a radioactive test sample from Amazon and took a spectrum for an hour.
[background_202212162204.csv](https://github.com/Open-Gamma-Project/Open-Gamma-Detector/files/10250642/background_202212162204.csv)
[spectrum_202212162204.csv](https://github.com/Open-Gamma-Project/Open-Gamma-Detector/files/10250643/spectrum_202212162204.csv)
Any idea what to make of these?  There's a huge spike at 214 - do I just have the threshold set too low?  (I get the idea the threshold just cuts off the low end, right?  The higher readings are unchanged?)  If I zoom in vertically, I see a weird repeating pattern across much of the data, though, in both the background and the sample spectrum.  Maybe EMI?  It seems like the presence of the test sample simply multiplied readings across the board, somehow.  I'm using the recommended SIPM in a film canister with a chunk of a plastic scintillator.  (I haven't put any grease etc. between them because it was just a rough test and I figured it would probably only slightly reduce readings, and uniformly.)

Phoenix1747, 2022-12-17:
> Question! "each turn adding a gain of about 3.3" - 3.3 what? dB?

No. It's just the voltage gain, so e.g. 10 mV input with a gain of 3.3 is 33.3 mV on the output.

> Also - it seems like I'll turn the threshold until I get around 20 cpm, but then a minute later I look back and it's up around 200 cpm. Does it usually drift like that?

It can drift a little bit at the beginning. That's why I make sure to turn it a tiny bit higher than needed. It shouldn't drift much after that, though. Are you sure about the 20 cpm, though? I have 20 counts per **second** with my NaI scintillator.

> There's a huge spike at 214 - do I just have the threshold set too low? (I get the idea the threshold just cuts off the low end, right? The higher readings are unchanged?)

Yes, exactly. This looks like the threshold and the gain both are set too low. Try increasing the gain a bit and setting the threshold again.
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
Phoenix1747, 2022-12-27:
@Erhannis How are you doing, could you make any progress?

@dc1rdb:
> my setup is facing a similar issue. No matter what gain / threshold / SiPM voltage setting is used, I cannot get rid of the huge spike on the very left side of the spectrum. It just moves a little left or right with the threshold setting.
> My detector is verified to be working fine and does not produce this kind of spike when hooked up to a RedPitaya running the multichannel analyzer.
> Can it be some kind of internal noise or oscillation?

Hm, interesting. I have two detectors here and neither exhibit the same problem, so debugging is a bit more difficult. "Some" peak is okay and to be expected from the noise, but it shouldn't be that high.
Does the spike change in height if you move the threshold? Does it disappear if you set the threshold to some much higher limit? Keep in mind that the peak at ADC channel 0 is deliberate and not due to noise, I'm not sure if you refer to that.

If the spike tracks your threshold, it sure looks like some noise problem. You could also try to reset the peak and hold circuitry more often by adjusting the delay time between resets in the Arduino sketch here:

https://github.com/Open-Gamma-Project/Open-Gamma-Detector/blob/46e91913f20cdb08816851c7413dd9045897558b/software/opengamma_pico/opengamma_pico.ino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

The default is a reset every 500 µs, try to change it to lower limits like 100 µs or even 50 µs, just for debugging. If the spike stays there, I think it's a problem with the (too low) pulse discriminator hysterisis, unfortunately.

What you could also try is soldering R4. This is just a standard 10k 0805 resistor and will increase the DC baseline of your pulses, if that's a problem with the op amps here. Have a look at the files:

[pcb_front](https://user-images.githubusercontent.com/17517687/209670463-4d09abf5-ef7c-4540-ab9c-99d463f8e753.png)
[schematic.pdf](https://github.com/Open-Gamma-Project/Open-Gamma-Detector/files/10308286/schematic.pdf)

dc1rdb, 2022-12-27:
Alright, here is a quick initial report:
- soldering R4 had no effect on the spike
- reducing the delay in line 746 apparently did the trick, with 100us the spike is significantly reduced and with 50us it is pretty much gone.

However, gain and threshold still need to be tuned to make the spectrum look as nice as the one I recorded with the RedPitaya multichannel analyzer.

RedPitaya MCA:
[Background10min.csv](https://github.com/Open-Gamma-Project/Open-Gamma-Detector/files/10310258/Background10min.csv)
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

OGD:
[500us10min.csv](https://github.com/Open-Gamma-Project/Open-Gamma-Detector/files/10310280/500us10min.csv)
[50us10min.csv](https://github.com/Open-Gamma-Project/Open-Gamma-Detector/files/10310253/50us10min.csv)

Thanks for your help!

Phoenix1747, 2022-12-27:
> * soldering R4 had no effect on the spike
> * reducing the delay in line 746 apparently did the trick, with 100us the spike is significantly reduced and with 50us it is pretty much gone.

Thanks for testing this. The tiny 220 pF capacitor used in the peak and hold circuitry is really sensitive to general EMI. Looks like the environment my devices are in, isn't as bad as yours. 😉
That's the only way I could explain this, to be honest. However, in the very early revisions of this project this was never a problem. So maybe it's also the PCB layout (more ground loops, ...). That cannot be changed obviously, but I'll start testing new PCBs for a new revision in the near future and maybe I can minimize the issue there 🙂

> Thanks for your help!

Glad I could help!

dc1rdb, 2022-12-28:
> Looks like the environment my devices are in, isn't as bad as yours, that's why it is not an issue here

Thats what I initially thought, too. But during my attempts to get rid of the spike, I took the unit outside away from any buildings whatsoever and had it powered with a battery. The spike was still unchanged on the little OLED display.
Well, those things happen. As a long time ham operator, I've had my share of hard to track interference and noise effects  😉

Phoenix1747, 2023-04-11:
Should be much easier to get going with the new revision 3.0 boards and the updated documentation. Let me know if you still have any problems.

Closed 2023-04-11.

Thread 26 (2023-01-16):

losing serial connection

oldbitman-ham, 2023-01-16:
I am using a MICROFC-30035-SMT-TR because I can't find the 60035.When I turn up the threshold until the red led is mostly on I lose the serial connection. Could this have something to do with the "delay" or "reset" settings? With careful adjustment of threshold and gain I can only get it up to 8 or 9 CPS. With it set here I will lose the serial when I send commands and if I reset or power cycle the serial won't come back until I reduce the threshold.
Any thoughts?

Phoenix1747, 2023-01-16:
Hi,
you're actually not supposed to have the LED mostly **on**, it should be the exact opposite (mostly **off**)! You're probably just saturating the device with noise. If you set it so that you can only see some very faint blinking then the device shouldn't die anymore. Depending on the cps you are reading then, you can play with the threshold again.

oldbitman-ham, 2023-01-17:
Thanks for the info, I was reading the instructions wrong. I am also finding that setting reset, averaging and delay have a huge effect. This is a very steep learning curve. Also should I use calibration in Gamma MCA app to set it to known sources?

Phoenix1747, 2023-01-17:
> I am also finding that setting reset, averaging and delay have a huge effect. This is a very steep learning curve.

If it works with the default settings, you don't need to change it. I would especially recommend leaving the auto reset on to deal with noise. The other settings are not too important if you're using the MICROFC-30035-SMT-TR SiPM anyways.

> Also should I use calibration in Gamma MCA app to set it to known sources?

Yes.

Phoenix1747, 2023-01-21:
Closing this as your serial connection issues seem to be resolved for now.

Closed 2023-01-21.

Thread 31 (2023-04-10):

Library Missing from Readme

pk-r7, 2023-04-10:
I get a compilation error from Arduino IDE. The Adafruit_SSD1306 Library is not listed but is required. Its an easy fix but just wanted to bring this to your attention.

Phoenix1747, 2023-04-10:
You're absolutely right, thanks a lot!

Closed 2023-04-10.

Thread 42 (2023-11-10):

Recommended size for scintilattion crystal?

GhostDog98, 2023-11-10:
I've identified what I believe to be a fairly decent deal for a Nal(Ti) crystal, which is 25mmx25mm.
I'd want to be able to identify isotopes with a fair amount of certainty, but I cannot find any information about how the crystal size affects the reading accuracy, apart from the obvious limitation of isotope size that I can easily sample.

Would it be simply the case that I may just need to sample my isotope for longer due to the decreased area of the crystal?
Additionally, would discoloration and spots on the crystal affect the results of my gamma spectroscopy much?

Cheers for your advice,
Ghostoverflow

NuclearPhoenixx, 2023-11-10:
> I've identified what I believe to be a fairly decent deal for a Nal(Ti) crystal, which is 25mmx25mm.
I'd want to be able to identify isotopes with a fair amount of certainty, but I cannot find any information about how the crystal size affects the reading accuracy, apart from the obvious limitation of isotope size that I can easily sample.

There is a comment on this in the hardware readme: https://github.com/OpenGammaProject/Open-Gamma-Detector/tree/main/hardware#scintillator-cyrstals

In general, try to avoid giant crystal faces with just a single SiPM coupled to it. The optical losses will be quite substantial and you'll probably get worse energy resolution. You can use a 25x25mm crystal no problem, but I'd recommend you get yourself the 2x2 SiPM array board: https://github.com/OpenGammaProject/MicroFC-SiPM-Array-Board

That way you can pretty easily get down to 8% if you assemble everything correctly.

> Would it be simply the case that I may just need to sample my isotope for longer due to the decreased area of the crystal?
Additionally, would discoloration and spots on the crystal affect the results of my gamma spectroscopy much?

Sampling longer always helps, but only to a certain degree. You can't go lower than the intrinsic energy resolution of your entire assembled system. Discoloration can, depending on the extent, significantly reduce the amount of light that reaches the SiPM and therefore also the resolution. However, if there's just a hint of yellow, it'll probably work fine to be honest. You really have to try it if you're unsure. Hope that helps.

GhostDog98, 2023-11-10:
Awesome, thank you. Just ordered my crystal!

Closed 2023-11-10.

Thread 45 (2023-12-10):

Dead Time Correction inaccurate

NuclearPhoenixx, 2023-12-10:
In some of my tests, thanks to @dc1rdb, I've discovered that the dead time corrected cps values for the energy and geiger modes deviate from each other. Geiger mode always seems to undershoot the actual value, while energy mode always overshoots a little bit. It looks to me, however, that energy mode is a lot more accurate over larger ranges of different count rates.

Sending in 20kcps from a pulse generator with a pulse duration of 5µs, shows around 22000 in energy mode and only 16500 in geiger mode. This might be related to the fact that for geiger mode the dead time only reports as 1µs or sometimes even 0µs.

I'm not sure what's causing this, it's somewhat related to how the software takes in the interrupts behind the scenes and obviously, how the dead time is measured. For now, I'll leave the dead time correction in, though, because IMO it's much better to have it than not to, even if it's not 100% accurate.

In the future, I might add a small factor to the dead time to compensate delays in the interrupt that are not measured.

NuclearPhoenixx, 2024-08-29:
Further testing will reveal if this issue still persists on the Pico 2 with the significant decrease in dead time. I will update if I have any news.

vikulin, 2025-05-18:
Have you checked the time for ADC reading step [here](https://github.com/OpenGammaProject/Open-Gamma-Detector/blob/main/software/ogd_pico/ogd_pico.ino#L1204)? I think that is the problem where the time may change sporadically.

I suggest to trigger the Raspberry Pi Pico 2's ADC without CPU intervention, utilize the Direct Memory Access (DMA) interface and a GPIO interrupt. Configure a GPIO pin to trigger the ADC conversion and link it to a DMA channel that will initiate the ADC read. The DMA channel can then store the ADC value in memory, and you can read it.

NuclearPhoenixx, 2025-05-18:
> Have you checked the elapsed time for ADC reading step [here](https://github.com/OpenGammaProject/Open-Gamma-Detector/blob/main/software/ogd_pico/ogd_pico.ino#L1204)?

Yes, of course, this time is added to the computed dead time. I think this has mostly something to do with a more or less constant overhead of the ISR getting called or something. The guys over at @OpenDosimeter did in fact add this kind of constant to the dead time and it looks like it works pretty well that way.

vikulin, 2025-05-18:
Q: Why you are attaching the interruption by **falling** not **rising** peak front in https://github.com/OpenGammaProject/Open-Gamma-Detector/blob/main/software/ogd_pico/ogd_pico.ino#L1302?

NuclearPhoenixx, 2025-05-18:
This is an easy and 100% safe way to only trigger the ADC readings when the peak and hold circuitry does not increase the peak voltage anymore. If you trigger at the rising edge, the ADC will read the voltage as soon as the peak is over the threshold, but it will likely not have settled.

NuclearPhoenixx, 2025-05-22:
What are you comparing exactly?

The `analogRead(pin)` function, without DMA or anything, has a tested throughput of 260 ksps, which equates to short of 4 µs. Because of this, most of the dead time is not actually due to the ADC reads at all, but simply the data processing happening around that.

vikulin, 2025-05-25:
I was comparing the `eventInt()` procedure with and without if-else and other boilerplate code. You're right — `readAnalog` isn't a bottleneck in this method. I'm considering a variant using a separate ADC with a built-in Sample & Hold function to eliminate all the mentioned boilerplate. In that case, the ADC could be triggered directly by a peak without CPU intervention. As a result, the ADC's digital output could be read quickly via sequential GPIO access. Of course, this sounds like a significant change and will lead a major version update.

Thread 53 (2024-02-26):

Serial2 shell commands not working

NuclearPhoenixx, 2024-02-26:
### Discussed in https://github.com/OpenGammaProject/Open-Gamma-Detector/discussions/52

<div type='discussions-op-text'>

<sup>Originally posted by **feraloid** February 26, 2024</sup>
While connecting the OpenGamma Detector to an ESP32 via the UART/Serial2 pins (H1 #9 & 10) I have run into a problem. The documentation seems to say the OGD will accept shell commands via the UART serial (Serial2) port. The data transmitted from the OGD is coming through fine on the ESP32.

When I attempt to transmit shell commands from the ESP32 to the OGD, they are apparently ignored. I've mirrored the characters typed onto the ESP32 in code via Bluetooth serial to make sure the typed characters are being received/processed by the ESP32 code. I've also switched to lower baud rates on the chance there's a weird baud rate issue.  I have tried different transmit pins off the ESP32 to make sure I didn't have a bad pin. Finally, just for completeness sake, I checked my transmit pin on the ESP32 with an oscilloscope and verified there is data coming through.

Did I misunderstand that the OGD will accept shell commands from the UART port or do I have some weird problem I have failed to find?</div>

Hardware serial commands are not working correctly.

Closed 2024-02-26.

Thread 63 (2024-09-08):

sharing of the open gamma detector

aeonSolutions, 2024-09-08:
Hi @kasbah  @NuclearPhoenixx  @ImgBotApp  @sebyon
great project!😍

I'm sharing it on my own project "Safety & health"
https://github.com/aeonSolutions/AeonLabs-Safety-Health/wiki

👍

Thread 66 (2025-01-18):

KiCad migration

vikulin, 2025-01-18:
Would you like to migrate to KiCad? I working on another project to adapt your project for photo multiplier tubes. Your schema can become an universal module for SiPM and PMT. The main objective to migrate to KiCad is a free and opensource with wide community and components support.

I made a schema and doing tracing. Sending a screenshot of the schematic:

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

NuclearPhoenixx, 2025-01-18:
Hi there, yes I've though about it. It would be the obvious choice in the world of EDAs, definitely agree with you there. If it weren't for EasyEDA I would've certainly designed everything in KiCad.

I've simply never taken the time to properly deal with it, because I didn't really see the need. I know full well that it can be problematic to use EasyEDA since it's closed source, basically web-only, and you can only access it with their account. So technically they could change things tomorrow and make everything paid access or similar.

The primary reason I keep using it frankly is the ease of use of going to LCSC, looking for parts and then importing all the schematics, models, pinouts and things with next to no effort. As well as the one-click order options for parts and PCBs. The service side of things is just very well-made.

Since I clearly don't have much experience at all with KiCad, please tell me what other benefits a migration would result in, other than the obviously better "open-sourcedness" of the files. I guess since there are many KiCad users, it would be easier for them to modify like in your case.

vikulin, 2025-01-19:
I used to be skeptical about KiCad. Main pros I saw the app supports Altium Footprints, Symbols. You would need to assign it manually because KiCad hasn't implemented support for such large DB like Celestial. As result PCB and Schema prototyping took me at most 3 days vs Altium with the same schema (your project) and conditions took me 7 days with lower quality PCB. Of course I had already built footprints before I started new prototyping in KiCad and I reused it in KiCad so the comparison was not 100% accurate. But definitely KiCad is my favorite prototyping framework summarizing all factors. As I have already said KiCad is capable to reuse all kind of footprints and symbols as Altium, EasyEDA and other. For a small and medium project as your that wouldn't be a problem to import it for each components. For larger industrial applications with multiboards and thousands components this factor perhaps has a negative impact. Ready for use large database decreases prototyping efforts in this case.

Here is a list of available footprints import:

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

vikulin, 2025-01-19:
Other factors, such as usability and practical use cases you can find in Youtube videos. There are plenty of such materials.

NuclearPhoenixx, 2025-01-21:
Okay thanks, I'll look into it. I'll change this thread to a discussion the meantime, so that others might voice their opinion too!

Closed 2025-01-21.

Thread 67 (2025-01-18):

Add Photomultiplier tubes support

vikulin, 2025-01-18:
As I have already mentioned here https://github.com/OpenGammaProject/Open-Gamma-Detector/issues/66 Photomultiplier tubes support would be greatly increase possible reproducibility. Especially for such kind of scintillation radiometers such as [СРП-68](http://rr20.ddns.net/Item.aspx?ItemId=1feacb03-f4a4-4b6e-b7fb-3121baa4ac71&Lang=En), СРП-88. There are ton of such detectors laying in peoples storages from USSR time.

NuclearPhoenixx, 2025-01-18:
Technically any input device is supported as long as the input voltage range is about 0 to 1.1 Volts max. In that case the preamp will not clip the signal and if the rising edge is not extremely fast as well, it should work just fine.

Please let me know what would qualify as "PMT support" in your opinion.

vikulin, 2025-01-18:
> Technically any input device is supported as long as the input voltage range is about 0 to 1.1 Volts max. In that case the preamp will not clip the signal and if the rising edge is not extremely fast as well, it should work just fine.
>
> Please let me know what would qualify as "PMT support" in your opinion.

PMTs require higher voltage vs SiPMs. Typical range is between 750-2000V and with very low current. Diode voltage multiplier does the job. Necessary rate 5Vx100x1.5 (x10 for a transformer, x10 for diode cascades). Also it require higher input impedance for pre-amp. I see 1k input resistor but should be 50k. I have already created main PCB and working on power supply schema for high voltage. I will send the PR in a separate Git branch containing a specific model of Photomultiplier tube.

NuclearPhoenixx, 2025-01-18:
OK, sure but how would these changes allow for compatability for both SiPMs and PMTs? You can't just simply increase the input resistor and the power supply would have to be able to provide a clean low-noise 30V too.

vikulin, 2025-01-18:
> OK, sure but how would these changes allow for compatability for both SiPMs and PMTs? You can't just simply increase the input resistor and the power supply would have to be able to provide a clean low-noise 30V too. Or am I mistaken and you want to create an alternative version for PMTs only?

Power supply feeds a PM tube only. Rest of schema would be identical except the input resistances pairing. Of course I consider PMTs only for that version.

NuclearPhoenixx, 2025-01-19:
Okay, sounds good. In that case, I think it would be actually better for you to have your own fork and maintain the PMT side of things, and I'm happy to link you in the README here if people are looking for PMT support. Because I'd not be able to take good care of it since I have yet to build and test myself a PMT setup (lol). Let me know what you think!

vikulin, 2025-01-19:
> Okay, sounds good. In that case, I think it would be actually better for you to have your own fork and maintain the PMT side of things, and I'm happy to link you in the README here if people are looking for PMT support. Because I'd not be able to take good care of it since I have yet to build and test myself a PMT setup (lol). Let me know what you think!

I suggest to hold the code in one place rather then to split it into two projects. I could maintain the separate branch which would correspond to PMT implementation. Sending PRs/MRs would be much easier across different branches in one project. Otherwise I will create a fork but you would need to fetch my git branches list manually because I'm going to separate SiPM and PMT support across different branches as I have already mentioned above. Let me know which variant works for you.

vikulin, 2025-01-21:
> Hm, I get your point. However, since I can't test it and wouldn't be of any help at all in the time being, I wouldn't love to have that in here "officially", honestly. I get tons of emails (mostly hw/sw "support" questions) that I would have to turn down or forward so this isn't really a suitable solution for me.
>
> Maybe we can compromise and you create a repo with the new hardware only and I keep maintaining the software here? Did you need any modifications on the software for the PMT support?

No, the software looks good enough. I would move the software code to a separate git module. As result every new hardware project could link it as a submodule. Also I would add CI/CD job in GitHub actions to publish a firmware once new update/release done.

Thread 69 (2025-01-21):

PCB manufacture says Gerber files contain 4 layers which isn't common and easy to produce

vikulin, 2025-01-21:
PCB manufacture says Gerber files contain 4 layers which isn't common and easy to produce. I haven't checked if that's true. They called me and saying they are not able to complete such boards because they produce only 2 layers PCBs. I'm agree, that should be changed for 2 layers design.

NuclearPhoenixx, 2025-01-21:
I won't change the design to a 4 layer PCB, because of overall noise concerns. Been there, done that... 😆

4L PCBs are quite common in today's world. Frankly, I didn't know there were manufacturers outright unable to produce 4L boards, that's amazing. Frankly, I would highly recommend switching to another manufacturer, since this does not sound confidence inspiring at all.

vikulin, 2025-01-21:
You didn't take a consideration that 4L boards are not common for a DIY PSBs and that wasn't about a certain manufacture capabilities.

vikulin, 2025-01-21:
Anyway I have already done tracing for 2L in KiCad If you are interested.

NuclearPhoenixx, 2025-01-21:
We absolutely took into account that 4L boards are not as usual for DIY as 2L boards. Before Rev 4.0, all boards had only 2 layers. However, we figured since 4L boards have become quite affordable and are getting more and more popular even for less complex projects like this, the added cost is worth the reduction in noise and more efficient component placement in regards to the layer stackup.

Closed 2025-01-21.

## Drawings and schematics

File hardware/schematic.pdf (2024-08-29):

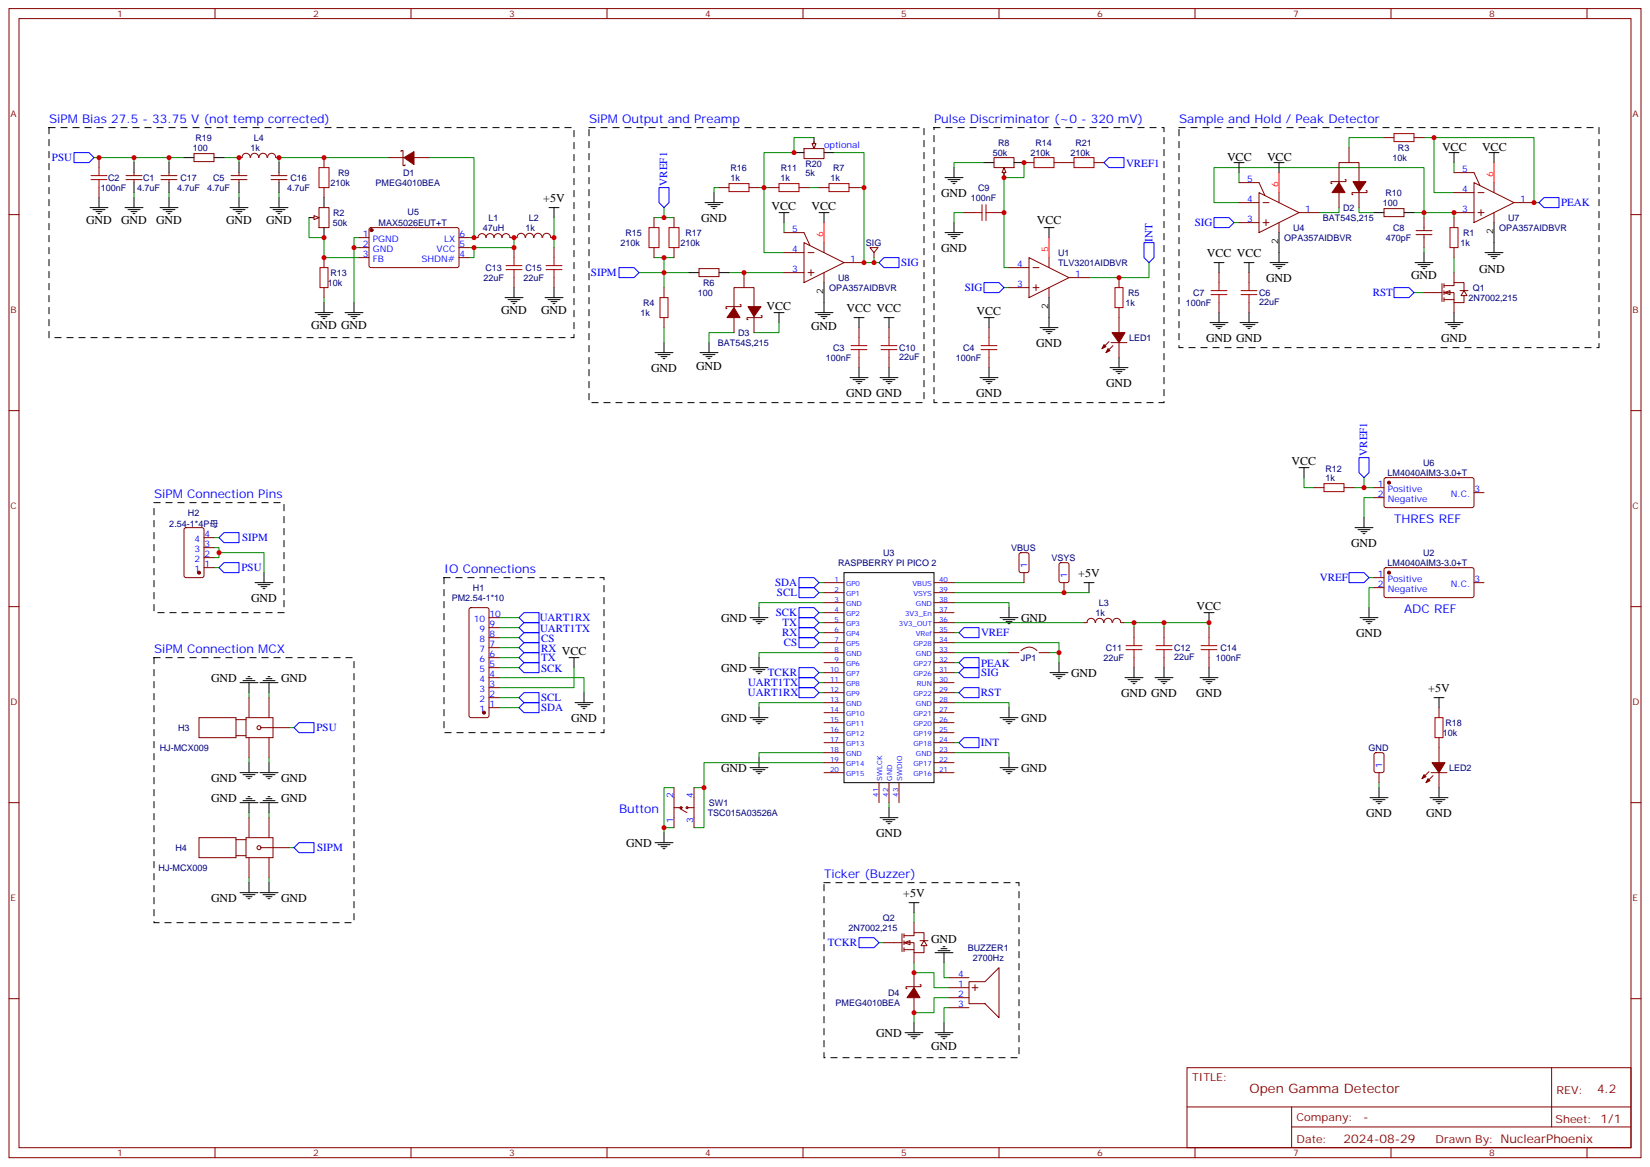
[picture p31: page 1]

SiPM Output and Preamp

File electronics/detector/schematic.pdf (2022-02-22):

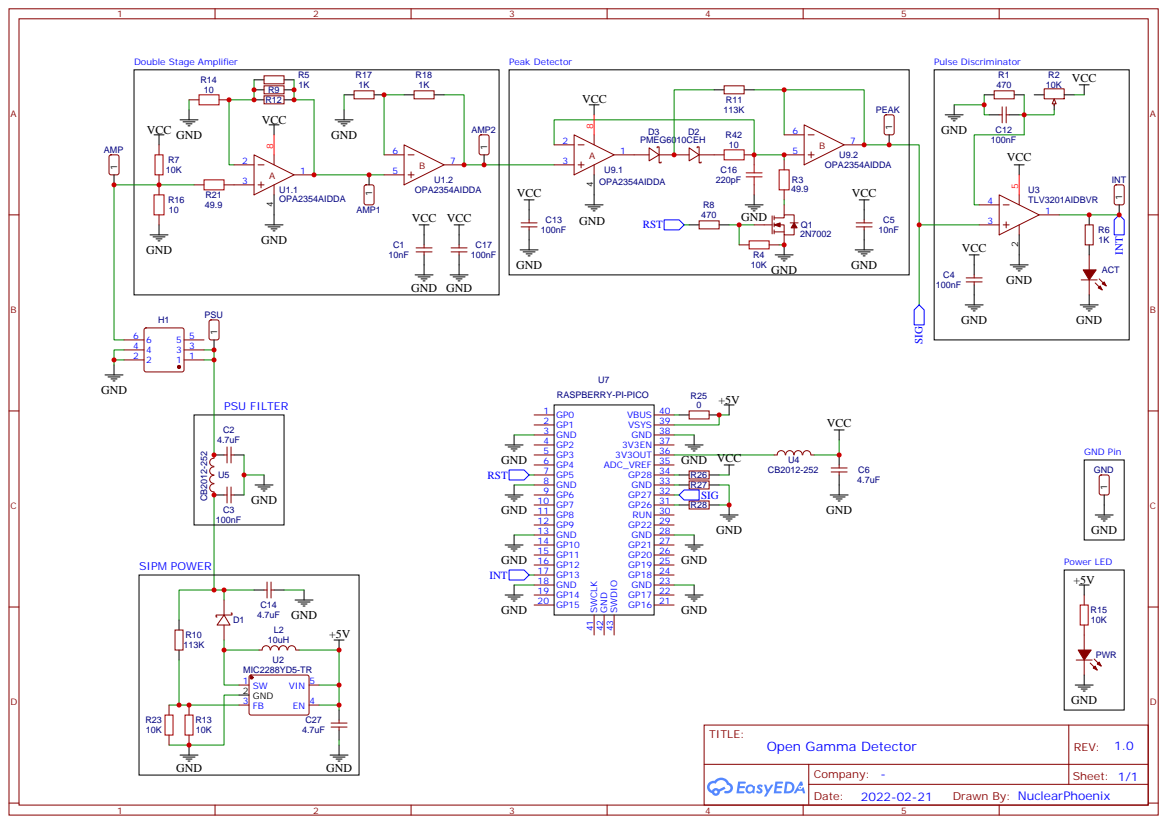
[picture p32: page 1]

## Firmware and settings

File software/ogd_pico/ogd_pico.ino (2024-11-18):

/*

  Open Gamma Detector Sketch
  Only works on the Raspberry Pi Pico 2 (!) with arduino-pico!

  Triggers on newly detected pulses and measures their energy.

  2024, NuclearPhoenix. Open Gamma Project.
  https://github.com/OpenGammaProject/Open-Gamma-Detector

  ## NOTE:
  ## Only change the highlighted USER SETTINGS below
  ## except you know exactly what you are doing!
  ## Flash with default settings and
  ##   Flash Size: "4MB (Sketch: 1MB, FS: 3MB)"
  
  
  TODO: Add cps line trend to geiger mode
  TODO: Add custom display font

  TODO: Restructure files to make ino better readable (also Baseline, Recorder and TRNG classes?)

*/

#define _TASK_SCHEDULING_OPTIONS
#define _TASK_TIMECRITICAL       // Enable monitoring scheduling overruns
#define _TASK_SLEEP_ON_IDLE_RUN  // Enable 1 ms SLEEP_IDLE powerdowns between tasks if no callback methods were invoked during the pass
#include <TaskScheduler.h>       // Periodically executes tasks

#include "hardware/vreg.h"  // Used for vreg_set_voltage
#include "Helper.h"         // Misc helper functions
#include "FS.h"             // Functions for the LittleFS filesystem

#include <SimpleShell_Enhanced.h>  // Serial Commands/Console
#include <ArduinoJson.h>           // Load and save the settings file
#include <LittleFS.h>              // Used for FS, stores the settings and debug files
#include <RunningMedian.h>         // Used to get running median and average with circular buffers

/*
    ===================
    BEGIN USER SETTINGS
    ===================
*/
// These are the default settings that can only be changed by reflashing the Pico
#define SCREEN_TYPE SCREEN_SSD1306  // Display type: Either SCREEN_SSD1306 or SCREEN_SH1106
#define SCREEN_WIDTH 128            // OLED display width, in pixels
#define SCREEN_HEIGHT 64            // OLED display height, in pixels
#define SCREEN_ADDRESS 0x3C         // See datasheet for Address; 0x3D for 128x64, 0x3C for 128x32
#define EVENT_BUFFER 50000          // Buffer this many events for Serial.print
#define BASELINE_NUM 101            // Number of measurements taken to determine the DC baseline
#define CONFIG_FILE "/config.json"  // File to store the settings
#define DEBUG_FILE "/debug.json"    // File to store some misc debug info
#define DISPLAY_REFRESH 1000        // Milliseconds between display refreshs
#define BUZZER_FREQ 2700            // Resonance frequency of the buzzer
#define AUTOSAVE_TIME 900000        // 15 Minutes in ms, time between recording autosaves
// Display Types: Select only one! One of them must be true and the other one false
#define SCREEN_SH1106 false
#define SCREEN_SSD1306 true

struct Config {
  // These are the default settings that can also be changes via the serial commands
  // Do not touch the struct itself, but only the values of the variables!
  bool ser_output = true;         // Wheter data should be Serial.println'ed
  bool geiger_mode = false;       // Measure only cps, not energy
  bool print_spectrum = false;    // Print the finishes spectrum, not just chronological events
  size_t meas_avg = 2;            // Number of meas. averaged each event, higher=longer dead time
  bool enable_display = false;    // Enable I2C Display, see settings above
  bool enable_trng = false;       // Enable the True Random Number Generator
  bool subtract_baseline = true;  // Subtract the DC bias from each pulse
  bool enable_ticker = false;     // Enable the buzzer to be used as a ticker for pulses
  size_t tick_rate = 20;          // Buzzer ticks once every tick_rate pulses

  // Do NOT modify the following operator function
  bool operator==(const Config &other) const {
    return (tick_rate == other.tick_rate && enable_ticker == other.enable_ticker && ser_output == other.ser_output && geiger_mode == other.geiger_mode && print_spectrum == other.print_spectrum && meas_avg == other.meas_avg && enable_display == other.enable_display && enable_trng == other.enable_trng && subtract_baseline == other.subtract_baseline);
  }
};
/*
    =================
    END USER SETTINGS
    =================
*/

const String FW_VERSION = "4.3.2";  // Firmware Version Code

const uint8_t GND_PIN = A2;    // GND meas pin
const uint8_t VSYS_MEAS = A3;  // VSYS/3
const uint8_t VBUS_MEAS = 24;  // VBUS Sense Pin
const uint8_t PS_PIN = 23;     // SMPS power save pin

const uint8_t AIN_PIN = A1;     // Analog input pin
const uint8_t AMP_PIN = A0;     // Preamp (baseline) meas pin
const uint8_t INT_PIN = 18;     // Signal interrupt pin
const uint8_t RST_PIN = 22;     // Peak detector MOSFET reset pin
const uint8_t LED = 25;         // Built-in LED on GP25
const uint8_t BUZZER_PIN = 7;   // Buzzer PWM pin for the ticker
const uint8_t BUTTON_PIN = 14;  // Misc button pin

const uint8_t LONG_PRESS = 10;  // Time until considered long button press

const uint8_t BUZZER_TICK = 10;     // On-time of the buzzer for a single pulse in ms
const uint16_t EVT_RESET_C = 3000;  // Number of counts after which the OLED stats will be reset
const uint16_t OUT_REFRESH = 1000;  // Milliseconds between serial data outputs

const float VREF_VOLTAGE = 3.0;             // ADC reference voltage, default is 3.0 with reference
const uint8_t ADC_RES = 12;                 // Use 12-bit ADC resolution
const uint16_t ADC_BINS = 0x01 << ADC_RES;  // Number of ADC bins

volatile uint32_t spectrum[ADC_BINS];          // Holds the output histogram (spectrum)
volatile uint32_t display_spectrum[ADC_BINS];  // Holds the display histogram (spectrum)

volatile uint16_t events[EVENT_BUFFER];  // Buffer array for single events
volatile uint32_t event_position = 0;    // Target index in events array
volatile unsigned long start_time = 0;   // Time in ms when the spectrum collection has started
volatile unsigned long last_time = 0;    // Last time the display has been refreshed
volatile uint32_t last_total = 0;        // Last total pulse count for display

const uint16_t TRNG_STORAGE_SIZE = 1024;        // Number of trng bytes stored in memory
volatile unsigned long trng_stamps[3];          // Timestamps for True Random Number Generator
volatile uint8_t random_num = 0b00000000;       // Generated random bits that form a byte together
volatile uint8_t bit_index = 0;                 // Bit index for the generated number
volatile uint8_t trng_nums[TRNG_STORAGE_SIZE];  // TRNG number output array
volatile uint16_t number_index = 0;             // Amount of saved numbers to the TRNG array
volatile size_t total_events = 0;               // Total number of all registered pulses

RunningMedian baseline(BASELINE_NUM);  // Array of a number of baseline (DC bias) measurements at the SiPM input
uint16_t current_baseline = 0;         // Median value of the input baseline voltage

uint32_t recordingDuration = 0;        // Duration of the spectrum recording in seconds
String recordingFile = "";             // Filename for the spectrum recording file
volatile bool isRecording = false;     // Currently running a recording
unsigned long recordingStartTime = 0;  // Start timestamp of the recording in ms

volatile bool adc_lock = false;  // Locks the ADC if it's currently in use

// Stores 5 * DISPLAY_REFRESH worth of "current" cps to calculate an average cps value in a ring buffer config
RunningMedian counts(5);

// Stores the last
RunningMedian dead_time(100);

// Configuration struct with all user settings
Config conf;

// Set up serial shells
CShell shell(Serial);
CShell shell1(Serial2);

// Check for the right display type
#if (SCREEN_TYPE == SCREEN_SH1106)
#include <Adafruit_SH110X.h>
#define DISPLAY_WHITE SH110X_WHITE
Adafruit_SH1106G display = Adafruit_SH1106G(SCREEN_WIDTH, SCREEN_HEIGHT, &Wire, -1);
#elif (SCREEN_TYPE == SCREEN_SSD1306)
#include <Adafruit_SSD1306.h>
#define DISPLAY_WHITE SSD1306_WHITE
Adafruit_SSD1306 display(SCREEN_WIDTH, SCREEN_HEIGHT, &Wire, -1);
#endif

// Forward declaration of callbacks
void writeDebugFileTime();
void queryButton();
void updateDisplay();
void dataOutput();
void updateBaseline();
void resetPHCircuit();
void recordCycle();

// Tasks
Task writeDebugFileTimeTask(60 * 60 * 1000, TASK_FOREVER, &writeDebugFileTime);
Task queryButtonTask(100, TASK_FOREVER, &queryButton);
Task updateDisplayTask(DISPLAY_REFRESH, TASK_FOREVER, &updateDisplay);
Task dataOutputTask(OUT_REFRESH, TASK_FOREVER, &dataOutput);
Task updateBaselineTask(1, TASK_FOREVER, &updateBaseline);
Task resetPHCircuitTask(1, TASK_FOREVER, &resetPHCircuit);
Task recordCycleTask(60000, 0, &recordCycle);

// Scheduler
Scheduler schedule;

// Declare CommandFunction type
using CommandFunction = void (*)(String *);

// Define a struct for command information
struct CommandInfo {
  CommandFunction function;
  const char *name;
  const char *description;
};


void clearSpectrum() {
  for (size_t i = 0; i < ADC_BINS; i++) {
    spectrum[i] = 0;
  }
}


void clearSpectrumDisplay() {
  for (size_t i = 0; i < ADC_BINS; i++) {
    display_spectrum[i] = 0;
  }
  start_time = millis();  // Spectrum pulse collection has started
  last_time = millis();
  last_total = 0;  // Remove old values
}


void resetSampleHold(uint8_t time = 2) {  // Reset sample and hold circuit
  digitalWriteFast(RST_PIN, HIGH);
  delayMicroseconds(time);  // Discharge for (default) 2 µs -> ~99% discharge time for 1 kOhm and 470 pF
  digitalWriteFast(RST_PIN, LOW);
}


void resetPHCircuit() {
  if (!adc_lock) {
    adc_lock = true;    // Disable interrupt ADC measurements while resetting
    resetSampleHold();  // Periodically reset the S&H/P&H circuit
    adc_lock = false;
  }
  // TODO: Check if adc was locked and decrease interval to compensate
}


void queryButton() {
  static uint16_t pressed = 0;
  static bool press_lock = false;

  if (digitalRead(BUTTON_PIN) == LOW) {
    pressed++;

    if (pressed >= LONG_PRESS && !press_lock) {
      /*
        Long Press: Toggle Buzzer
      */
      conf.enable_ticker = !conf.enable_ticker;

      println(conf.enable_ticker ? "Enabled ticker output." : "Disabled ticker output.");

      updateDisplayTask.forceNextIteration();  // Update the display immediately

      saveSettings();  // Saved updated settings
      // Introduce some dead time after a button press
      // Fixes a bug that would make the buzzer go crazy
      // Idk what's going on, but it's related to the saveSettings() function
      // Maybe the flash is too slow or something
      delay(100);

      press_lock = true;
    }
  } else {
    if (pressed > 0) {
      if (pressed < LONG_PRESS) {
        /*
          Short Press: Switch Modes
        */
        conf.geiger_mode = !conf.geiger_mode;
        event_position = 0;
        clearSpectrum();
        clearSpectrumDisplay();
        resetSampleHold();

        println(conf.geiger_mode ? "Switched to geiger mode." : "Switched to energy measuring mode.");

        updateDisplayTask.forceNextIteration();  // Update the display immediately

        saveSettings();  // Saved updated settings
        // Introduce some dead time after a button press
        // Fixes a bug that would make the buzzer go crazy
        // Idk what's going on, but it's related to the saveSettings() function
        // Maybe the flash is too slow or something
        delay(100);
      }
    }

    pressed = 0;
    press_lock = false;
  }

  if (BOOTSEL) {
    rp2040.rebootToBootloader();
  }

  rp2040.wdt_reset();  // Reset watchdog, everything is fine
}


void dataOutput() {
  // MAYBE ONLY START TASK IF OUTPUT IS ENABLED?
  if (conf.ser_output) {
    if (Serial || Serial2) {
      if (conf.print_spectrum) {
        for (uint16_t index = 0; index < ADC_BINS; index++) {
          cleanPrint(String(spectrum[index]) + ";");
          //spectrum[index] = 0; // Uncomment for differential histogram
        }
        cleanPrintln();
      } else if (event_position > 0 && event_position <= EVENT_BUFFER) {
        for (uint16_t index = 0; index < event_position; index++) {
          cleanPrint(String(events[index]) + ";");
        }
        cleanPrintln();
      }
    }

    event_position = 0;
  }

  // MAYBE SEPARATE TRNG AND SERIAL OUTPUT TASKS?
  if (conf.enable_trng) {
    if (Serial || Serial2) {
      for (size_t i = 0; i < number_index; i++) {
        cleanPrint(trng_nums[i], DEC);
        cleanPrintln(";");
      }
      number_index = 0;
    }
  }
}


void updateBaseline() {
  static uint8_t baseline_done = 0;

  // Compute the median DC baseline to subtract from each pulse
  if (conf.subtract_baseline) {
    if (!adc_lock) {
      adc_lock = true;  // Disable interrupt ADC measurements while resetting
      baseline.add(analogRead(AIN_PIN));
      adc_lock = false;

      baseline_done++;

      if (baseline_done >= BASELINE_NUM) {
        current_baseline = round(baseline.getMedian());  // Take the median value

        baseline_done = 0;
      }
    }
  }
}


float readTemp() {
  adc_lock = true;                        // Flag this, so that nothing else uses the ADC in the mean time
  delayMicroseconds(conf.meas_avg * 20);  // Wait for an already-executing interrupt
  const float temp = analogReadTemp(VREF_VOLTAGE);
  adc_lock = false;
  return temp;
}


void recordCycle() {
  static unsigned long saveTime = 0;
  static uint32_t recordingSpectrum[ADC_BINS];

  const unsigned long nowTime = millis();

  if (!isRecording) {
    isRecording = true;
    recordingStartTime = nowTime;
    saveTime = nowTime;

    // Copy original spectrum data into recordingSpectrum
    for (uint16_t i = 0; i < ADC_BINS; i++) {
      recordingSpectrum[i] = spectrum[i];
    }
  }

  isRecording = !recordCycleTask.isLastIteration();

  // Last iteration or autosave interval -> save to file
  if (!isRecording || (nowTime - saveTime >= AUTOSAVE_TIME)) {
    // Generate current recording spectrum in NPESv2 format
    JsonDocument doc;

    doc["schemaVersion"] = "NPESv2";

    JsonObject data_0 = doc["data"].add<JsonObject>();

    JsonObject data_0_deviceData = data_0["deviceData"].to<JsonObject>();
    data_0_deviceData["softwareName"] = "OGD FW " + FW_VERSION;
    data_0_deviceData["deviceName"] = "Open Gamma Detector Rev. 4";

    JsonObject data_0_resultData_energySpectrum = data_0["resultData"]["energySpectrum"].to<JsonObject>();
    data_0_resultData_energySpectrum["numberOfChannels"] = ADC_BINS;
    data_0_resultData_energySpectrum["measurementTime"] = round((nowTime - recordingStartTime) / 1000.0);

    JsonArray data_0_resultData_energySpectrum_spectrum = data_0_resultData_energySpectrum["spectrum"].to<JsonArray>();

    uint32_t sum = 0;
    for (uint16_t i = 0; i < ADC_BINS; i++) {
      const uint32_t diff = spectrum[i] - recordingSpectrum[i];
      data_0_resultData_energySpectrum_spectrum.add(diff);
      sum += diff;
    }

    data_0_resultData_energySpectrum["validPulseCount"] = sum;

    doc.shrinkToFit();

    File saveFile = LittleFS.open(DATA_DIR_PATH + recordingFile, "w");  // Open read and write
    if (!saveFile) {
      println("Could not create file to save recording data!", true);
    }
    serializeJson(doc, saveFile);
    saveFile.close();

    saveTime = nowTime;
  }
}

/*
  BEGIN SERIAL COMMANDS
*/
void recordStart(String *args) {
  String command = *args;
  command.replace("record start", "");
  command.trim();

  if (isRecording) {
    println("Device is already recording! You must stop the current recording to start a new one.", true);
    return;
  }

  // Check and warn if the filesystem is almost full
  if (getUsedPercentageFS() > 90) {
    println("WARNING: Filesystem is almost full. Check if you have enough space for an additional recording.", true);
    println("The device might not be able to save the data. Delete old files if you need more free space.", true);
  }

  // Find the position of the first space
  const int spaceChar = command.indexOf(' ');

  // Extract the command
  String timeStr = command.substring(0, spaceChar);
  timeStr.trim();
  const long time = timeStr.toInt();

  if (time <= 0) {
    println("Invalid time input '" + command + "'.", true);
    println("Time parameter must be a number > 0.", true);
    return;
  }

  String filename = command.substring(spaceChar);
  filename.trim();

  if (filename == "") {
    println("Invalid file input '" + command + "'.", true);
    println("Filename must be a string with a non-zero length.", true);
    return;
  }

  recordingFile = filename + ".json";  // Force JSON file extension because of NPESv2
  recordingDuration = time;

  println("Starting recording to file '" + recordingFile + "' for " + String(recordingDuration) + " minutes.");
  println("You can always check out the current status or stop the recording.");

  // Set task duration and start the task
  recordCycleTask.setIterations(time + 1);  // Time is in minutes, task executes every minute, so time == iterations
  recordCycleTask.enable();
}


void recordStop([[maybe_unused]] String *args) {
  if (!isRecording) {
    println("No recording is currently running.", true);
    return;
  }

  const unsigned long runTime = recordCycleTask.getRunCounter();

  recordCycleTask.setIterations(1);  // Run for one last time
  recordCycleTask.restart();         // Run immediately

  println("Stopped spectrum recording to file '" + recordingFile + "' after " + String(runTime) + " minutes.");
}


void recordStatus([[maybe_unused]] String *args) {
  if (!recordCycleTask.isEnabled()) {
    println("No recording is currently running.", true);
    print("Last recording: ", true);
    cleanPrintln(recordingFile);
    return;
  }

  const float runTime = (millis() - recordingStartTime) / 1000.0 / 60.0;

  println("Recording Status: \tRunning...");
  print("Recording File: \t");
  cleanPrintln(recordingFile);
  print("Recording Time: \t");
  cleanPrint(runTime);
  cleanPrint(" / ");
  cleanPrint(recordingDuration);
  cleanPrintln(" minutes");
  print("Progress: \t\t");
  cleanPrint(runTime / recordingDuration * 100.0);
  cleanPrintln(" %");
}


void setSerialOutMode(String *args) {
  String command = *args;
  command.replace("set out", "");
  command.trim();

  if (command == "spectrum") {
    conf.ser_output = true;
    conf.print_spectrum = true;
    println("Set serial output mode to spectrum histogram.");
  } else if (command == "events") {
    conf.ser_output = true;
    conf.print_spectrum = false;
    println("Set serial output mode to events.");
  } else if (command == "off") {
    conf.ser_output = false;
    conf.print_spectrum = false;
    println("Disabled serial outputs.");
  } else {
    println("Invalid input '" + command + "'.", true);
    println("Must be 'spectrum', 'events' or 'off'.", true);
    return;
  }
  saveSettings();
}


void toggleDisplay(String *args) {
  String command = *args;
  command.replace("set display", "");
  command.trim();

  if (command == "on") {
    conf.enable_display = true;
    println("Enabled display output. You might need to reboot the device.");
  } else if (command == "off") {
    conf.enable_display = false;
    println("Disabled display output. You might need to reboot the device.");
  } else {
    println("Invalid input '" + command + "'.", true);
    println("Must be 'on' or 'off'.", true);
    return;
  }
  saveSettings();
}


void toggleTicker(String *args) {
  String command = *args;
  command.replace("set ticker", "");
  command.trim();

  if (command == "on") {
    conf.enable_ticker = true;
    println("Enabled ticker output.");
  } else if (command == "off") {
    conf.enable_ticker = false;
    println("Disabled ticker output.");
  } else {
    println("Invalid input '" + command + "'.", true);
    println("Must be 'on' or 'off'.", true);
    return;
  }
  saveSettings();
}


void setTickerRate(String *args) {
  String command = *args;
  command.replace("set tickrate", "");
  command.trim();

  const long number = command.toInt();

  if (number > 0) {
    conf.tick_rate = number;
    println("Set ticker rate to " + String(number) + ".");
    saveSettings();
  } else {
    println("Invalid input '" + command + "'.", true);
    println("Parameter must be a number > 0.", true);
  }
}


void setMode(String *args) {
  String command = *args;
  command.replace("set mode", "");
  command.trim();

  if (command == "geiger") {
    conf.geiger_mode = true;
    event_position = 0;
    println("Enabled geiger mode.");
  } else if (command == "energy") {
    conf.geiger_mode = false;
    event_position = 0;
    println("Enabled energy measuring mode.");
  } else {
    println("Invalid input '" + command + "'.", true);
    println("Must be 'geiger' or 'energy'.", true);
    return;
  }
  resetSampleHold();
  saveSettings();
}


void toggleTRNG(String *args) {
  String command = *args;
  command.replace("set trng", "");
  command.trim();

  if (command == "on") {
    conf.enable_trng = true;
    println("Enabled True Random Number Generator output.");
  } else if (command == "off") {
    conf.enable_trng = false;
    println("Disabled True Random Number Generator output.");
  } else {
    println("Invalid input '" + command + "'.", true);
    println("Must be 'on' or 'off'.", true);
    return;
  }
  saveSettings();
}


void toggleBaseline(String *args) {
  String command = *args;
  command.replace("set baseline", "");
  command.trim();

  if (command == "on") {
    conf.subtract_baseline = true;
    println("Enabled automatic DC bias subtraction.");
  } else if (command == "off") {
    conf.subtract_baseline = false;
    current_baseline = 0;  // Reset baseline back to zero
    println("Disabled automatic DC bias subtraction.");
  } else {
    println("Invalid input '" + command + "'.", true);
    println("Must be 'on' or 'off'.", true);
    return;
  }
  saveSettings();
}
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
void loop() {
  // Do nothing here

  __wfi();  // Wait for interrupt
}


void loop1() {
  schedule.execute();

  delay(1);  // Wait for 1 ms, slightly reduces power consumption
}
/*
  END LOOP FUNCTIONS
*/

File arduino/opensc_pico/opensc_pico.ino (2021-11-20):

/*
   Scintillation Counter Sketch
   Adapted to be used with the Raspberry Pi Pico
   Simple detector sketch returning the pulse heights

   ADC Settings:
    - Standard is 12-bit, 4096
*/

#include <PicoAnalogCorrection.h> // Analog Calibration

const uint8_t GND_PIN = A0; // GND meas pin
const uint8_t VCC_PIN = A2; // VCC meas pin
const uint8_t VSYS_MEAS = A3; // VSYS/3
const uint8_t VBUS_MEAS = 24; // VBUS Sense Pin

const uint8_t AIN_PIN = A1; // Analog input pin
const uint8_t INT_PIN = 13; // Signal interrupt pin
const uint8_t RST_PIN = 5; // Peak detector MOSFET reset pin
const uint8_t LED = 25; // LED on GP25

PicoAnalogCorrection pico; // (10,4095)

void event_int() {
  digitalWrite(LED, HIGH); // Activity LED

  uint16_t m = pico.analogCRead(AIN_PIN,5); // Average 5 corrected measurements
  
  digitalWrite(RST_PIN, HIGH); // Reset peak detector
  delayMicroseconds(1);
  digitalWrite(RST_PIN, LOW);

  //Serial.println(3.3 / 4095 * m, 3);
  Serial.println(m);
  
  digitalWrite(LED, LOW);
}

void setup() {
  pinMode(PS_PIN, OUTPUT);
  digitalWrite(PS_PIN, LOW); // Enable Power-Saving
  
  pinMode(GND_PIN, INPUT);
  pinMode(VCC_PIN, INPUT);
  pinMode(VSYS_MEAS, INPUT);
  pinMode(VBUS_MEAS, INPUT);
}

void setup1() {
  pinMode(INT_PIN, INPUT);
  pinMode(RST_PIN, OUTPUT);
  pinMode(AIN_PIN, INPUT);
  pinMode(LED, OUTPUT);

  attachInterrupt(digitalPinToInterrupt(INT_PIN), event_int, HIGH);

  Serial.begin();
  while(!Serial) {
    ; // Wait for Serial
  }

  //pico.calibrateAdc(GND_PIN, VCC_PIN, 5000);
  //Serial.print("Offset: ");
  //pico.returnCalibrationValues();
}

void loop() {
  /*
  digitalWrite(PS_PIN, HIGH); // Disable Power Save For Better Noise
  Serial.print("Temperature: ");
  Serial.println(analogReadTemp(),1);
  digitalWrite(PS_PIN, LOW); // Re-Enable Power Saving
  
  Serial.print("Supply Voltage: ");
  Serial.println(3*pico.analogCRead(VSYS_MEAS)*3.3/4095,3);
  
  Serial.print("USB Connection: ");
  Serial.println(digitalRead(VBUS_MEAS));
  Serial.println();
  */
  delay(1000);
}

void loop1() {
  // Do not use, because interrupts run on this core!
}

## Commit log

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2021-12-04 [ImgBot] Optimize images
    *Total -- 119.67kb -> 82.81kb (30.8%)
    /docs/lu-176.png -- 70.65kb -> 42.60kb (39.7%)
    /docs/flow.drawio.png -- 49.01kb -> 40.21kb (17.96%)
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2022-02-23 [ImgBot] Optimize images
    *Total -- 320.89kb -> 171.71kb (46.49%)
    /docs/am-241.png -- 56.62kb -> 23.46kb (58.57%)
    /docs/pcb_back.png -- 59.97kb -> 32.17kb (46.35%)
    /docs/lu-176.png -- 78.05kb -> 44.23kb (43.34%)
    /docs/pcb_front.png -- 126.26kb -> 71.85kb (43.09%)
2022-02-23 [ImgBot] Optimize images
    /docs/flow.drawio.png -- 35.64kb -> 12.09kb (66.08%)
2022-02-23 remove gitignore
    [BOM.csv]
2022-02-25 update pico-analog-correction
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2022-05-07 new SiPM carrier board!
    [BOM.csv]
2022-05-16 remove SiPM carrier hardware
    moved to https://github.com/Open-Gamma-Project/SiPM-Carrier-Board
    [BOM.csv]
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2022-07-03 unzip gerber
    [Drill_NPTH_Through.DRL, Drill_PTH_Through.DRL, Gerber_BoardOutlineLayer.GKO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]
2022-07-03 Use UTF-8 encoding on BOM.csv
    Kitspace can't deal with UTF-16 BOMs yet
    [BOM.csv]
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2022-07-05 board revision 2
    [BOM.csv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]
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2022-07-05 [ImgBot] Optimize images
    *Total -- 273.98kb -> 140.26kb (48.81%)
    /docs/flow.drawio.png -- 33.33kb -> 10.44kb (68.69%)
    /docs/pcb_back.png -- 48.30kb -> 22.79kb (52.81%)
    /docs/pcb_front.png -- 126.35kb -> 69.95kb (44.64%)
    /docs/lu-176.png -- 65.99kb -> 37.08kb (43.81%)
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2022-08-18 version 2.1.0
    changelog:
    - remove unused Arduino Pico Analog Correction lib
    - add auto resets of the S&H circuit to help with 50 HZ mains
    interference when not shielded
    - small misc changes
2022-08-19 slight revision changes
    Changelog:
    - Change inductor orientation for best EMI
    - R3 is now 1k! This fixes an old issue with noise at low energies
    - "Optional" parts markings in the schematic
    - New spectra
    - New images
    - Add note on shielding
    - Increase size of Open Hardware logo on PCB
    - Add voltage reference to BOM
    [BOM.csv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]
2022-08-20 [ImgBot] Optimize images
    *Total -- 1,750.96kb -> 1,487.58kb (15.04%)
    /docs/pcb_back.png -- 49.47kb -> 23.58kb (52.33%)
    /docs/am-241.png -- 47.63kb -> 22.81kb (52.11%)
    /docs/bg.png -- 52.63kb -> 28.50kb (45.84%)
    /docs/pcb_front.png -- 114.34kb -> 61.98kb (45.79%)
    /docs/glaze.png -- 58.67kb -> 33.50kb (42.9%)
    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
2022-08-24 firmware v2.2.0
    - persistent settings: saving and loading from flash
    - add command to reset the settings
    - more detailed serial command interactions
    - fix temperature readings
    - add setting for the meas averaging
    - add more metadata to "read info" call
    - add filesystem info call
    - add command to reset built-in histogram spectrum
    - add command to reboot the device
    - improved documentation
    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
2022-11-21 add 3D print case files
    [Case_Body_USB-B.STL, Case_Body_micro-USB.STL, Case_Cover.STL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]
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2022-11-27 Firmware update 2.4.0
    - Add True Random Number Generator.
    - Add function to read settings.
    - Move meta-data reading (like temperature, Vsys, etc.) to "read info"
    command.
2022-12-01 add reduced height versions
    [Case_Body_ReducedHeight_USB-B.STL, Case_Body_ReducedHeight_micro-USB.STL]
2022-12-30 misc update FW 2.5.2
    Not much changed, however, due to an arduino-pico update, this sketch is smaller in size and also the ADC speed is a bit higher now, yay!
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2023-02-19 Fix display crashes
    Problem was the event_int function was possibly using the ADC _while_ the temp reading was going and this crashed the device.
2023-02-19 switch to bool
    Programmed too much in TS LOL
2023-03-08 hardware revision 3
    [BOM.csv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]
2023-04-19 update OSHWA cert
    [Drill_NPTH_Through.DRL, Drill_PTH_Through.DRL, Drill_PTH_Through_Via.DRL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]
2023-04-19 [ImgBot] Optimize images
    *Total -- 3,574.95kb -> 3,155.38kb (11.74%)
    /docs/pcb_back.png -- 58.65kb -> 29.79kb (49.2%)
    /docs/pcb_front.png -- 109.66kb -> 58.35kb (46.79%)
    /docs/am-241.png -- 52.39kb -> 28.76kb (45.11%)
    /docs/bg.png -- 57.18kb -> 32.95kb (42.39%)
    /docs/glaze.png -- 63.96kb -> 38.20kb (40.27%)
    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
2023-04-21 Added more infomation on Index-Mathing Materials for purchase.
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2023-05-15 add ticker feature
    also add debug info such as power-on hours and power cycles
2023-06-07 [ImgBot] Optimize images
    /docs/flow.drawio.svg -- 155.78kb -> 127.93kb (17.88%)
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2023-08-19 add new case
    [Case_Body_ReducedHeight_USB-B.STL, Case_Body_ReducedHeight_micro-USB.STL, Case_Body_USB-B.STL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]
2023-09-13 [ImgBot] Optimize images
    *Total -- 14,391.29kb -> 13,527.97kb (6%)
    /docs/mushrooms.png -- 74.44kb -> 46.51kb (37.53%)
    /docs/oshw.svg -- 13.54kb -> 12.54kb (7.39%)
    /docs/enclosure_empty2.jpg -- 3,407.81kb -> 3,201.28kb (6.06%)
    /docs/enclosure_panel1.jpg -- 3,524.37kb -> 3,311.37kb (6.04%)
    /docs/enclosure_empty1.jpg -- 3,478.40kb -> 3,268.17kb (6.04%)
    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
2023-11-27 add rev 4 hw files
    [BOM.csv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]
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2023-12-02 fix wrong state PS_PIN
    [ogd_pico.ino]
2023-12-03 [ImgBot] Optimize images
    *Total -- 666.42kb -> 400.29kb (39.93%)
    /docs/pcb_back.png -- 81.95kb -> 44.19kb (46.08%)
    /docs/am-241.png -- 47.93kb -> 26.76kb (44.18%)
    /docs/pcb_front.png -- 117.35kb -> 67.66kb (42.34%)
    /docs/bg.png -- 53.93kb -> 31.23kb (42.09%)
    /docs/lu-176.png -- 69.06kb -> 41.59kb (39.77%)
    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
2023-12-09 update OSHWA mark
    [Drill_NPTH_Through.DRL, Drill_PTH_Through.DRL, Drill_PTH_Through_Via.DRL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]
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2024-01-16 [ImgBot] Optimize images
    *Total -- 1,241.80kb -> 1,043.24kb (15.99%)
    /docs/pcb_back.png -- 80.57kb -> 42.92kb (46.73%)
    /docs/bg.png -- 58.20kb -> 34.59kb (40.57%)
    /docs/lu-176-advanced.png -- 57.14kb -> 34.80kb (39.09%)
    /docs/mushrooms.png -- 70.65kb -> 43.78kb (38.04%)
    /docs/mushrooms-advanced.png -- 57.21kb -> 35.76kb (37.49%)
    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
2024-03-29 add rev 4.1 files
    [BOM.csv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]
2024-03-29 [ImgBot] Optimize images
    *Total -- 341.75kb -> 199.00kb (41.77%)
    /docs/pcb_back.png -- 81.21kb -> 43.25kb (46.74%)
    /docs/pcb_front.png -- 131.72kb -> 74.37kb (43.54%)
    /docs/controls.png -- 128.82kb -> 81.38kb (36.82%)
2024-06-05 add FW 4.2.2
    No changes, only updated arduino-pico for the latest LittleFS (file system) version.
2024-08-29 update HW files
    [BOM.csv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]
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2024-10-29 update firmware to 4.3.1
    - add reset reason to info screen
    - updated to latest arduino-pico
    [ogd_pico.ino]
2024-11-18 update firmware to 4.3.2
    - minor fixes to the TRNG code
    - reduce overlock image frequency to 225
    - update ArduinoJSON and arduino-pico
    - Disable unused Serial1 (UART0)
    [ogd_pico.ino]
2025-02-22 add pick and place file
    [PickAndPlace_PCB.csv]
2025-11-10 fix hardware files
    Looks like it didn't work in JLCPCB...
    [BOM.csv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]
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2025-11-10 fix BOM UTF-8
    [BOM.csv]
